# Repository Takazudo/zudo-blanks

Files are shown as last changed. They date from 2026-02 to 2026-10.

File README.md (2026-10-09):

# zudo-blanks

Blank panel PCB designs for modular synthesizers. These are simple PCBs with no electronic components - just blank panels with mounting holes and optional silkscreen artwork.

## Overview

This project contains KiCad PCB designs for blank panels in various HP widths for Eurorack format modular synthesizers. The panels are designed for manufacturing via JLCPCB.

## Documentation

- **Documentation site**: Built with zudo-doc
- **Development**: `cd doc && pnpm install --frozen-lockfile && pnpm dev`
- **URL**: `http://localhost:4321/pj/zblanks/`

## Repository Structure

- `panels/` - All KiCad panel projects (one directory per panel)
- `footprints/` - Shared KiCad footprint library
- `symbols/` - KiCad symbol library (minimal)
- `artwork-resources/` - Source artwork files (AI, SVG)
- `jlcpcb-order-snapshots/` - JLCPCB order history
- `doc/` - zudo-doc documentation site
- `.github/` - GitHub Actions CI/CD

## Workflow

1. Design panel in KiCad (Edge.Cuts outline, mounting holes, silkscreen)
2. Export Gerber files
3. Order from JLCPCB

## Documentation build and deployment

The site is a static zudo-doc export in `doc/dist/`. GitHub Actions installs the pinned pnpm lockfile with Node 22, checks the docs, builds `dist/`, and stages it at `deploy-dir/pj/zblanks/` for the existing Netlify site. Production remains at https://takazudomodular.com/pj/zblanks/.

The migration used `create-zudo-doc@5.26.5` (`pnpm create zudo-doc /tmp/zblanks-zudo-doc-13 --yes --lang en --no-i18n --no-git --no-install --claude-resources`) in a scratch directory. The config keeps the starter defaults except for site identity, base path, repository-scoped Claude resources, navigation, and strict broken-link reporting. `--claude-resources` publishes project `.claude/skills`; it does not install zudo-doc's authoring skills. To roll back, revert the documentation migration commit(s) and redeploy the prior Docusaurus build.

### Published route migration

| Previous URL below `/pj/zblanks/` | New URL | Handling |
| --- | --- | --- |
| `/docs/overview` | `/docs/overview` | Preserved |
| `/docs/overview/project-overview` | same | Preserved by filename |
| `/docs/overview/file-structure` | same | Preserved |
| `/docs/how-to/*`, `/docs/misc`, `/docs/inbox` | same | Preserved |
| `/docs/{overview,how-to,misc,inbox}/index` | `/docs/{section}` | Netlify 301 redirects |
| `/` at the Netlify site root | `/pj/zblanks/` | Netlify 301 redirect |

The catalog, manufacturing, workflow, and Claude sections are new. The final catalog content is maintained with the corresponding panel work.

## Saved PCB art order candidates

[Open the four-series PCB files, previews and order ZIPs](order-packages/four-art-series/current/README.md). The saved ordinary-Git snapshot includes individual, grouped red-ten and split-red six-plus-four alternatives for Coral Vault, Fault Line, Kumiko Void wide and Spider Nest. Choose one order list; prices and factory approval remain pending.

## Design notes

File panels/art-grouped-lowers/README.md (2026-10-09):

# Historical five-series lower-board fabrication packages

For the current four-series order alternatives, use the [fresh package workflow](../../scripts/art-order/README.md). This directory and its records retain the historical five-series selection, including Woven Maze.

These native KiCad projects reproduce the five multi-board lower grids in the
frozen [fabrication policy](../../artwork-resources/pcb-art/manufacturing/policy.json).
They place the verified lower boards in sorted ID, row-major order using
translation only. Every decorative aperture stays on `Edge.Cuts`; each member's
outer rectangle is a `Dwgs.User` score boundary. The panel has one routed outer
profile and 5 mm sacrificial rails on all sides. Unoccupied grid cells contain
no duplicate artwork or drills and are declared waste.

KiCad 10's outline stitcher was sensitive to the initial primitive of three
translated decorative loops. The builder rotates those loops' serialized line
order at recorded witnesses. It retains the exact contour segment multiset;
the verifier compares every native and CAM segment against the source geometry.

| Grid | Cells | Members | Blank cells | Finished sheet (mm) |
| --- | ---: | ---: | ---: | ---: |
| white lead-free HASL | 2 × 4 | 7 | 1 | 212.6 × 387.2 |
| black ENIG | 3 × 2 | 6 | 0 | 313.9 × 198.6 |
| red lead-free HASL | 3 × 4 | 10 | 2 | 313.9 × 387.2 |
| green lead-free HASL | 2 × 2 | 4 | 0 | 212.6 × 198.6 |
| black lead-free HASL | 2 × 4 | 8 | 0 | 212.6 × 387.2 |

The three purple, yellow and blue lower boards are individually routed
singletons. The five black ENIG tops also remain standalone. Their original
native sources and verified issue 16 CAM ZIPs are referenced by the order
manifest; they are not purchased again as part of a scored sheet.

From the repository root, regenerate the native grids:

```sh
uv run --python 3.13 --with shapely==2.1.2 --with pillow \
  python artwork-resources/pcb-art/manufacturing/build_lower_panels.py
```

KiCad 10 is required for native DRC and actual Gerber/Excellon verification.
The output path below is local and ignored. The prior issue 16 path holds the
43 individually verified ZIPs, of which eight are directly orderable here.

```sh
uv run --python 3.13 --with shapely==2.1.2 --with pillow \
  python artwork-resources/pcb-art/manufacturing/verify_lower_panels.py \
  --output /tmp/zudo-blanks-issue17-panel-cam \
  --prior-output /tmp/zudo-blanks-issue16-native-cam-release \
  --kicad-cli /Applications/KiCad/KiCad.app/Contents/MacOS/kicad-cli
```

For a resumed CAM export, `--reuse-drc-reports /path/to/mapping.json` accepts
an exact mapping of all five panel IDs to `nativeBoardSha256`, `reportPath` and
`reportSha256`. The verifier checks each native hash and raw KiCad 10 JSON
report, including its source name, units, severities and clean findings,
before reusing the DRC result. Omitting this option runs fresh DRC.

The build record `lower-panels-native.json` binds source hashes, placements,
score lines and measured clearance. A `null` copper or visible-gold clearance
means that the mask-only group has no corresponding front artwork. The CAM
report binds DRC results and local
ZIP hashes. `lower-panels-order-manifest.json` accounts for 25 complete stacks
of each of the five designs: 43 selected IDs × 25 = 1,075 useful pieces,
75 blank waste cells, and 325 ordered sheets or standalone boards across
13 packages. Hardware totals are 500 screws, 3,800 spacers and 500 nuts.

The `FABRICATION.txt` in each grid ZIP instructs the fabricator to V-score all
full-length `Dwgs.User` lines (exported as `User_Drawings.gbr`), route only
the panel outer edge and decorative apertures from `Edge.Cuts`, and drill the
NPTH Excellon hits. Score lines do not
appear on silkscreen. The published scored-edge tolerance is ±0.4 mm; the
separately drilled mount centers determine stack registration.

**Pending external checks:** factory CAM approval, residual score-web depth,
perforated-sheet handling, actual color/finish availability and quote,
physical stack fit, washer/nut tolerances and usable screw length. Local DRC
and CAM evidence is not a purchase or factory acceptance.

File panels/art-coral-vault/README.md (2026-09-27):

# Coral Vault

Flowing cavities narrow unevenly with depth.

This selected home contains 8 standalone native PCB files. Filenames preserve each original board ID.

The design source and full metadata are in artwork-resources/pcb-art. The selected set uses Revision 5 geometry. These files remain editable handoff boards, not a manufacturing release.

| Layer | Original board ID | Mask | Finish |
| ---: | --- | --- | --- |
| 1 | 03-coral-vault-L01-black-enig-art | black | enig-art |
| 2 | 03-coral-vault-L02-green-mask-only | green | mask-only |
| 3 | 03-coral-vault-L03-purple-mask-only | purple | mask-only |
| 4 | 03-coral-vault-L04-gold-enig-fill | black | enig-fill |
| 5 | 03-coral-vault-L05-red-mask-only | red | mask-only |
| 6 | 03-coral-vault-L06-yellow-mask-only | yellow | mask-only |
| 7 | 03-coral-vault-L07-red-mask-only | red | mask-only |
| 8 | 03-coral-vault-L08-blue-mask-only | blue | mask-only |

The imported records include geometry and independent data checks. No KiCad application DRC/CAM, supplier acceptance, quote, physical fit, or order result is claimed.

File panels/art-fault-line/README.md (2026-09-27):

# Fault Line

An asymmetric canyon has angular and rounded cliffs.

This selected home contains 9 standalone native PCB files. Filenames preserve each original board ID.

The design source and full metadata are in artwork-resources/pcb-art. The selected set uses Revision 5 geometry. These files remain editable handoff boards, not a manufacturing release.

| Layer | Original board ID | Mask | Finish |
| ---: | --- | --- | --- |
| 1 | 13-fault-line-L01-black-enig-art | black | enig-art |
| 2 | 13-fault-line-L02-red-mask-only | red | mask-only |
| 3 | 13-fault-line-L03-black-mask-only | black | mask-only |
| 4 | 13-fault-line-L04-red-mask-only | red | mask-only |
| 5 | 13-fault-line-L05-black-mask-only | black | mask-only |
| 6 | 13-fault-line-L06-red-mask-only | red | mask-only |
| 7 | 13-fault-line-L07-black-mask-only | black | mask-only |
| 8 | 13-fault-line-L08-red-mask-only | red | mask-only |
| 9 | 13-fault-line-L09-black-mask-only | black | mask-only |

The imported records include geometry and independent data checks. No KiCad application DRC/CAM, supplier acceptance, quote, physical fit, or order result is claimed.

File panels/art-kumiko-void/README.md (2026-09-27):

# Kumiko Void — Wide

The selected set uses the expanded asanoha lattice.

This selected home contains 9 standalone native PCB files. Filenames preserve each original board ID.

The design source and full metadata are in artwork-resources/pcb-art. The selected set uses Revision 5 geometry. These files remain editable handoff boards, not a manufacturing release.

| Layer | Original board ID | Mask | Finish |
| ---: | --- | --- | --- |
| 1 | 17-kumiko-void-wide-L01-black-enig-art | black | enig-art |
| 2 | 17-kumiko-void-wide-L02-red-mask-only | red | mask-only |
| 3 | 17-kumiko-void-wide-L03-green-mask-only | green | mask-only |
| 4 | 17-kumiko-void-wide-L04-black-enig-art | black | enig-art |
| 5 | 17-kumiko-void-wide-L05-red-mask-only | red | mask-only |
| 6 | 17-kumiko-void-wide-L06-green-mask-only | green | mask-only |
| 7 | 17-kumiko-void-wide-L07-black-enig-art | black | enig-art |
| 8 | 17-kumiko-void-wide-L08-red-mask-only | red | mask-only |
| 9 | 17-kumiko-void-wide-L09-green-mask-only | green | mask-only |

The imported records include geometry and independent data checks. No KiCad application DRC/CAM, supplier acceptance, quote, physical fit, or order result is claimed.

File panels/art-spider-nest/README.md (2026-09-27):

# Spider Nest

An irregular web extends toward the red bottom layer.

This selected home contains 8 standalone native PCB files. Filenames preserve each original board ID.

The design source and full metadata are in artwork-resources/pcb-art. The selected set uses Revision 5 geometry. These files remain editable handoff boards, not a manufacturing release.

| Layer | Original board ID | Mask | Finish |
| ---: | --- | --- | --- |
| 1 | 01-spider-nest-L01-black-enig-art | black | enig-art |
| 2 | 01-spider-nest-L02-white-mask-only | white | mask-only |
| 3 | 01-spider-nest-L03-gold-enig-fill | black | enig-fill |
| 4 | 01-spider-nest-L04-white-mask-only | white | mask-only |
| 5 | 01-spider-nest-L05-gold-enig-fill | black | enig-fill |
| 6 | 01-spider-nest-L06-white-mask-only | white | mask-only |
| 7 | 01-spider-nest-L07-gold-enig-fill | black | enig-fill |
| 8 | 01-spider-nest-L08-red-mask-only | red | mask-only |

The imported records include geometry and independent data checks. No KiCad application DRC/CAM, supplier acceptance, quote, physical fit, or order result is claimed.

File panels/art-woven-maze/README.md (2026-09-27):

# Woven Maze

The lower layers carry distinct maze paths.

This selected home contains 9 standalone native PCB files. Filenames preserve each original board ID.

The design source and full metadata are in artwork-resources/pcb-art. The selected set uses Revision 5 geometry. These files remain editable handoff boards, not a manufacturing release.

| Layer | Original board ID | Mask | Finish |
| ---: | --- | --- | --- |
| 1 | 18-woven-maze-L01-black-enig-art | black | enig-art |
| 2 | 18-woven-maze-L02-white-mask-only | white | mask-only |
| 3 | 18-woven-maze-L03-black-mask-only | black | mask-only |
| 4 | 18-woven-maze-L04-white-mask-only | white | mask-only |
| 5 | 18-woven-maze-L05-black-mask-only | black | mask-only |
| 6 | 18-woven-maze-L06-white-mask-only | white | mask-only |
| 7 | 18-woven-maze-L07-black-mask-only | black | mask-only |
| 8 | 18-woven-maze-L08-white-mask-only | white | mask-only |
| 9 | 18-woven-maze-L09-black-mask-only | black | mask-only |

The imported records include geometry and independent data checks. No KiCad application DRC/CAM, supplier acceptance, quote, physical fit, or order result is claimed.

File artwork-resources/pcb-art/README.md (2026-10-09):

# PCB Art Source and Revision 5 Handoff

This directory contains the retained source, immutable revision references, compact review evidence, and regeneration tools for the five layered 20HP PCB art panels. The 52 original native board IDs are preserved in pcb/manifest.json and pcb/manifest.csv.

## Current four-series order files

[Open saved KiCad boards, CAM previews and order ZIPs](../../order-packages/four-art-series/current/README.md). This ordinary-Git snapshot preserves the three verified four-series alternatives from PR #24. The source/history below also includes Woven Maze and standard Kumiko; those are excluded from the saved four-series order lists.

## Panel homes

- panels/art-spider-nest contains the selected eight-board Spider Nest set.
- panels/art-coral-vault contains the selected eight-board Coral Vault set.
- panels/art-fault-line contains the selected nine-board Fault Line set.
- panels/art-kumiko-void contains the selected nine-board wide Kumiko set. Its alternatives/standard directory holds all nine standard Kumiko boards as a complete alternative.
- panels/art-woven-maze contains the selected nine-board Woven Maze set.

The default five-design set is 43 boards: 11 ENIG boards and 32 mask-only boards. The nine standard Kumiko boards are a replacement set, not an additional stack. Use the original board IDs from the manifest when referring to any layer.

## Retained source

- preview-source/src and preview-source/scripts generate the canonical Revision 5 geometry and offline 3D viewer.
- preview-source/assets/geometry.json is the current millimetre geometry input. reference-revision3.json and reference-revision4.json are immutable comparison inputs.
- resources/images, resources/reference, and resources/manufacturing-review retain the curated reference and review images once.
- resources/order retains the draft quantity and hardware inputs. Supplier quantities are blank.
- docs-overlay/src/content/docs retains the curated English documentation source. Its public directory is generated during a site migration and is not copied here.
- tools and validation retain the source and compact records needed for local review. The import and geometry-source checks are summarized in validation/import-review.md.
- SOURCE_RESOURCE_MANIFEST.json and SOURCE_SHA256SUMS.txt retain the incoming bundle inventory and checksums. IMPORT_MANIFEST.json maps all 944 listed source files to imported, transformed, deduplicated, or deliberately omitted repository paths.

The bundle checksum file had SHA-256 268e1c329f94d2fa55d3641e0ca32b8698e8117ac91bc8dadb58263f643d39d8. All 944 listed source files matched it at intake. Run python tools/verify_import.py to verify the committed mapping and files. The optional --source-root argument checks the original handoff tree when it is available.

## Regeneration

Python source generation uses Shapely 2.1.2. The preview source also declares Pillow 12.3.0 and npm dependencies in package-lock.json. From the repository root, create the preview environment and build the geometry and offline HTML:

    cd artwork-resources/pcb-art/preview-source
    python3 -m venv .venv
    .venv/bin/python -m pip install -r requirements.txt
    npm ci
    npm run build

To regenerate native boards and vector review outputs, run from the repository root and use a new generated destination:

    python3 artwork-resources/pcb-art/tools/export_kicad.py --input artwork-resources/pcb-art/preview-source/assets/geometry.json --output artwork-resources/pcb-art/generated/rev5-export

The exporter output is a review artifact. It does not replace the committed panel-home boards. Preview HTML, generated vectors, local dependency trees, and generated review output are ignored by Git. Regeneration commands and input hashes are recorded in the manifest and source guides.

The pinned geometry generator completed from the imported source tree. Its raw Kumiko ring ordering differs from the retained JSON, but all 52 serialized board-layer polygons compared geometrically equal. One derived aperture-count statistic changed from 33 to 32 on standard Kumiko layer 5. The imported canonical geometry and validation records were kept unchanged; see validation/import-review.md before treating a future regeneration as a byte-for-byte replacement.

## Review status

The incoming records describe geometry, S-expression, and independent data checks. This import did not run KiCad's native parser, DRC, or CAM. No factory acceptance, quote, physical-fit, or production-order claim is made. Those checks remain pending and must be recorded against the selected files and an actual fabrication process before ordering.

The viewer source includes its upstream three.js MIT notice in preview-source/THIRD_PARTY_NOTICES.txt. No additional standalone license file was present in the incoming bundle; the import manifest preserves provenance without adding a license claim.

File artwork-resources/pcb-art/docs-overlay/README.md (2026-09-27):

# Documentation Overlay Source

src/content/docs and zfb.config.ts are curated English source pages for a future documentation-site migration. The site framework, installed packages, and public asset tree are not part of this import.

The MDX pages link to image, review, and preview assets by their expected public URL. Their source files are retained once under artwork-resources/pcb-art/resources. During a separate site migration, materialize the reviewed images and generated preview HTML into that site's public/assets/pcb-art directory. Do not commit duplicate preview HTML or a second copy of the original resource images into this source bundle.

This task did not initialize, configure, or build the repository documentation site.

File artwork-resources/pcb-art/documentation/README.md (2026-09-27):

# PCB Art Handoff Documentation

The English source notes and the curated documentation pages are retained here and under docs-overlay/src/content/docs. This import does not create or migrate the repository's published documentation site.

Start with the central PCB art README and preview-source/src/CONTRACT.md. Then use the five panel-home READMEs and pcb/manifest.json to locate each original board ID, selected design, layer, color, and finish.

The source bibliography is RESEARCH_SOURCES.json. It records the reference material used by the handoff and should be rechecked before using any vendor capability or software-version detail for current work.

The geometry and native PCB files are editable drafts. The imported evidence does not include native KiCad parser, DRC, CAM, quote, physical-fit, or factory-acceptance results. Add new evidence with its tool, version, input hashes, and scope rather than changing an earlier review into a manufacturing pass.

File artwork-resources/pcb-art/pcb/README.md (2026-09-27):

# Native Board Handoff

The board files are in panels/art-spider-nest, panels/art-coral-vault, panels/art-fault-line, panels/art-kumiko-void, and panels/art-woven-maze. The selected set contains 43 boards using wide Kumiko. Nine standard Kumiko boards are in panels/art-kumiko-void/alternatives/standard and form a complete alternative.

pcb/manifest.json and pcb/manifest.csv preserve the source board IDs and provide the layer, color, finish, board path, export metadata, and original handoff path. The board paths point into repository panel homes. The default local export writes generated vectors under artwork-resources/pcb-art/generated/rev5-export/resources/vector; that generated tree is ignored.

Each file is a standalone KiCad 8+ board with embedded mechanical NPTH footprints. The files are an editable handoff, not a manufacturing release. The source reports geometry and S-expression checks, but native KiCad parsing, DRC, CAM, quote, physical fit, and factory acceptance have not been established here.

The native layers describe routed outlines and apertures on Edge.Cuts, functional holes as NPTH pads, front exposed art on F.Cu/F.Mask, and no back-side art. F.Mask is positive opening geometry. The exact export clearance choice is recorded in the manifest and generator; recheck it against the chosen supplier.

From the repository root, generate a separate review export with:

    python3 artwork-resources/pcb-art/tools/export_kicad.py --input artwork-resources/pcb-art/preview-source/assets/geometry.json --output artwork-resources/pcb-art/generated/rev5-export

The exporter protects existing outputs and accepts an explicit new output directory. It does not update the panel-home boards.

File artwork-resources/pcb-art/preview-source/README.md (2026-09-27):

# Revision 5 Geometry and Offline Viewer

This package retains the five layered PCB art designs in editable Python sources and renders the frozen Revision 5 geometry in an offline three.js viewer.

The canonical geometry is assets/geometry.json. The generator reads the design modules under src/designs, shared geometry in src/build_common.py, finish policy in src/finish_policy.py, and the immutable Revision 3 comparison snapshot in assets/reference-revision3.json. Revision 4 geometry is retained in assets/reference-revision4.json for regression comparison. Do not replace either reference snapshot with regenerated output.

The selected design family contains 43 boards, using wide Kumiko. The complete standard Kumiko alternative adds nine records, for 52 board records total. It is an alternative to the wide set, not an additional production quantity. Revision 5 adds flat copper artwork to the top of each design and Kumiko variant; it preserves the approved Revision 4 physical outlines and lower-layer artwork.

## Build

From this directory:

    npm ci
    npm run build

The viewer build verifies the approved SHA256 of `assets/geometry.json`, leaves frozen geometry and validation untouched, then writes seven self-contained HTML files under ignored `dist/`. It needs Node.js and the locked npm dependencies. The documentation site stages only `dist/index.html`: URL query parameters select each design and Kumiko variant without publishing six duplicate copies.

Regenerating design geometry is a separate, intentional source change. It needs Shapely 2.1.2 and Pillow 12.3.0:

    python3 -m venv .venv
    .venv/bin/python -m pip install -r requirements.txt
    .venv/bin/python scripts/build_geometry.py

Do not replace the frozen geometry merely to refresh the viewer. A geometry change requires a reviewed policy update and fresh native/CAM comparisons.

Do not treat geometry validation or a browser render as KiCad DRC, CAM review, a physical-fit check, or factory acceptance. The selected native and grouped board local checks are recorded under `../manufacturing/`; factory CAM, quote and physical fit remain pending.

Image references from the incoming preview-source/docs directory are retained once under ../resources/images.

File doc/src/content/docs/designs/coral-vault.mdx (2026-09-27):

---
title: "03 Coral Vault"
description: "Design intent, layer sequence, and review points."
sidebar_position: 2
---

<a href="/assets/pcb-art/previews/index.html?design=coral-vault">Open the interactive Revision 5 design preview</a>

Six large flowing cavities and four smaller openings start the view. Walls retreat by varying amounts with depth, and some cavities split as partitions appear. This avoids a repeated scaled-copy effect. The design abstracts cup, shared-wall, and radial-septum forms of colonial coral such as [Favites pentagona](https://www.coralsoftheworld.org/species_factsheets/species_factsheet_summary/favites-pentagona/); it is not a model of one organism.

The top copper spreads cup and radial motifs across the remaining face. Revision 5 adds the gold frame and hole rims. Layer 4 is the only full-gold lower layer. The top opening grew about 62.0% from Revision 3.

## Layering constraints

Combined decorative aperture area decreases with depth, and every deeper aperture remains inside the preceding opening. Hole counts may change. Keep each layer connected and ensure top openings do not extend beyond lower-board material.

## Front-to-back layers

| Layer | Color | Finish |
| ---: | --- | --- |
| 1 | Black | ENIG artwork |
| 2 | Green | Mask-only |
| 3 | Purple | Mask-only |
| 4 | Black with gold | Full ENIG |
| 5 | Red | Mask-only |
| 6 | Yellow | Mask-only |
| 7 | Red | Mask-only |
| 8 | Blue | Mask-only bottom |

## Native boards and evidence

The image below shows all selected layers from **manufacturing-adjusted native KiCad files**. The linked 3D viewer above shows Revision 5 **visual design geometry**. Small local routing and mask corrections mean the two representations are not identical.

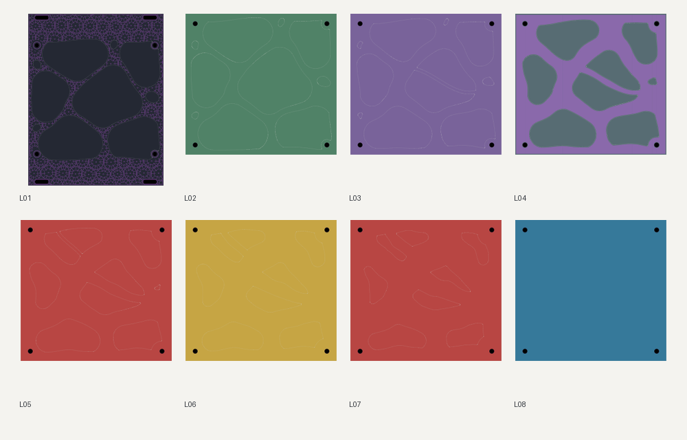
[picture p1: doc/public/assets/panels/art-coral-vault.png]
All selected native KiCad layers for coral vault


| Layer | Native KiCad board |
| ---: | --- |
| 1 | [03-coral-vault-L01-black-enig-art](https://github.com/Takazudo/zudo-blanks/blob/main/panels/art-coral-vault/03-coral-vault-L01-black-enig-art.kicad_pcb) |
| 2 | [03-coral-vault-L02-green-mask-only](https://github.com/Takazudo/zudo-blanks/blob/main/panels/art-coral-vault/03-coral-vault-L02-green-mask-only.kicad_pcb) |
| 3 | [03-coral-vault-L03-purple-mask-only](https://github.com/Takazudo/zudo-blanks/blob/main/panels/art-coral-vault/03-coral-vault-L03-purple-mask-only.kicad_pcb) |
| 4 | [03-coral-vault-L04-gold-enig-fill](https://github.com/Takazudo/zudo-blanks/blob/main/panels/art-coral-vault/03-coral-vault-L04-gold-enig-fill.kicad_pcb) |
| 5 | [03-coral-vault-L05-red-mask-only](https://github.com/Takazudo/zudo-blanks/blob/main/panels/art-coral-vault/03-coral-vault-L05-red-mask-only.kicad_pcb) |
| 6 | [03-coral-vault-L06-yellow-mask-only](https://github.com/Takazudo/zudo-blanks/blob/main/panels/art-coral-vault/03-coral-vault-L06-yellow-mask-only.kicad_pcb) |
| 7 | [03-coral-vault-L07-red-mask-only](https://github.com/Takazudo/zudo-blanks/blob/main/panels/art-coral-vault/03-coral-vault-L07-red-mask-only.kicad_pcb) |
| 8 | [03-coral-vault-L08-blue-mask-only](https://github.com/Takazudo/zudo-blanks/blob/main/panels/art-coral-vault/03-coral-vault-L08-blue-mask-only.kicad_pcb) |

[Project directory](https://github.com/Takazudo/zudo-blanks/tree/main/panels/art-coral-vault) · [Selected package/order manifest](https://github.com/Takazudo/zudo-blanks/blob/main/artwork-resources/pcb-art/manufacturing/lower-panels-order-manifest.json) · [Local native/CAM evidence](https://github.com/Takazudo/zudo-blanks/blob/main/artwork-resources/pcb-art/manufacturing/native-kicad-cam-manifest.json)

Factory CAM review, finish/color availability, quote and physical fit are pending external checks. No purchase or factory acceptance is recorded.

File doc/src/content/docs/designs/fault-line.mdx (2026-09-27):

---
title: "13 Fault Line"
description: "Design intent, layer sequence, and review points."
sidebar_position: 3
---

<a href="/assets/pcb-art/previews/index.html?design=fault-line">Open the interactive Revision 5 design preview</a>

Fault Line is a tall, asymmetric canyon. Its side ledges reach different heights; black layers have angular cliffs while red layers have worn, rounded cliffs. Retreat varies locally. The top opening grew about 38.1% from Revision 3 to Revision 4. Top copper adds terrain lines and narrow fractures, with a Revision 5 frame and hole rims. The lower eight boards are mask-only.

## Keep each layer connected

The left and right portions of every layer must remain connected through its upper and lower bridges. Splitting a layer into separate boards held together by screws would violate the one-PCB-per-layer design.

Opening area decreases with depth and remains nested, but the geometry is not a uniform offset. Keep local changes irregular and check that deep openings do not create floating PCB fragments.

## Front-to-back layers

| Layer | Color | Finish |
| ---: | --- | --- |
| 1 | Black | ENIG artwork |
| 2 | Red | Mask-only |
| 3 | Black | Mask-only |
| 4 | Red | Mask-only |
| 5 | Black | Mask-only |
| 6 | Red | Mask-only |
| 7 | Black | Mask-only |
| 8 | Red | Mask-only |
| 9 | Black | Mask-only bottom |

## Native boards and evidence

The image below shows all selected layers from **manufacturing-adjusted native KiCad files**. The linked 3D viewer above shows Revision 5 **visual design geometry**. Small local routing and mask corrections mean the two representations are not identical.

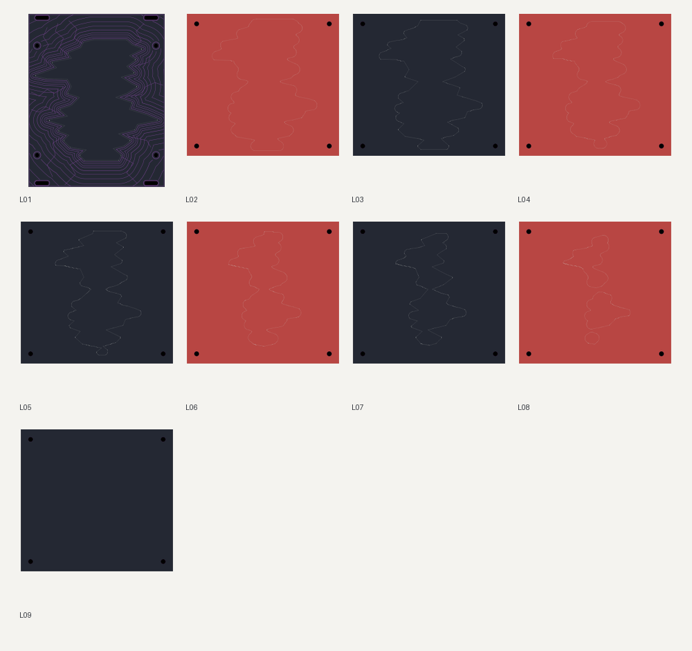
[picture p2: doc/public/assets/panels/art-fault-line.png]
All selected native KiCad layers for fault line


| Layer | Native KiCad board |
| ---: | --- |
| 1 | [13-fault-line-L01-black-enig-art](https://github.com/Takazudo/zudo-blanks/blob/main/panels/art-fault-line/13-fault-line-L01-black-enig-art.kicad_pcb) |
| 2 | [13-fault-line-L02-red-mask-only](https://github.com/Takazudo/zudo-blanks/blob/main/panels/art-fault-line/13-fault-line-L02-red-mask-only.kicad_pcb) |
| 3 | [13-fault-line-L03-black-mask-only](https://github.com/Takazudo/zudo-blanks/blob/main/panels/art-fault-line/13-fault-line-L03-black-mask-only.kicad_pcb) |
| 4 | [13-fault-line-L04-red-mask-only](https://github.com/Takazudo/zudo-blanks/blob/main/panels/art-fault-line/13-fault-line-L04-red-mask-only.kicad_pcb) |
| 5 | [13-fault-line-L05-black-mask-only](https://github.com/Takazudo/zudo-blanks/blob/main/panels/art-fault-line/13-fault-line-L05-black-mask-only.kicad_pcb) |
| 6 | [13-fault-line-L06-red-mask-only](https://github.com/Takazudo/zudo-blanks/blob/main/panels/art-fault-line/13-fault-line-L06-red-mask-only.kicad_pcb) |
| 7 | [13-fault-line-L07-black-mask-only](https://github.com/Takazudo/zudo-blanks/blob/main/panels/art-fault-line/13-fault-line-L07-black-mask-only.kicad_pcb) |
| 8 | [13-fault-line-L08-red-mask-only](https://github.com/Takazudo/zudo-blanks/blob/main/panels/art-fault-line/13-fault-line-L08-red-mask-only.kicad_pcb) |
| 9 | [13-fault-line-L09-black-mask-only](https://github.com/Takazudo/zudo-blanks/blob/main/panels/art-fault-line/13-fault-line-L09-black-mask-only.kicad_pcb) |

[Project directory](https://github.com/Takazudo/zudo-blanks/tree/main/panels/art-fault-line) · [Selected package/order manifest](https://github.com/Takazudo/zudo-blanks/blob/main/artwork-resources/pcb-art/manufacturing/lower-panels-order-manifest.json) · [Local native/CAM evidence](https://github.com/Takazudo/zudo-blanks/blob/main/artwork-resources/pcb-art/manufacturing/native-kicad-cam-manifest.json)

Factory CAM review, finish/color availability, quote and physical fit are pending external checks. No purchase or factory acceptance is recorded.

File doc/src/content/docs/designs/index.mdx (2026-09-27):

---
title: Five Layered Designs
sidebar_position: 2
---

These five projects use 43 selected native boards, with the **wide** Kumiko set. The design previews are interactive Revision 5 visual models. The compact catalog images derive from manufacturing-adjusted native boards. Read each design's complete layer table and native board links before using its files.

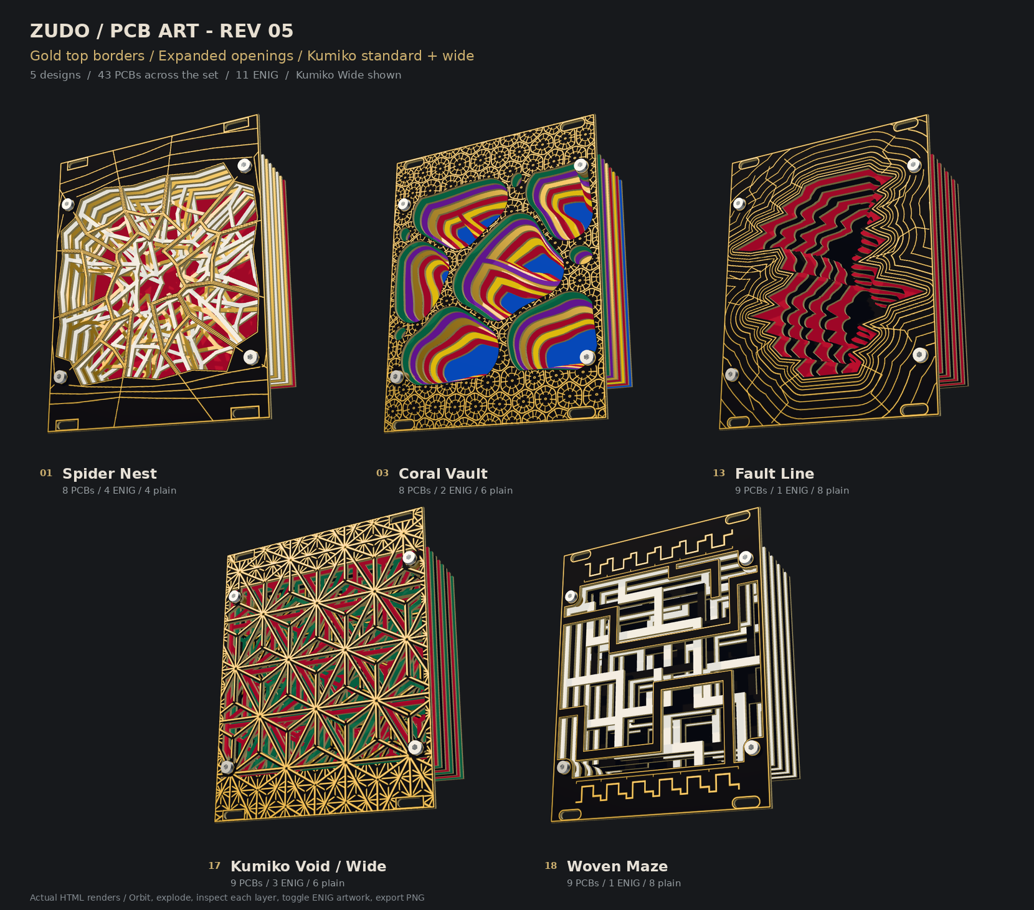
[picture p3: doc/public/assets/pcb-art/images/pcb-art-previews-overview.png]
Five Revision 5 visual concepts


<a href="/assets/pcb-art/previews/index.html">Open the interactive 3D viewer</a> · [Browse all project directories](../catalog/) · [Manufacturing status](../manufacturing/)

<CategoryNav category="designs" />

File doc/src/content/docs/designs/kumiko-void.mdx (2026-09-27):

---
title: "17 Kumiko Void"
description: "Selected wide design, standard alternative, and layer sequence."
sidebar_position: 4
---

<a href="/assets/pcb-art/previews/index.html?design=kumiko-void&amp;variant=wide">Open the interactive Revision 5 design preview</a>

Kumiko combines an asanoha lattice with black, red, and green layers. On black layers 1, 4, and 7, the flat gold and black surfaces create the visual shadow; no raised metal parts are specified. The standard option preserves the earlier opening. The selected wide option extends the same lattice toward the perimeter and increases top opening area by about 43.8% relative to standard.

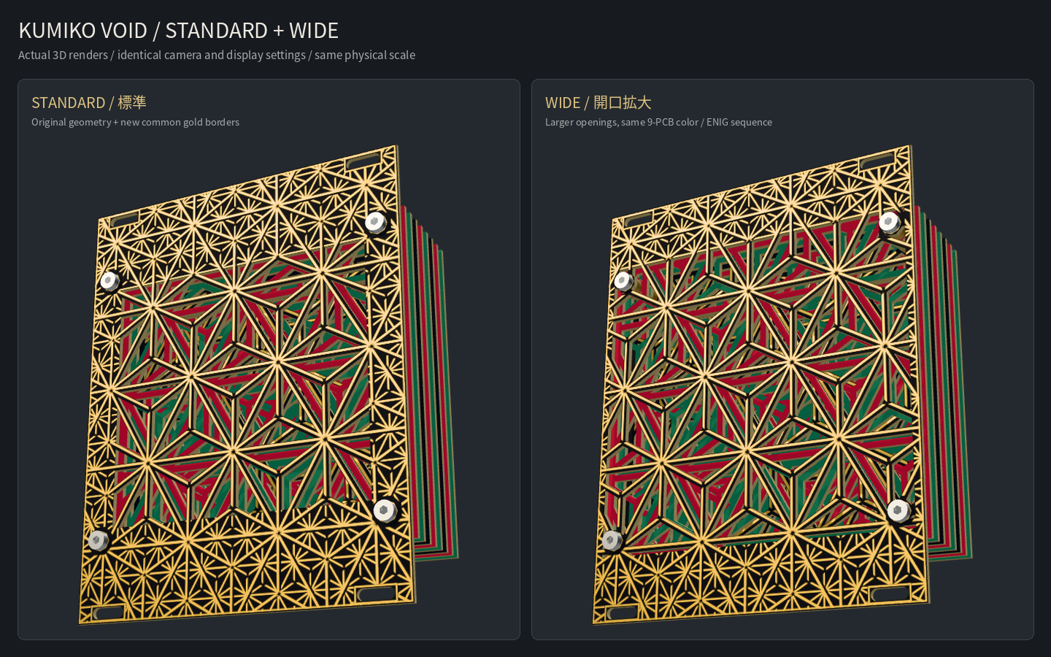
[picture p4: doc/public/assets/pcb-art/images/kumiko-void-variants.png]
Standard and wide opening comparison


<a href="/assets/pcb-art/previews/index.html?design=kumiko-void&amp;variant=standard">Standard (reference only)</a> · <a href="/assets/pcb-art/previews/index.html?design=kumiko-void&amp;variant=wide">Wide (selected)</a>

## Treat the variants as whole sets

The selected set uses wide Kumiko. Its nine standard boards are retained under panels/art-kumiko-void/alternatives/standard. Replace all nine layers together if choosing standard; do not mix layers from the two variants. Revision 5 borders are present on both tops.

## Selected wide and reference standard

The wide nine-board set was locally adapted for the chosen 1.0 mm cutter and checked in native KiCad and CAM. The standard nine-board alternative remains reference-only and was not part of the selected release checks. Do not mix variants within one stack. [Read the policy and indexed corrections](../manufacturing/kumiko-routing.mdx).

## Front-to-back layers

| Layer | Color | Finish |
| ---: | --- | --- |
| 1 | Black | ENIG artwork |
| 2 | Red | Mask-only |
| 3 | Green | Mask-only |
| 4 | Black | ENIG artwork |
| 5 | Red | Mask-only |
| 6 | Green | Mask-only |
| 7 | Black | ENIG artwork |
| 8 | Red | Mask-only |
| 9 | Green | Mask-only bottom |

## Native boards and evidence

The image below shows all selected layers from **manufacturing-adjusted native KiCad files**. The linked 3D viewer above shows Revision 5 **visual design geometry**. Small local routing and mask corrections mean the two representations are not identical.

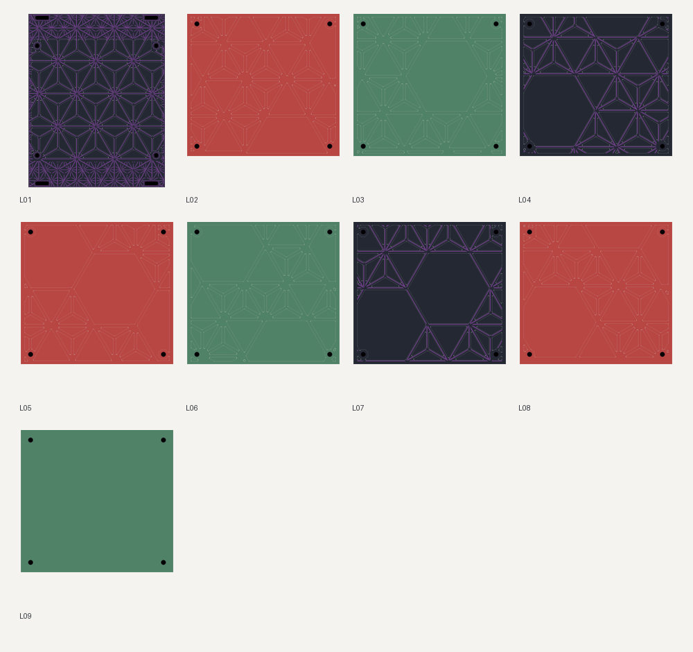
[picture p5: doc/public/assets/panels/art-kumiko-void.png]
All selected native KiCad layers for kumiko void


| Layer | Native KiCad board |
| ---: | --- |
| 1 | [17-kumiko-void-wide-L01-black-enig-art](https://github.com/Takazudo/zudo-blanks/blob/main/panels/art-kumiko-void/17-kumiko-void-wide-L01-black-enig-art.kicad_pcb) |
| 2 | [17-kumiko-void-wide-L02-red-mask-only](https://github.com/Takazudo/zudo-blanks/blob/main/panels/art-kumiko-void/17-kumiko-void-wide-L02-red-mask-only.kicad_pcb) |
| 3 | [17-kumiko-void-wide-L03-green-mask-only](https://github.com/Takazudo/zudo-blanks/blob/main/panels/art-kumiko-void/17-kumiko-void-wide-L03-green-mask-only.kicad_pcb) |
| 4 | [17-kumiko-void-wide-L04-black-enig-art](https://github.com/Takazudo/zudo-blanks/blob/main/panels/art-kumiko-void/17-kumiko-void-wide-L04-black-enig-art.kicad_pcb) |
| 5 | [17-kumiko-void-wide-L05-red-mask-only](https://github.com/Takazudo/zudo-blanks/blob/main/panels/art-kumiko-void/17-kumiko-void-wide-L05-red-mask-only.kicad_pcb) |
| 6 | [17-kumiko-void-wide-L06-green-mask-only](https://github.com/Takazudo/zudo-blanks/blob/main/panels/art-kumiko-void/17-kumiko-void-wide-L06-green-mask-only.kicad_pcb) |
| 7 | [17-kumiko-void-wide-L07-black-enig-art](https://github.com/Takazudo/zudo-blanks/blob/main/panels/art-kumiko-void/17-kumiko-void-wide-L07-black-enig-art.kicad_pcb) |
| 8 | [17-kumiko-void-wide-L08-red-mask-only](https://github.com/Takazudo/zudo-blanks/blob/main/panels/art-kumiko-void/17-kumiko-void-wide-L08-red-mask-only.kicad_pcb) |
| 9 | [17-kumiko-void-wide-L09-green-mask-only](https://github.com/Takazudo/zudo-blanks/blob/main/panels/art-kumiko-void/17-kumiko-void-wide-L09-green-mask-only.kicad_pcb) |

[Project directory](https://github.com/Takazudo/zudo-blanks/tree/main/panels/art-kumiko-void) · [Selected package/order manifest](https://github.com/Takazudo/zudo-blanks/blob/main/artwork-resources/pcb-art/manufacturing/lower-panels-order-manifest.json) · [Local native/CAM evidence](https://github.com/Takazudo/zudo-blanks/blob/main/artwork-resources/pcb-art/manufacturing/native-kicad-cam-manifest.json)

Factory CAM review, finish/color availability, quote and physical fit are pending external checks. No purchase or factory acceptance is recorded.

[Standard nine-board alternative directory — reference only](https://github.com/Takazudo/zudo-blanks/tree/main/panels/art-kumiko-void/alternatives/standard)

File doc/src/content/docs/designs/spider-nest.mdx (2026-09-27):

---
title: "01 Spider Nest"
description: "Design intent, layer sequence, and review points."
sidebar_position: 1
---

<a href="/assets/pcb-art/previews/index.html?design=spider-nest">Open the interactive Revision 5 design preview</a>

The irregular web extends close to the perimeter. Twelve main radial strands reach outward, four of them connected to mounting supports. Cross strands shift between layers, leaving a deep view toward the red bottom. The top copper follows the web outward rather than adding a uniform tiled pattern. Revision 5 adds the shared top frame and hole rims.

The top opening grew about 29.5% from Revision 3 to Revision 4; Revision 5 preserves that physical opening. White layers and the red bottom are mask-only. Layers 3, 5, and 7 show gold using black mask and exposed ENIG.

## Review points

Check thin strand connections, sharp interior corners, support necks, and visibility of the red bottom. A process adaptation should not sever strands or flatten the web by filling openings.

## Front-to-back layers

| Layer | Color | Finish |
| ---: | --- | --- |
| 1 | Black | ENIG artwork |
| 2 | White | Mask-only |
| 3 | Black with gold | Full ENIG |
| 4 | White | Mask-only |
| 5 | Black with gold | Full ENIG |
| 6 | White | Mask-only |
| 7 | Black with gold | Full ENIG |
| 8 | Red | Mask-only bottom |

## Native boards and evidence

The image below shows all selected layers from **manufacturing-adjusted native KiCad files**. The linked 3D viewer above shows Revision 5 **visual design geometry**. Small local routing and mask corrections mean the two representations are not identical.

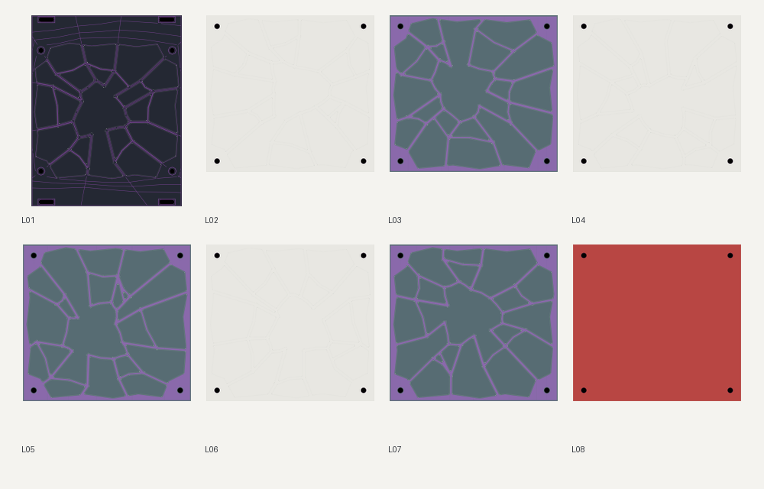
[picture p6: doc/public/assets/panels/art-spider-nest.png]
All selected native KiCad layers for spider nest


| Layer | Native KiCad board |
| ---: | --- |
| 1 | [01-spider-nest-L01-black-enig-art](https://github.com/Takazudo/zudo-blanks/blob/main/panels/art-spider-nest/01-spider-nest-L01-black-enig-art.kicad_pcb) |
| 2 | [01-spider-nest-L02-white-mask-only](https://github.com/Takazudo/zudo-blanks/blob/main/panels/art-spider-nest/01-spider-nest-L02-white-mask-only.kicad_pcb) |
| 3 | [01-spider-nest-L03-gold-enig-fill](https://github.com/Takazudo/zudo-blanks/blob/main/panels/art-spider-nest/01-spider-nest-L03-gold-enig-fill.kicad_pcb) |
| 4 | [01-spider-nest-L04-white-mask-only](https://github.com/Takazudo/zudo-blanks/blob/main/panels/art-spider-nest/01-spider-nest-L04-white-mask-only.kicad_pcb) |
| 5 | [01-spider-nest-L05-gold-enig-fill](https://github.com/Takazudo/zudo-blanks/blob/main/panels/art-spider-nest/01-spider-nest-L05-gold-enig-fill.kicad_pcb) |
| 6 | [01-spider-nest-L06-white-mask-only](https://github.com/Takazudo/zudo-blanks/blob/main/panels/art-spider-nest/01-spider-nest-L06-white-mask-only.kicad_pcb) |
| 7 | [01-spider-nest-L07-gold-enig-fill](https://github.com/Takazudo/zudo-blanks/blob/main/panels/art-spider-nest/01-spider-nest-L07-gold-enig-fill.kicad_pcb) |
| 8 | [01-spider-nest-L08-red-mask-only](https://github.com/Takazudo/zudo-blanks/blob/main/panels/art-spider-nest/01-spider-nest-L08-red-mask-only.kicad_pcb) |

[Project directory](https://github.com/Takazudo/zudo-blanks/tree/main/panels/art-spider-nest) · [Selected package/order manifest](https://github.com/Takazudo/zudo-blanks/blob/main/artwork-resources/pcb-art/manufacturing/lower-panels-order-manifest.json) · [Local native/CAM evidence](https://github.com/Takazudo/zudo-blanks/blob/main/artwork-resources/pcb-art/manufacturing/native-kicad-cam-manifest.json)

Factory CAM review, finish/color availability, quote and physical fit are pending external checks. No purchase or factory acceptance is recorded.

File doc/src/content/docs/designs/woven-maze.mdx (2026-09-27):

---
title: "18 Woven Maze"
description: "Distinct lower-layer paths, colors, and review points."
sidebar_position: 5
---

<a href="/assets/pcb-art/previews/index.html?design=woven-maze">Open the interactive Revision 5 design preview</a>

White and black layers overlap to reveal seven different maze paths below the top. Keep their routes distinct instead of reusing one shifted pattern. Revision 4 spread the routes into a larger region and increased top opening area by about 47.2%. Revision 5 adds a gold frame, hole rims, and top maze artwork. No gold pattern is added to the lower mask-only boards.

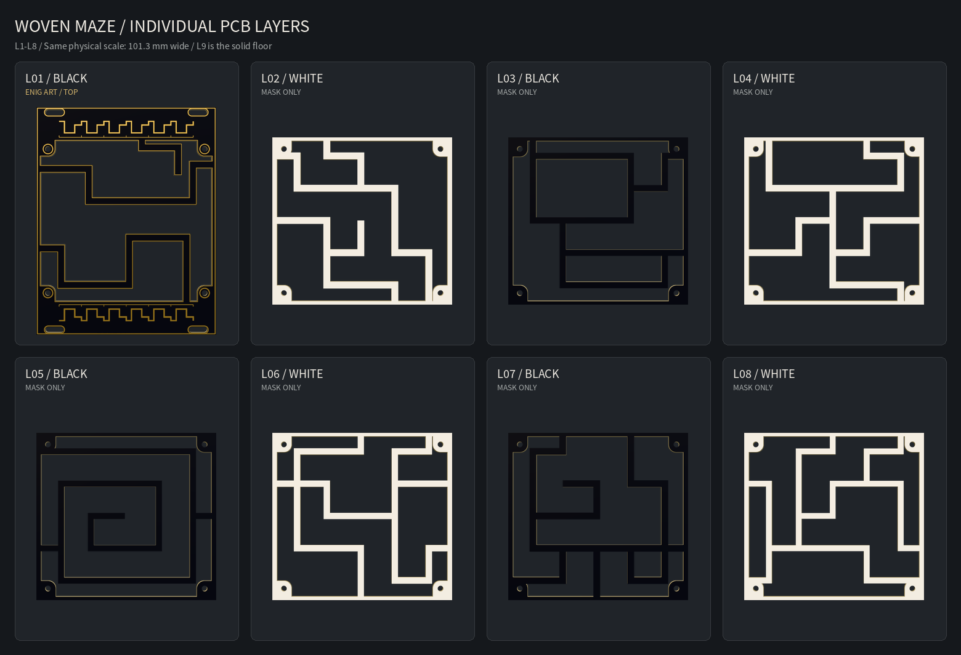
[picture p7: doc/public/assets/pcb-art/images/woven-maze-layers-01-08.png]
Top eight Woven Maze layers


## Review each layer

Use the isolated-layer preview, then return to the assembled view. Check where broad white bands hide black ones and how the windows reveal deeper routes. Every board still needs a connected perimeter and mounting supports.

## Front-to-back layers

| Layer | Color | Finish |
| ---: | --- | --- |
| 1 | Black | ENIG artwork |
| 2 | White | Mask-only |
| 3 | Black | Mask-only |
| 4 | White | Mask-only |
| 5 | Black | Mask-only |
| 6 | White | Mask-only |
| 7 | Black | Mask-only |
| 8 | White | Mask-only |
| 9 | Black | Mask-only bottom |

## Native boards and evidence

The image below shows all selected layers from **manufacturing-adjusted native KiCad files**. The linked 3D viewer above shows Revision 5 **visual design geometry**. Small local routing and mask corrections mean the two representations are not identical.

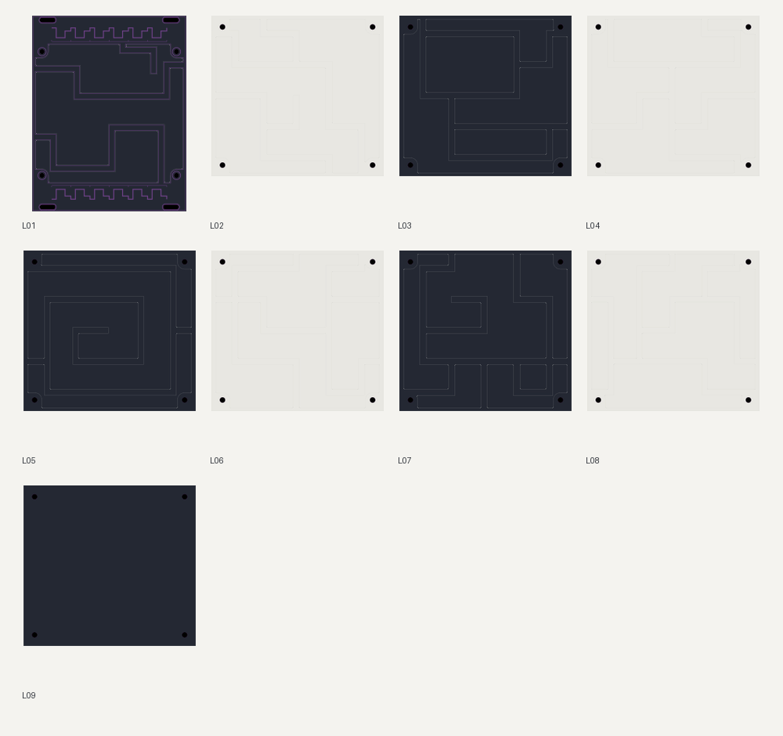
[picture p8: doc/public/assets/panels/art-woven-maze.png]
All selected native KiCad layers for woven maze


| Layer | Native KiCad board |
| ---: | --- |
| 1 | [18-woven-maze-L01-black-enig-art](https://github.com/Takazudo/zudo-blanks/blob/main/panels/art-woven-maze/18-woven-maze-L01-black-enig-art.kicad_pcb) |
| 2 | [18-woven-maze-L02-white-mask-only](https://github.com/Takazudo/zudo-blanks/blob/main/panels/art-woven-maze/18-woven-maze-L02-white-mask-only.kicad_pcb) |
| 3 | [18-woven-maze-L03-black-mask-only](https://github.com/Takazudo/zudo-blanks/blob/main/panels/art-woven-maze/18-woven-maze-L03-black-mask-only.kicad_pcb) |
| 4 | [18-woven-maze-L04-white-mask-only](https://github.com/Takazudo/zudo-blanks/blob/main/panels/art-woven-maze/18-woven-maze-L04-white-mask-only.kicad_pcb) |
| 5 | [18-woven-maze-L05-black-mask-only](https://github.com/Takazudo/zudo-blanks/blob/main/panels/art-woven-maze/18-woven-maze-L05-black-mask-only.kicad_pcb) |
| 6 | [18-woven-maze-L06-white-mask-only](https://github.com/Takazudo/zudo-blanks/blob/main/panels/art-woven-maze/18-woven-maze-L06-white-mask-only.kicad_pcb) |
| 7 | [18-woven-maze-L07-black-mask-only](https://github.com/Takazudo/zudo-blanks/blob/main/panels/art-woven-maze/18-woven-maze-L07-black-mask-only.kicad_pcb) |
| 8 | [18-woven-maze-L08-white-mask-only](https://github.com/Takazudo/zudo-blanks/blob/main/panels/art-woven-maze/18-woven-maze-L08-white-mask-only.kicad_pcb) |
| 9 | [18-woven-maze-L09-black-mask-only](https://github.com/Takazudo/zudo-blanks/blob/main/panels/art-woven-maze/18-woven-maze-L09-black-mask-only.kicad_pcb) |

[Project directory](https://github.com/Takazudo/zudo-blanks/tree/main/panels/art-woven-maze) · [Selected package/order manifest](https://github.com/Takazudo/zudo-blanks/blob/main/artwork-resources/pcb-art/manufacturing/lower-panels-order-manifest.json) · [Local native/CAM evidence](https://github.com/Takazudo/zudo-blanks/blob/main/artwork-resources/pcb-art/manufacturing/native-kicad-cam-manifest.json)

Factory CAM review, finish/color availability, quote and physical fit are pending external checks. No purchase or factory acceptance is recorded.

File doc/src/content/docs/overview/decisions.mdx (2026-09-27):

---
title: "Design Decisions and Revisions"
description: "Decisions to preserve while checking process-specific constraints."
sidebar_position: 2
---

## Decisions to preserve

- The top board is 101.3 × 128.5 mm; lower boards are 101.3 × 94.3 mm.
- Boards are 1.6 mm thick and separated by 3.0 mm spacers. Every layer remains one connected physical PCB.
- The openings reach toward the perimeter; do not reduce the designs to a small centered square.
- The gold outer frame and hole rims appear on top boards only.
- Spider Nest and Kumiko Void use angular decorative outlines. Functional screw holes and slots keep their specified shapes.
- Kumiko gold and black are flat artwork, not raised metal bars.
- Colors and ENIG layers are listed in [the finish table](../engineering/finishes.mdx).

## Kumiko selection

The default set uses wide Kumiko in panels/art-kumiko-void. The nine standard boards in panels/art-kumiko-void/alternatives/standard replace all nine wide boards as a set. Do not mix layers between variants. Both versions share the same color and ENIG sequence.

## Revision history

| Revision | Decision |
| --- | --- |
| Initial concepts | Selected five concepts for layered PCB implementation |
| Finish policy | Removed decorative exposed copper from mask-only boards to limit ENIG use |
| Art revision | Made Woven lower layers distinct and extended motifs across top surfaces |
| Revision 4 | Expanded top openings, made Coral and Fault narrowing irregular, and added wide Kumiko |
| Revision 5 | Added gold borders to every top board and prepared the native-board handoff |

Record the location and size of any process-driven change. Check local edits in the stacked view. Supplier capabilities, prices, physical fit, and final fastener choices remain open for the later review.

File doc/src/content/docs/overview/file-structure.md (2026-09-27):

---
title: Repository Structure
sidebar_position: 3
---

- [`panels/`](https://github.com/Takazudo/zudo-blanks/tree/main/panels) contains the top-level project directories indexed by the [catalog](../catalog/). Simple projects hold one KiCad board; layered art and grouped lower sheets contain multiple boards and may have nested project directories.
- [`artwork-resources/pcb-art/preview-source`](https://github.com/Takazudo/zudo-blanks/tree/main/artwork-resources/pcb-art/preview-source) holds the frozen Revision 5 visual geometry and interactive viewer sources.
- [`artwork-resources/pcb-art/manufacturing`](https://github.com/Takazudo/zudo-blanks/tree/main/artwork-resources/pcb-art/manufacturing) holds the fabrication policy, indexed corrections, local validation, native/CAM and package records.
- [`artwork-resources/pcb-art/resources`](https://github.com/Takazudo/zudo-blanks/tree/main/artwork-resources/pcb-art/resources) holds comparison images, review inputs and order planning sources.
- [`footprints/`](https://github.com/Takazudo/zudo-blanks/tree/main/footprints) and [`symbols/`](https://github.com/Takazudo/zudo-blanks/tree/main/symbols) hold shared KiCad libraries.
- `doc/` is the zudo-doc site. Its `public/assets` tree stages web copies from the canonical source data.
- [`.claude/skills/panel-preview`](https://github.com/Takazudo/zudo-blanks/tree/main/.claude/skills/panel-preview) documents preview maintenance for future panels.

[Panel inventory](../catalog/) · [Source of truth](../engineering/source-of-truth.mdx)

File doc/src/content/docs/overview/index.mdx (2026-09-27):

---
title: Overview
sidebar_position: 1
---

The repository contains blank, decorative, side-frame and layered PCB panels for modular synthesizers. Begin with the [full panel catalog](../catalog/) or the [five layered designs](../designs/). Manufacturing status differs by project; the [current release boundary](../manufacturing/) is recorded for the five new stacks and grouped lower sheets.

<CategoryNav category="overview" />

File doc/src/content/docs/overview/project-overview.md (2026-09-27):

---
title: Project Overview
sidebar_position: 2
---

This repository holds KiCad PCB panels for modular synthesizers. Its [catalog](../catalog/) covers every current project directory: plain blanks and adapters, side frames, Saucer designs, earlier artwork and five newer layered art stacks. The panels are decorative or structural; they contain no active electronic circuit.

The plain and older art directories have varied board geometry, finishes and order histories. Read each native board and any local README before using it; a directory name's HP value is a nominal module width, not a promise that the routed edge measures exactly `HP × 5.08 mm`. The catalog does not assert a common finish or approval state for those historical projects.

## Five layered art designs

The selected set comprises 43 boards: [Spider Nest](../designs/spider-nest.mdx), [Coral Vault](../designs/coral-vault.mdx), [Fault Line](../designs/fault-line.mdx), [Kumiko Void wide](../designs/kumiko-void.mdx) and [Woven Maze](../designs/woven-maze.mdx). Each top is nominally 101.3 × 128.5 mm, and lower boards are shorter to clear the rail regions. The stack has 1.6 mm boards separated by 3.0 mm spacers. Exact slot and support coordinates are in the [engineering dimensions](../engineering/dimensions.mdx).

The 3D viewer shows Revision 5 visual design intent. The selected native boards incorporate local router, copper and mask adjustments. Native KiCad DRC/CAM and grouped sheet checks passed locally; factory CAM, quotes, finish availability and physical fit remain pending. No purchase or manufacturer acceptance is recorded.

<a href="/assets/pcb-art/previews/index.html">Interactive design viewer</a> · [Manufacturing status](../manufacturing/) · [Package plan](../manufacturing/order.mdx)

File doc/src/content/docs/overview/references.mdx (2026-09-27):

---
title: Design and Process References
sidebar_position: 5
---

The original handoff bibliography is retained in [RESEARCH_SOURCES.json](https://github.com/Takazudo/zudo-blanks/blob/main/artwork-resources/pcb-art/documentation/RESEARCH_SOURCES.json), with [third-party notices](https://github.com/Takazudo/zudo-blanks/blob/main/artwork-resources/pcb-art/preview-source/THIRD_PARTY_NOTICES.txt). Source files, comparison images and native KiCad projects retain their repository provenance. Curated web assets are staged copies of those committed sources.

[Strip Mine](https://github.com/Takazudo/zudo-blanks/tree/main/panels/art-strip-mine) supplies the layered-panel predecessor and stack reference. [Favites pentagona](https://www.coralsoftheworld.org/species_factsheets/species_factsheet_summary/favites-pentagona/) and [Smithsonian Ocean's coral overview](https://ocean.si.edu/ocean-life/invertebrates/corals-and-coral-reefs) informed Coral Vault's abstract shapes. Design dimensions and layer sequences come from the local geometry and manifests, not those visual references.

The handoff also cited [KiCad board format](https://dev-docs.kicad.org/en/file-formats/sexpr-pcb/), [KiCad common graphics and pads](https://dev-docs.kicad.org/en/file-formats/sexpr-intro/), [JLCPCB capabilities](https://jlcpcb.com/capabilities/pcb-capabilities), [surface finishes](https://jlcpcb.com/help/article/jlcpcb-surface-finish), and [NPTH design guidance](https://jlcpcb.com/blog/npth-design-guide). The [frozen manufacturing policy](https://github.com/Takazudo/zudo-blanks/blob/main/artwork-resources/pcb-art/manufacturing/README.md) records which process assumptions were chosen after checking official sources. Recheck current supplier rules and obtain a quote before any order; a citation is not acceptance.

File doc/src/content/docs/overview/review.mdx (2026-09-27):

---
title: Review Evidence and Limits
sidebar_position: 4
---

The frozen Revision 5 source includes geometry and native-export screens. Later local work adapted the 43 selected boards for the chosen router and copper/mask rules, ran targeted geometry checks, and checked native KiCad 10 DRC and CAM outputs. Five grouped lower sheets received separate local native/CAM checks. The nine standard Kumiko boards remain unchanged reference designs.

| Evidence | Record |
| --- | --- |
| Visual design geometry and source tests | [Frozen Revision 5 geometry](https://github.com/Takazudo/zudo-blanks/blob/main/artwork-resources/pcb-art/preview-source/assets/geometry.json) and [validation JSON](https://github.com/Takazudo/zudo-blanks/blob/main/artwork-resources/pcb-art/preview-source/assets/validation.json) |
| Chosen local adaptation and indexed deltas | [Policy](https://github.com/Takazudo/zudo-blanks/blob/main/artwork-resources/pcb-art/manufacturing/policy.json) and [candidate ledger](https://github.com/Takazudo/zudo-blanks/blob/main/artwork-resources/pcb-art/manufacturing/indexed-deltas.json) |
| Individual selected native board checks | [KiCad 10 CAM manifest](https://github.com/Takazudo/zudo-blanks/blob/main/artwork-resources/pcb-art/manufacturing/native-kicad-cam-manifest.json) |
| Grouped sheet checks and planned quantities | [Grouped sheet record](https://github.com/Takazudo/zudo-blanks/blob/main/artwork-resources/pcb-art/manufacturing/lower-panels-order-manifest.json) |
| Representative visual comparison | [Before and after views](../manufacturing/comparisons.mdx) |

An erosion screen or a clean KiCad DRC does not prove material strength, supplier process compatibility or physical fit. The exhaustive width certificate remains opt-in and has not passed. Factory CAM, quote, finish availability and physical assembly are pending.

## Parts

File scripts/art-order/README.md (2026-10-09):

# Four-series JLCPCB order candidates

The `four-art-series` profile selects exactly 34 committed native boards: Coral
Vault L01–L08, Fault Line L01–L09, Kumiko Void **wide** L01–L09, and Spider Nest
L01–L08. Each L01 remains a byte-identical, individually routed top. Strip Mine
(already ordered), Woven Maze, standard Kumiko and unrelated designs are excluded.
Historical policy, native boards and order records remain unchanged.

## Build fresh files

Install Python 3.13.7 and Docker, then install `scripts/art-order/requirements.txt`
in an isolated Python environment. The same entry point runs locally and on
GitHub Actions:

```sh
python3.13 -m venv /tmp/art-order-venv
/tmp/art-order-venv/bin/python -m pip install -r scripts/art-order/requirements.txt
ART_ORDER_PYTHON=/tmp/art-order-venv/bin/python \
  bash scripts/art-order/run.sh \
  --profile artwork-resources/pcb-art/manufacturing/order-profiles/four-art-series.json \
  --variant all --output /tmp/four-art-series-run
```

Use a fresh empty output directory under `/tmp` or the checkout. `all` produces
`individual`, `grouped` and `split-red`; each can also be requested alone. The
wrapper checks the pinned Python/dependencies and immutable Linux KiCad 10.0.0 image. Linux KiCad 10.0.0 reported invalid-outline findings on unchanged Spider L07 and Coral L03 sources (Spider L07 also reproduced on 10.0.6). Their DRC-only copies cyclically rotate the serialized segments of each closed contour: every complete primitive line, UUID and coordinate is preserved. The native sources and CAM inputs remain byte-identical to the committed boards. The bundle includes the separate DRC input and its hash; download verification recomputes this exact transformation and checks the unchanged project. The new red layouts also use the existing builder’s exact-segment contour-seam rotation: one Fault L08 aperture in `split-red` and one Fault L06 aperture in `grouped`. These changes preserve legacy generated bytes. No DRC rule, geometry or tolerance is relaxed.
Allow sufficient Docker disk space. It does not use installed KiCad 9, old ZIPs,
or regenerate artwork. Run heavy local batches under your machine's normal heavy
job guard. The CI job has a 60-minute budget, with a 48-minute generation deadline
and five minutes for bundle verification. Failures retain available diagnostics;
a timeout, malformed report or failed check cannot produce a successful bundle.

The individual builder and existing lower builder/verifiers are reused. The
profile builder accepts `--profile`, `--variant`, `--output` and `--evidence-path`;
legacy invocations still use their historical inputs and output paths. The
order entry point scopes individual native DRC/CAM to the 34 selected IDs, then
verifies each grouped native sheet and actual Gerber/Excellon export. Identical
sheets across alternatives reuse only the same run's clean DRC report, bound to
both native and project hashes; CAM is freshly exported for each alternative. Source
board/project hashes, inverse-translated contours/art/mask/drills, score lines,
closed connected sheets and finish groups are checked. The expensive all-boundary
artwork-width certificate remains opt-in and is not a claim of this workflow.

## Choose one alternative

At 25 complete stacks per series:

| Alternative | Order lines | Sheets / standalone units | Useful pieces | Blank cells |
| --- | ---: | ---: | ---: | ---: |
| Individual | 34 | 850 | 850 | 0 |
| Grouped | 12 | 300 | 850 | 50 |
| Split-red | 13 | 325 | 850 | 0 |

Each supplies 100 complete stacks: 100 top pieces and 750 lower pieces. Hardware
for the requested stacks is 400 screws, 3,000 spacers and 400 nuts. Existing
fastener size and fit assumptions remain subject to physical confirmation.

| Lower group | Grid, columns × rows | Sheet dimensions, mm | Members |
| --- | --- | --- | ---: |
| White HASL | 1 × 3 | 111.3 × 292.9 | 3 |
| Black ENIG | 3 × 2 | 313.9 × 198.6 | 6 |
| Green HASL | 2 × 2 | 212.6 × 198.6 | 4 |
| Black HASL | 2 × 2 | 212.6 × 198.6 | 4 |
| Red, grouped | 3 × 4 | 313.9 × 387.2 | 10, plus 2 blank cells |
| Red, split six | 2 × 3 | 212.6 × 292.9 | 6 |
| Red, split Fault Line | 2 × 2 | 212.6 × 198.6 | 4 |

Purple, yellow and blue remain standalone 101.3 × 94.3 mm lower boards. HASL
means lead-free HASL. Black HASL and black ENIG remain separate. The red six-member
sheet contains Spider L08, Coral L05/L07 and Kumiko wide L02/L05/L08; the four-member
sheet contains Fault L02/L04/L06/L08. The split is the preferred compact candidate
for quotation; no lower price is established. Its combined gross area is
1,044.9290 cm² versus 1,215.4208 cm² for the ten-member sheet. Blank-cell counts
exclude sacrificial rails and routed cutout material.

Change `series.<name>.stacks` in the profile to recalculate supply. For each sheet,
the smallest configured `supplierQuantities` value covering the highest member
demand is chosen. Each member occurs once per sheet. The same rounding applies to
standalone boards. The configured quantity choices are planning inputs; confirm
them in the dated supplier quote. Unsupported demand fails rather than guessing.
Every order manifest lists per-ID demand, supply and surplus, per-series complete
stack yield, requested hardware and each package's copies/design count. This is a
deterministic calculation, not an optimizer.

## Inspect and download

A successful bundle contains:

- `variants/<variant>/ORDER.md` and `order.json`: the **only** purchase list for
  that alternative, including relative ZIP references, dimensions and settings.
- `sources/`: unchanged source boards/projects; `variants/*/native/`: editable
  grouped boards/projects, fabrication instructions. Placement records are in `variants/*/native-panels.json`.
- `individual-cam/`, `variants/*/cam/`: fresh native DRC reports, CLI logs and CAM.
- `previews/` and variant PNGs: actual CAM front views and scores; nominal side
  elevations show layer order/spacing and are not physical-fit or finish evidence.
- `QUOTE-COMPARISON.md`, `receipt.json`, `inputs/`, `logs/`, `SHA256SUMS`.

**Never buy every ZIP in a multi-variant bundle.** Individual lower exports are
baseline/reference files when choosing either grouped alternative.

PR checks run on the checked-out merge commit and record `source_commit`, head
and base SHAs separately. Manual dispatch becomes available once the workflow is
on the default branch; it selects the checked-in profile and alternative. Runs
never deploy, push source changes or place orders. Manual requests have unique
concurrency groups; newer PR revisions may cancel superseded checks.

Use the exact successful run ID and artifact name displayed on that run; do not
select an unspecified latest artifact. Full bundles are uploaded only by manual dispatch with `upload_bundle` enabled,
and expire after 3 days. PR runs still build and verify but do not upload complete
bundles. Failure diagnostics expire after 3 days:

```sh
gh run view RUN_ID --repo Takazudo/zudo-blanks
mkdir /tmp/four-art-series-downloaded
gh run download RUN_ID --repo Takazudo/zudo-blanks \
  --name art-order-four-art-series-all-RUN_ID-ATTEMPT \
  --dir /tmp/four-art-series-downloaded
ART_ORDER_PYTHON=/tmp/art-order-venv/bin/python \
  bash scripts/art-order/run.sh --verify-bundle /tmp/four-art-series-downloaded \
  --expected-source SOURCE_MERGE_SHA --expected-run-id RUN_ID
```

The download verifier requires the pinned Python dependencies but not Docker. It
checks the complete checksum inventory, bundled source/project/profile hashes,
relative paths, raw DRC identity, panel geometry/placements, package ZIP bytes and
recomputed order accounting. Keep the bundle intact; later relevant source or
profile edits require a fresh build. Use the PR's documented tested merge SHA as
`SOURCE_MERGE_SHA`, not the head SHA.

## Fabrication and external checks

All boards retain FR-4, 1.6 mm, two copper layers, 1 oz and their original mask and
finish, with no silkscreen, plated holes or back copper. Groups use 5 mm rails and
translation only. Decorative apertures are routed `Edge.Cuts`; full-span scores
are exclusively `Dwgs.User`/`User_Drawings` Gerbers, never silk or routed cuts.
The policy keeps at least 0.50 mm copper, 0.55 mm visible-gold and 1.0 mm
aperture/support-disk score clearance, with existing numerical tolerances.
Scored edges carry the recorded ±0.4 mm tolerance; separately drilled mounts
provide stack registration. Top perimeters, rail slots and cosmetic edges remain
routed, never scored or tabbed.

Actual dated prices are **unknown**, including engineering/design, routing/scoring,
ENIG, panel-area, shipping and tax charges. Compare the same requested quantity
with constant top cost. Fewer order lines/sheets do not prove savings. Factory
CAM/scoring and residual web approval, depanelization support of perforated
sheets, side-edge appearance, color/finish availability and physical fastener/stack
fit remain pending. Local native/CAM verification is not factory approval.

## Ordinary Git storage

The [current saved snapshot](../../order-packages/four-art-series/current/README.md)
contains all three alternatives, directly openable PCB/project files, actual CAM
previews, individual order ZIPs and purchase lists. It is ordinary Git, not LFS.
`panels/art-grouped-lowers` remains the historical five-series set.

Raw CAM duplicated inside order ZIPs is omitted from the physical snapshot.
`retention.json` maps each omitted CAM file to an unchanged ZIP entry. Original
KiCad local window settings are encoded in the mapping; newly created local editor
settings, locks and backups are ignored during retained-snapshot verification. All other
original evidence and `SHA256SUMS` are retained. Verification restores the complete
original bundle into a temporary directory, checks every original byte, then runs
the existing native partition, membership, quantity, DRC, package and provenance
verification. It needs the pinned Python environment above, but no Docker or
network. Temporary reconstructed files are removed automatically.

From the repository root:

```sh
/tmp/art-order-venv/bin/python artwork-resources/pcb-art/manufacturing/retain_order_bundle.py \
  --verify-saved order-packages/four-art-series/current \
  --expected-source 27481603195bb1318a0086d119294a5725dd36a0 \
  --expected-run-id 37833323671
```

To update, first generate a fresh `--variant all` bundle into
`artwork-resources/pcb-art/generated/four-art-series-RUN_ID` (ignored), or download
an explicitly selected successful manual run into a fresh temporary directory.
Verify it against its tested source commit and run ID. Then retain it into a new,
empty staging directory; never mix runs or overwrite a snapshot in place:

```sh
/tmp/art-order-venv/bin/python artwork-resources/pcb-art/manufacturing/retain_order_bundle.py \
  --retain /tmp/four-art-series-downloaded \
  --output artwork-resources/pcb-art/generated/retention-candidate \
  --expected-source TESTED_SOURCE_SHA --expected-run-id RUN_ID
```

Review the generated OPEN tables, all variants, provenance and sizes. The tool
rejects a retained file at or above 95 MiB before it can be committed. After review,
replace `order-packages/four-art-series/current` as one complete set on a feature
branch, update the expected source/run in this document and the dedicated workflow,
rerun saved verification, and commit the change through a PR. Git history preserves
prior snapshots; do not add another timestamped copy or rewrite history. Do not
commit the outer Actions archive or the ignored staging/full bundle. No automated
job writes or pushes these files. Temporary Actions storage is optional transport,
not the authoritative saved copy; no existing artifact is deleted by this change.

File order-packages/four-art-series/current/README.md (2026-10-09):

# Four-series saved order candidates

Open the boards directly in KiCad PCB Editor, with their adjacent `.kicad_pro` files. No artifact download, Docker, or generation is needed to inspect this snapshot.

| Alternative | Direct PCB / preview / ZIP links | Purchase list | Order lines |
| --- | --- | --- | ---: |
| Individual: all 34 boards separate | [Open individual](OPEN-individual.md) | [ORDER](bundle/variants/individual/ORDER.md) | 34 |
| Grouped: red ten, 3 × 4 with two blank cells | [Open grouped](OPEN-grouped.md) | [ORDER](bundle/variants/grouped/ORDER.md) | 12 |
| Split-red: six plus four, no blank cells | [Open split-red](OPEN-split-red.md) | [ORDER](bundle/variants/split-red/ORDER.md) | 13 |

Coral Vault, Fault Line, Kumiko Void **wide**, and Spider Nest: 34 original boards, four standalone tops and 30 lowers. Strip Mine, Woven Maze and standard Kumiko are excluded. Groups match **both color and finish**; black ENIG and black lead-free HASL are separate. Purple/yellow/blue lowers remain standalone. The six-red sheet contains Spider L08, Coral L05/L07 and Kumiko L02/L05/L08; the four-red sheet contains Fault L02/L04/L06/L08.

Each alternative supplies 25 stacks per series. Choose **one** purchase list, never every ZIP in this directory. [Quote comparison](bundle/QUOTE-COMPARISON.md) · [Nominal stack sides](bundle/previews/nominal-stack-sides.png). Prices are unknown; local verification is not factory CAM/scoring approval or physical-fit confirmation. Existing FR-4, 1.6 mm, two copper layers, 1 oz, routing, scores and finish conditions are unchanged.

## Provenance and storage

- Original run: https://github.com/Takazudo/zudo-blanks/actions/runs/37833323671
- Tested source commit: `27481603195bb1318a0086d119294a5725dd36a0` (the tested PR merge, not the later main merge).
- [Original receipt](bundle/receipt.json), [original checksum inventory](bundle/SHA256SUMS), [retention mapping](retention.json).
- All 34 source boards/projects, both grouped native alternatives, order ZIPs, previews, settings and verification evidence remain in ordinary Git. No LFS or outer artifact ZIP.
- Original disposable KiCad local settings are encoded in the retention mapping, so opening a PCB does not modify tracked window settings. New local editor state and backups are ignored. Duplicate raw CAM bytes are restored from the unchanged order ZIPs for verification. `bundle/SHA256SUMS` describes the **restored full bundle**, not just the retained physical files. Every restored byte must match it. No native geometry or order ZIP is regenerated during retention.
- Stored bundle: 341,059,898 bytes in 601 files; original bundle: 522,195,553 bytes. Largest retained file: 52,841,655 bytes.

See [the storage/update procedure](../../../scripts/art-order/README.md#ordinary-git-storage) for verification and replacement. Treat this as a frozen snapshot until a newly verified bundle is explicitly retained and reviewed.

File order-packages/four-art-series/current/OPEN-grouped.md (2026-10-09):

# Open grouped

[Order quantities and settings](bundle/variants/grouped/ORDER.md) · [All alternatives](README.md)

Choose only one alternative. Open PCB files in KiCad PCB Editor; upload the listed ZIPs to JLCPCB.

| Package | Color / finish | KiCad PCB | CAM preview | Order ZIP |
| --- | --- | --- | --- | --- |
| lower-panel-white-hasl | white / lead-free HASL | [PCB](bundle/variants/grouped/native/lower-panel-white-hasl/lower-panel-white-hasl.kicad_pcb) | [Preview](bundle/variants/grouped/lower-panel-white-hasl.png) | [ZIP](bundle/variants/grouped/cam/lower-panel-white-hasl.zip) |
| lower-panel-black-enig | black / ENIG | [PCB](bundle/variants/grouped/native/lower-panel-black-enig/lower-panel-black-enig.kicad_pcb) | [Preview](bundle/variants/grouped/lower-panel-black-enig.png) | [ZIP](bundle/variants/grouped/cam/lower-panel-black-enig.zip) |
| lower-panel-red-hasl | red / lead-free HASL | [PCB](bundle/variants/grouped/native/lower-panel-red-hasl/lower-panel-red-hasl.kicad_pcb) | [Preview](bundle/variants/grouped/lower-panel-red-hasl.png) | [ZIP](bundle/variants/grouped/cam/lower-panel-red-hasl.zip) |
| lower-panel-green-hasl | green / lead-free HASL | [PCB](bundle/variants/grouped/native/lower-panel-green-hasl/lower-panel-green-hasl.kicad_pcb) | [Preview](bundle/variants/grouped/lower-panel-green-hasl.png) | [ZIP](bundle/variants/grouped/cam/lower-panel-green-hasl.zip) |
| 03-coral-vault-L03-purple-mask-only | purple / lead-free HASL | [PCB](bundle/sources/panels/art-coral-vault/03-coral-vault-L03-purple-mask-only.kicad_pcb) | [Preview](bundle/previews/03-coral-vault-L03-purple-mask-only.png) | [ZIP](bundle/packages/03-coral-vault-L03-purple-mask-only.zip) |
| 03-coral-vault-L06-yellow-mask-only | yellow / lead-free HASL | [PCB](bundle/sources/panels/art-coral-vault/03-coral-vault-L06-yellow-mask-only.kicad_pcb) | [Preview](bundle/previews/03-coral-vault-L06-yellow-mask-only.png) | [ZIP](bundle/packages/03-coral-vault-L06-yellow-mask-only.zip) |
| 03-coral-vault-L08-blue-mask-only | blue / lead-free HASL | [PCB](bundle/sources/panels/art-coral-vault/03-coral-vault-L08-blue-mask-only.kicad_pcb) | [Preview](bundle/previews/03-coral-vault-L08-blue-mask-only.png) | [ZIP](bundle/packages/03-coral-vault-L08-blue-mask-only.zip) |
| lower-panel-black-hasl | black / lead-free HASL | [PCB](bundle/variants/grouped/native/lower-panel-black-hasl/lower-panel-black-hasl.kicad_pcb) | [Preview](bundle/variants/grouped/lower-panel-black-hasl.png) | [ZIP](bundle/variants/grouped/cam/lower-panel-black-hasl.zip) |
| 01-spider-nest-L01-black-enig-art | black / ENIG | [PCB](bundle/sources/panels/art-spider-nest/01-spider-nest-L01-black-enig-art.kicad_pcb) | [Preview](bundle/previews/01-spider-nest-L01-black-enig-art.png) | [ZIP](bundle/packages/01-spider-nest-L01-black-enig-art.zip) |
| 03-coral-vault-L01-black-enig-art | black / ENIG | [PCB](bundle/sources/panels/art-coral-vault/03-coral-vault-L01-black-enig-art.kicad_pcb) | [Preview](bundle/previews/03-coral-vault-L01-black-enig-art.png) | [ZIP](bundle/packages/03-coral-vault-L01-black-enig-art.zip) |
| 13-fault-line-L01-black-enig-art | black / ENIG | [PCB](bundle/sources/panels/art-fault-line/13-fault-line-L01-black-enig-art.kicad_pcb) | [Preview](bundle/previews/13-fault-line-L01-black-enig-art.png) | [ZIP](bundle/packages/13-fault-line-L01-black-enig-art.zip) |
| 17-kumiko-void-wide-L01-black-enig-art | black / ENIG | [PCB](bundle/sources/panels/art-kumiko-void/17-kumiko-void-wide-L01-black-enig-art.kicad_pcb) | [Preview](bundle/previews/17-kumiko-void-wide-L01-black-enig-art.png) | [ZIP](bundle/packages/17-kumiko-void-wide-L01-black-enig-art.zip) |

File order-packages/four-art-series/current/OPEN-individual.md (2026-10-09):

# Open individual

[Order quantities and settings](bundle/variants/individual/ORDER.md) · [All alternatives](README.md)

Choose only one alternative. Open PCB files in KiCad PCB Editor; upload the listed ZIPs to JLCPCB.

| Package | Color / finish | KiCad PCB | CAM preview | Order ZIP |
| --- | --- | --- | --- | --- |
| 01-spider-nest-L01-black-enig-art | black / ENIG | [PCB](bundle/sources/panels/art-spider-nest/01-spider-nest-L01-black-enig-art.kicad_pcb) | [Preview](bundle/previews/01-spider-nest-L01-black-enig-art.png) | [ZIP](bundle/packages/01-spider-nest-L01-black-enig-art.zip) |
| 01-spider-nest-L02-white-mask-only | white / lead-free HASL | [PCB](bundle/sources/panels/art-spider-nest/01-spider-nest-L02-white-mask-only.kicad_pcb) | [Preview](bundle/previews/01-spider-nest-L02-white-mask-only.png) | [ZIP](bundle/packages/01-spider-nest-L02-white-mask-only.zip) |
| 01-spider-nest-L03-gold-enig-fill | black / ENIG | [PCB](bundle/sources/panels/art-spider-nest/01-spider-nest-L03-gold-enig-fill.kicad_pcb) | [Preview](bundle/previews/01-spider-nest-L03-gold-enig-fill.png) | [ZIP](bundle/packages/01-spider-nest-L03-gold-enig-fill.zip) |
| 01-spider-nest-L04-white-mask-only | white / lead-free HASL | [PCB](bundle/sources/panels/art-spider-nest/01-spider-nest-L04-white-mask-only.kicad_pcb) | [Preview](bundle/previews/01-spider-nest-L04-white-mask-only.png) | [ZIP](bundle/packages/01-spider-nest-L04-white-mask-only.zip) |
| 01-spider-nest-L05-gold-enig-fill | black / ENIG | [PCB](bundle/sources/panels/art-spider-nest/01-spider-nest-L05-gold-enig-fill.kicad_pcb) | [Preview](bundle/previews/01-spider-nest-L05-gold-enig-fill.png) | [ZIP](bundle/packages/01-spider-nest-L05-gold-enig-fill.zip) |
| 01-spider-nest-L06-white-mask-only | white / lead-free HASL | [PCB](bundle/sources/panels/art-spider-nest/01-spider-nest-L06-white-mask-only.kicad_pcb) | [Preview](bundle/previews/01-spider-nest-L06-white-mask-only.png) | [ZIP](bundle/packages/01-spider-nest-L06-white-mask-only.zip) |
| 01-spider-nest-L07-gold-enig-fill | black / ENIG | [PCB](bundle/sources/panels/art-spider-nest/01-spider-nest-L07-gold-enig-fill.kicad_pcb) | [Preview](bundle/previews/01-spider-nest-L07-gold-enig-fill.png) | [ZIP](bundle/packages/01-spider-nest-L07-gold-enig-fill.zip) |
| 01-spider-nest-L08-red-mask-only | red / lead-free HASL | [PCB](bundle/sources/panels/art-spider-nest/01-spider-nest-L08-red-mask-only.kicad_pcb) | [Preview](bundle/previews/01-spider-nest-L08-red-mask-only.png) | [ZIP](bundle/packages/01-spider-nest-L08-red-mask-only.zip) |
| 03-coral-vault-L01-black-enig-art | black / ENIG | [PCB](bundle/sources/panels/art-coral-vault/03-coral-vault-L01-black-enig-art.kicad_pcb) | [Preview](bundle/previews/03-coral-vault-L01-black-enig-art.png) | [ZIP](bundle/packages/03-coral-vault-L01-black-enig-art.zip) |
| 03-coral-vault-L02-green-mask-only | green / lead-free HASL | [PCB](bundle/sources/panels/art-coral-vault/03-coral-vault-L02-green-mask-only.kicad_pcb) | [Preview](bundle/previews/03-coral-vault-L02-green-mask-only.png) | [ZIP](bundle/packages/03-coral-vault-L02-green-mask-only.zip) |
| 03-coral-vault-L03-purple-mask-only | purple / lead-free HASL | [PCB](bundle/sources/panels/art-coral-vault/03-coral-vault-L03-purple-mask-only.kicad_pcb) | [Preview](bundle/previews/03-coral-vault-L03-purple-mask-only.png) | [ZIP](bundle/packages/03-coral-vault-L03-purple-mask-only.zip) |
| 03-coral-vault-L04-gold-enig-fill | black / ENIG | [PCB](bundle/sources/panels/art-coral-vault/03-coral-vault-L04-gold-enig-fill.kicad_pcb) | [Preview](bundle/previews/03-coral-vault-L04-gold-enig-fill.png) | [ZIP](bundle/packages/03-coral-vault-L04-gold-enig-fill.zip) |
| 03-coral-vault-L05-red-mask-only | red / lead-free HASL | [PCB](bundle/sources/panels/art-coral-vault/03-coral-vault-L05-red-mask-only.kicad_pcb) | [Preview](bundle/previews/03-coral-vault-L05-red-mask-only.png) | [ZIP](bundle/packages/03-coral-vault-L05-red-mask-only.zip) |
| 03-coral-vault-L06-yellow-mask-only | yellow / lead-free HASL | [PCB](bundle/sources/panels/art-coral-vault/03-coral-vault-L06-yellow-mask-only.kicad_pcb) | [Preview](bundle/previews/03-coral-vault-L06-yellow-mask-only.png) | [ZIP](bundle/packages/03-coral-vault-L06-yellow-mask-only.zip) |
| 03-coral-vault-L07-red-mask-only | red / lead-free HASL | [PCB](bundle/sources/panels/art-coral-vault/03-coral-vault-L07-red-mask-only.kicad_pcb) | [Preview](bundle/previews/03-coral-vault-L07-red-mask-only.png) | [ZIP](bundle/packages/03-coral-vault-L07-red-mask-only.zip) |
| 03-coral-vault-L08-blue-mask-only | blue / lead-free HASL | [PCB](bundle/sources/panels/art-coral-vault/03-coral-vault-L08-blue-mask-only.kicad_pcb) | [Preview](bundle/previews/03-coral-vault-L08-blue-mask-only.png) | [ZIP](bundle/packages/03-coral-vault-L08-blue-mask-only.zip) |
| 13-fault-line-L01-black-enig-art | black / ENIG | [PCB](bundle/sources/panels/art-fault-line/13-fault-line-L01-black-enig-art.kicad_pcb) | [Preview](bundle/previews/13-fault-line-L01-black-enig-art.png) | [ZIP](bundle/packages/13-fault-line-L01-black-enig-art.zip) |
| 13-fault-line-L02-red-mask-only | red / lead-free HASL | [PCB](bundle/sources/panels/art-fault-line/13-fault-line-L02-red-mask-only.kicad_pcb) | [Preview](bundle/previews/13-fault-line-L02-red-mask-only.png) | [ZIP](bundle/packages/13-fault-line-L02-red-mask-only.zip) |
| 13-fault-line-L03-black-mask-only | black / lead-free HASL | [PCB](bundle/sources/panels/art-fault-line/13-fault-line-L03-black-mask-only.kicad_pcb) | [Preview](bundle/previews/13-fault-line-L03-black-mask-only.png) | [ZIP](bundle/packages/13-fault-line-L03-black-mask-only.zip) |
| 13-fault-line-L04-red-mask-only | red / lead-free HASL | [PCB](bundle/sources/panels/art-fault-line/13-fault-line-L04-red-mask-only.kicad_pcb) | [Preview](bundle/previews/13-fault-line-L04-red-mask-only.png) | [ZIP](bundle/packages/13-fault-line-L04-red-mask-only.zip) |
| 13-fault-line-L05-black-mask-only | black / lead-free HASL | [PCB](bundle/sources/panels/art-fault-line/13-fault-line-L05-black-mask-only.kicad_pcb) | [Preview](bundle/previews/13-fault-line-L05-black-mask-only.png) | [ZIP](bundle/packages/13-fault-line-L05-black-mask-only.zip) |
| 13-fault-line-L06-red-mask-only | red / lead-free HASL | [PCB](bundle/sources/panels/art-fault-line/13-fault-line-L06-red-mask-only.kicad_pcb) | [Preview](bundle/previews/13-fault-line-L06-red-mask-only.png) | [ZIP](bundle/packages/13-fault-line-L06-red-mask-only.zip) |
| 13-fault-line-L07-black-mask-only | black / lead-free HASL | [PCB](bundle/sources/panels/art-fault-line/13-fault-line-L07-black-mask-only.kicad_pcb) | [Preview](bundle/previews/13-fault-line-L07-black-mask-only.png) | [ZIP](bundle/packages/13-fault-line-L07-black-mask-only.zip) |
| 13-fault-line-L08-red-mask-only | red / lead-free HASL | [PCB](bundle/sources/panels/art-fault-line/13-fault-line-L08-red-mask-only.kicad_pcb) | [Preview](bundle/previews/13-fault-line-L08-red-mask-only.png) | [ZIP](bundle/packages/13-fault-line-L08-red-mask-only.zip) |
| 13-fault-line-L09-black-mask-only | black / lead-free HASL | [PCB](bundle/sources/panels/art-fault-line/13-fault-line-L09-black-mask-only.kicad_pcb) | [Preview](bundle/previews/13-fault-line-L09-black-mask-only.png) | [ZIP](bundle/packages/13-fault-line-L09-black-mask-only.zip) |
| 17-kumiko-void-wide-L01-black-enig-art | black / ENIG | [PCB](bundle/sources/panels/art-kumiko-void/17-kumiko-void-wide-L01-black-enig-art.kicad_pcb) | [Preview](bundle/previews/17-kumiko-void-wide-L01-black-enig-art.png) | [ZIP](bundle/packages/17-kumiko-void-wide-L01-black-enig-art.zip) |
| 17-kumiko-void-wide-L02-red-mask-only | red / lead-free HASL | [PCB](bundle/sources/panels/art-kumiko-void/17-kumiko-void-wide-L02-red-mask-only.kicad_pcb) | [Preview](bundle/previews/17-kumiko-void-wide-L02-red-mask-only.png) | [ZIP](bundle/packages/17-kumiko-void-wide-L02-red-mask-only.zip) |
| 17-kumiko-void-wide-L03-green-mask-only | green / lead-free HASL | [PCB](bundle/sources/panels/art-kumiko-void/17-kumiko-void-wide-L03-green-mask-only.kicad_pcb) | [Preview](bundle/previews/17-kumiko-void-wide-L03-green-mask-only.png) | [ZIP](bundle/packages/17-kumiko-void-wide-L03-green-mask-only.zip) |
| 17-kumiko-void-wide-L04-black-enig-art | black / ENIG | [PCB](bundle/sources/panels/art-kumiko-void/17-kumiko-void-wide-L04-black-enig-art.kicad_pcb) | [Preview](bundle/previews/17-kumiko-void-wide-L04-black-enig-art.png) | [ZIP](bundle/packages/17-kumiko-void-wide-L04-black-enig-art.zip) |
| 17-kumiko-void-wide-L05-red-mask-only | red / lead-free HASL | [PCB](bundle/sources/panels/art-kumiko-void/17-kumiko-void-wide-L05-red-mask-only.kicad_pcb) | [Preview](bundle/previews/17-kumiko-void-wide-L05-red-mask-only.png) | [ZIP](bundle/packages/17-kumiko-void-wide-L05-red-mask-only.zip) |
| 17-kumiko-void-wide-L06-green-mask-only | green / lead-free HASL | [PCB](bundle/sources/panels/art-kumiko-void/17-kumiko-void-wide-L06-green-mask-only.kicad_pcb) | [Preview](bundle/previews/17-kumiko-void-wide-L06-green-mask-only.png) | [ZIP](bundle/packages/17-kumiko-void-wide-L06-green-mask-only.zip) |
| 17-kumiko-void-wide-L07-black-enig-art | black / ENIG | [PCB](bundle/sources/panels/art-kumiko-void/17-kumiko-void-wide-L07-black-enig-art.kicad_pcb) | [Preview](bundle/previews/17-kumiko-void-wide-L07-black-enig-art.png) | [ZIP](bundle/packages/17-kumiko-void-wide-L07-black-enig-art.zip) |
| 17-kumiko-void-wide-L08-red-mask-only | red / lead-free HASL | [PCB](bundle/sources/panels/art-kumiko-void/17-kumiko-void-wide-L08-red-mask-only.kicad_pcb) | [Preview](bundle/previews/17-kumiko-void-wide-L08-red-mask-only.png) | [ZIP](bundle/packages/17-kumiko-void-wide-L08-red-mask-only.zip) |
| 17-kumiko-void-wide-L09-green-mask-only | green / lead-free HASL | [PCB](bundle/sources/panels/art-kumiko-void/17-kumiko-void-wide-L09-green-mask-only.kicad_pcb) | [Preview](bundle/previews/17-kumiko-void-wide-L09-green-mask-only.png) | [ZIP](bundle/packages/17-kumiko-void-wide-L09-green-mask-only.zip) |

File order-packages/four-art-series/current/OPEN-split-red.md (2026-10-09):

# Open split-red

[Order quantities and settings](bundle/variants/split-red/ORDER.md) · [All alternatives](README.md)

Choose only one alternative. Open PCB files in KiCad PCB Editor; upload the listed ZIPs to JLCPCB.

| Package | Color / finish | KiCad PCB | CAM preview | Order ZIP |
| --- | --- | --- | --- | --- |
| lower-panel-white-hasl | white / lead-free HASL | [PCB](bundle/variants/split-red/native/lower-panel-white-hasl/lower-panel-white-hasl.kicad_pcb) | [Preview](bundle/variants/split-red/lower-panel-white-hasl.png) | [ZIP](bundle/variants/split-red/cam/lower-panel-white-hasl.zip) |
| lower-panel-black-enig | black / ENIG | [PCB](bundle/variants/split-red/native/lower-panel-black-enig/lower-panel-black-enig.kicad_pcb) | [Preview](bundle/variants/split-red/lower-panel-black-enig.png) | [ZIP](bundle/variants/split-red/cam/lower-panel-black-enig.zip) |
| lower-panel-green-hasl | green / lead-free HASL | [PCB](bundle/variants/split-red/native/lower-panel-green-hasl/lower-panel-green-hasl.kicad_pcb) | [Preview](bundle/variants/split-red/lower-panel-green-hasl.png) | [ZIP](bundle/variants/split-red/cam/lower-panel-green-hasl.zip) |
| 03-coral-vault-L03-purple-mask-only | purple / lead-free HASL | [PCB](bundle/sources/panels/art-coral-vault/03-coral-vault-L03-purple-mask-only.kicad_pcb) | [Preview](bundle/previews/03-coral-vault-L03-purple-mask-only.png) | [ZIP](bundle/packages/03-coral-vault-L03-purple-mask-only.zip) |
| 03-coral-vault-L06-yellow-mask-only | yellow / lead-free HASL | [PCB](bundle/sources/panels/art-coral-vault/03-coral-vault-L06-yellow-mask-only.kicad_pcb) | [Preview](bundle/previews/03-coral-vault-L06-yellow-mask-only.png) | [ZIP](bundle/packages/03-coral-vault-L06-yellow-mask-only.zip) |
| 03-coral-vault-L08-blue-mask-only | blue / lead-free HASL | [PCB](bundle/sources/panels/art-coral-vault/03-coral-vault-L08-blue-mask-only.kicad_pcb) | [Preview](bundle/previews/03-coral-vault-L08-blue-mask-only.png) | [ZIP](bundle/packages/03-coral-vault-L08-blue-mask-only.zip) |
| lower-panel-black-hasl | black / lead-free HASL | [PCB](bundle/variants/split-red/native/lower-panel-black-hasl/lower-panel-black-hasl.kicad_pcb) | [Preview](bundle/variants/split-red/lower-panel-black-hasl.png) | [ZIP](bundle/variants/split-red/cam/lower-panel-black-hasl.zip) |
| lower-panel-red-hasl-six | red / lead-free HASL | [PCB](bundle/variants/split-red/native/lower-panel-red-hasl-six/lower-panel-red-hasl-six.kicad_pcb) | [Preview](bundle/variants/split-red/lower-panel-red-hasl-six.png) | [ZIP](bundle/variants/split-red/cam/lower-panel-red-hasl-six.zip) |
| lower-panel-red-hasl-fault | red / lead-free HASL | [PCB](bundle/variants/split-red/native/lower-panel-red-hasl-fault/lower-panel-red-hasl-fault.kicad_pcb) | [Preview](bundle/variants/split-red/lower-panel-red-hasl-fault.png) | [ZIP](bundle/variants/split-red/cam/lower-panel-red-hasl-fault.zip) |
| 01-spider-nest-L01-black-enig-art | black / ENIG | [PCB](bundle/sources/panels/art-spider-nest/01-spider-nest-L01-black-enig-art.kicad_pcb) | [Preview](bundle/previews/01-spider-nest-L01-black-enig-art.png) | [ZIP](bundle/packages/01-spider-nest-L01-black-enig-art.zip) |
| 03-coral-vault-L01-black-enig-art | black / ENIG | [PCB](bundle/sources/panels/art-coral-vault/03-coral-vault-L01-black-enig-art.kicad_pcb) | [Preview](bundle/previews/03-coral-vault-L01-black-enig-art.png) | [ZIP](bundle/packages/03-coral-vault-L01-black-enig-art.zip) |
| 13-fault-line-L01-black-enig-art | black / ENIG | [PCB](bundle/sources/panels/art-fault-line/13-fault-line-L01-black-enig-art.kicad_pcb) | [Preview](bundle/previews/13-fault-line-L01-black-enig-art.png) | [ZIP](bundle/packages/13-fault-line-L01-black-enig-art.zip) |
| 17-kumiko-void-wide-L01-black-enig-art | black / ENIG | [PCB](bundle/sources/panels/art-kumiko-void/17-kumiko-void-wide-L01-black-enig-art.kicad_pcb) | [Preview](bundle/previews/17-kumiko-void-wide-L01-black-enig-art.png) | [ZIP](bundle/packages/17-kumiko-void-wide-L01-black-enig-art.zip) |

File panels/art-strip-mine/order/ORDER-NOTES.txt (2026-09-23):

STRIP MINE — FOUR SEPARATE ORDER ITEMS

All: FR-4, 1.6 mm, 2 layers, no silkscreen; 1 oz for copper-bearing boards.
Order equal quantities of all four items. Five of each makes five complete
nine-board stacks. Each combined panel yields one of each included board.

01-top-black-ENIG.zip
  Board 01: black mask, ENIG; single PCB, clean routed perimeter.
  Approximately 101.3 x 128.5 mm.

02-lower-black-ENIG-panel.zip
  Boards 03/05/07: black mask, ENIG.
  Panel by customer; 3 different designs; 303.9 x 94.3 mm.

03-lower-red-ENIG-panel.zip
  Boards 02/04/06/08: red mask, ENIG.
  Panel by customer; 4 different designs; 202.6 x 188.6 mm.

04-bottom-blue-NO-ENIG.zip
  Board 09: blue mask, NO ENIG; single PCB; 101.3 x 94.3 mm.
  No copper on either side, four unplated 3.2 mm holes.
  If a finish selection is mandatory, choose a standard non-ENIG option
  such as lead-free HASL. Ask CAM to preserve the copper-free blue board.

Upload each ZIP as a separate item. Do not also order individual 02–08.
Combined-panel ZIPs include FABRICATION.txt.
User_Drawings.gbr specifies full-span V-SCORE lines, NOT milling or silk.
Edge_Cuts specifies the routed perimeter and clean inner pit openings.
Confirm V-scoring and intentional copper at routed pit edges with CAM.
Panelization savings still require a quote.

New combined panels and blue board pass DRC/geometry checks.
Existing top-board intentional pad/frame clearance violations and
individual board-08 settings mismatch remain documented.

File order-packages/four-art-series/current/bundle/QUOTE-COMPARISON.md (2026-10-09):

# Quote comparison

Select one alternative. Top-board cost is held constant across alternatives.

| Alternative | Lines | Sheets / units | Useful pieces | Blank cells | Surplus | Price / fees / shipping / tax |
| --- | ---: | ---: | ---: | ---: | ---: | --- |
| individual | 34 | 850 | 850 | 0 | 0 | unknown |
| grouped | 12 | 300 | 850 | 50 | 0 | unknown |
| split-red | 13 | 325 | 850 | 0 | 0 | unknown |

Quote each alternative for the same requested output. Each scored sheet contains multiple distinct designs; quantities mean sheets. Ask for engineering/design, routing/scoring, ENIG, panel-area, shipping and tax amounts and currency/date. Unknown amounts are not zero. Blank cells omit rails/cutout waste. No savings or factory acceptance is established.

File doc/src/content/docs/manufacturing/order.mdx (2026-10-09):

---
title: Package and Order Planning
sidebar_position: 4
---

The current quote candidates select **Coral Vault, Fault Line, Kumiko Void wide and Spider Nest**: exactly 34 source boards, with four individually routed cosmetic tops and 30 lowers. Strip Mine has already been ordered and is outside this selection. Woven Maze and standard Kumiko remain historical/reference sources.

The [four-series profile](https://github.com/Takazudo/zudo-blanks/blob/main/artwork-resources/pcb-art/manufacturing/order-profiles/four-art-series.json) and [build/download guide](https://github.com/Takazudo/zudo-blanks/blob/main/scripts/art-order/README.md) define three alternatives. Choose **one** alternative's order list; never purchase every ZIP in the bundle.

| Alternative, 25 stacks per series | Order lines | Sheets / standalone units | Useful pieces | Blank cells |
| --- | ---: | ---: | ---: | ---: |
| Individual boards | 34 | 850 | 850 | 0 |
| Grouped, one ten-member red sheet | 12 | 300 | 850 | 50 |
| Split-red, six plus four | 13 | 325 | 850 | 0 |

All alternatives supply 100 complete stacks, comprising 100 top and 750 lower pieces. Requested hardware totals are 400 screws, 3,000 spacers and 400 nuts; dimensions and fit assumptions remain unchanged. Profile quantities can be adjusted per series. Supply rounds up to configured supplier sheet quantities and explicitly reports surplus per board ID and complete-stack yield. Confirm offered quantities with the quote.

| Lower group | Compact grid | Sheet dimensions, mm |
| --- | --- | --- |
| White lead-free HASL, 3 members | 1 × 3 | 111.3 × 292.9 |
| Black ENIG, 6 members | 3 × 2 | 313.9 × 198.6 |
| Green lead-free HASL, 4 members | 2 × 2 | 212.6 × 198.6 |
| Black lead-free HASL, 4 members | 2 × 2 | 212.6 × 198.6 |
| Red lead-free HASL, 10 members | 3 × 4 | 313.9 × 387.2 |
| Split red, 6 members | 2 × 3 | 212.6 × 292.9 |
| Split red, Fault Line's 4 members | 2 × 2 | 212.6 × 198.6 |

Purple, yellow and blue remain individual lower boards. Color **and** finish determine compatibility: black ENIG is separate from black HASL. The red six-member sheet holds Spider L08, Coral L05/L07 and Kumiko wide L02/L05/L08. The four-member red sheet holds Fault L02/L04/L06/L08. The split has no blank cells and is the preferred compact candidate for quotation, not a proven cheaper option.

Native source artwork, apertures, mounting holes and stack geometry remain unchanged. Lower sheets use translation-only placement and 5 mm rails. Scores use a separate fabrication drawing; decorative apertures remain routed. Tops retain their finished routed edges and rail slots. The workflow checks actual native/CAM outputs and includes individual/placement previews, nominal stack-side views, DRC logs, package hashes and source/tool/run provenance.

The read-only Actions workflow runs the same checked-in entry point used locally. The [guide](https://github.com/Takazudo/zudo-blanks/blob/main/scripts/art-order/README.md) explains exact-run artifact downloads and checksum/inventory verification. Each variant includes its own purchasing table and machine-readable manifest. The artifact records the PR merge commit as the tested source, with head/base SHAs separately. Later relevant edits need fresh evidence.

Prices and engineering/design, routing/scoring, ENIG, area, shipping and tax charges remain **unknown** until an actual dated quote. Blank cells exclude rails and cutouts. Fewer sheets or order lines do not establish savings. Factory CAM/scoring approval, residual score-web depth, perforated-sheet support, side-edge appearance, finish availability and physical stack/fastener fit remain external checks. Native DRC is not factory approval; these candidates are not a purchase commitment.

## Historical five-series plan

The [historical manifest](https://github.com/Takazudo/zudo-blanks/blob/main/artwork-resources/pcb-art/manufacturing/lower-panels-order-manifest.json) and [native grouped sources](https://github.com/Takazudo/zudo-blanks/tree/main/panels/art-grouped-lowers) retain the five-series selection including Woven Maze: 43 IDs, 1,075 useful pieces, 75 blank cells, 13 packages and 325 units at 25 stacks per series. Its hardware totals are 500 screws, 3,800 spacers and 500 nuts. Those preserved records are not the current four-series purchase list.

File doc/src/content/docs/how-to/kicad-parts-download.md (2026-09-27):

---
title: Download KiCad Footprints
sidebar_position: 2
---

# Download KiCad Footprints

This guide explains how to download KiCad footprints from LCSC/EasyEDA using the easyeda2kicad.py tool. For blank panels, you primarily need mounting hole footprints.

## Overview

This project uses [easyeda2kicad.py](https://github.com/uPesy/easyeda2kicad.py) to download KiCad libraries from the LCSC/EasyEDA database when needed.

**For blank panels, you mainly need:**

- **Mounting hole footprints** - Standard M3 through-hole mounting holes
- KiCad's built-in libraries already include standard mounting holes

## Using KiCad Built-in Mounting Holes

KiCad includes mounting hole footprints in its standard library:

1. Open **Footprint Editor**
2. Browse library: `MountingHole`
3. Common footprints:
   - `MountingHole_3.2mm_M3` - Standard M3 mounting hole
   - `MountingHole_3.2mm_M3_Pad` - M3 with copper pad
   - `MountingHole_3.2mm_M3_Pad_Via` - M3 with vias for grounding

## Prerequisites (for custom footprints)

### Install easyeda2kicad.py

```bash
pip install easyeda2kicad
```

### Verify Installation

```bash
easyeda2kicad --version
```

## Download Custom Footprints

If you need footprints not in KiCad's standard library:

```bash
# Download footprint by LCSC ID
easyeda2kicad --lcsc_id <LCSC_ID> --footprint

# Copy to project directory
cp ~/Documents/Kicad/easyeda2kicad/easyeda2kicad.pretty/*.kicad_mod ./footprints/kicad/
```

## Project Structure

```
footprints/
├── kicad/
│   └── *.kicad_mod          # KiCad footprint files
├── images/
│   └── *.svg                # Exported SVG images (for documentation)
└── scripts/
    └── clean-svg-refs.py    # Script to clean SVG exports
```

## Troubleshooting

### Problem: "easyeda2kicad: command not found"

**Solution**: Ensure pip installed the package correctly and it's in your PATH:

```bash
which easyeda2kicad
```

### Problem: "Part not found"

**Solution**:

- Verify the LCSC ID is correct
- Check if the part exists on LCSC.com

## References

- [easyeda2kicad.py GitHub](https://github.com/uPesy/easyeda2kicad.py)
- [LCSC Component Search](https://www.lcsc.com/)
- [KiCad Documentation](https://docs.kicad.org/)

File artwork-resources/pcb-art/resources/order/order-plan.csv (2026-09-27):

board_id | design | kumiko_variant | front_to_back_layer | mask_color | surface_intent | thickness_mm | required_quantity | supplier_order_quantity | native_board | fabrication_status
01-spider-nest-L01-black-enig-art | spider-nest |  | 1 | black | enig-art | 1.6 | 1 |  | panels/art-spider-nest/01-spider-nest-L01-black-enig-art.kicad_pcb | EDITABLE DRAFT - resolve routing, local KiCad DRC and CAM before order
01-spider-nest-L02-white-mask-only | spider-nest |  | 2 | white | mask-only | 1.6 | 1 |  | panels/art-spider-nest/01-spider-nest-L02-white-mask-only.kicad_pcb | EDITABLE DRAFT - resolve routing, local KiCad DRC and CAM before order
01-spider-nest-L03-gold-enig-fill | spider-nest |  | 3 | black | enig-fill | 1.6 | 1 |  | panels/art-spider-nest/01-spider-nest-L03-gold-enig-fill.kicad_pcb | EDITABLE DRAFT - resolve routing, local KiCad DRC and CAM before order
01-spider-nest-L04-white-mask-only | spider-nest |  | 4 | white | mask-only | 1.6 | 1 |  | panels/art-spider-nest/01-spider-nest-L04-white-mask-only.kicad_pcb | EDITABLE DRAFT - resolve routing, local KiCad DRC and CAM before order
01-spider-nest-L05-gold-enig-fill | spider-nest |  | 5 | black | enig-fill | 1.6 | 1 |  | panels/art-spider-nest/01-spider-nest-L05-gold-enig-fill.kicad_pcb | EDITABLE DRAFT - resolve routing, local KiCad DRC and CAM before order
01-spider-nest-L06-white-mask-only | spider-nest |  | 6 | white | mask-only | 1.6 | 1 |  | panels/art-spider-nest/01-spider-nest-L06-white-mask-only.kicad_pcb | EDITABLE DRAFT - resolve routing, local KiCad DRC and CAM before order
01-spider-nest-L07-gold-enig-fill | spider-nest |  | 7 | black | enig-fill | 1.6 | 1 |  | panels/art-spider-nest/01-spider-nest-L07-gold-enig-fill.kicad_pcb | EDITABLE DRAFT - resolve routing, local KiCad DRC and CAM before order
01-spider-nest-L08-red-mask-only | spider-nest |  | 8 | red | mask-only | 1.6 | 1 |  | panels/art-spider-nest/01-spider-nest-L08-red-mask-only.kicad_pcb | EDITABLE DRAFT - resolve routing, local KiCad DRC and CAM before order
03-coral-vault-L01-black-enig-art | coral-vault |  | 1 | black | enig-art | 1.6 | 1 |  | panels/art-coral-vault/03-coral-vault-L01-black-enig-art.kicad_pcb | EDITABLE DRAFT - resolve routing, local KiCad DRC and CAM before order
03-coral-vault-L02-green-mask-only | coral-vault |  | 2 | green | mask-only | 1.6 | 1 |  | panels/art-coral-vault/03-coral-vault-L02-green-mask-only.kicad_pcb | EDITABLE DRAFT - resolve routing, local KiCad DRC and CAM before order
03-coral-vault-L03-purple-mask-only | coral-vault |  | 3 | purple | mask-only | 1.6 | 1 |  | panels/art-coral-vault/03-coral-vault-L03-purple-mask-only.kicad_pcb | EDITABLE DRAFT - resolve routing, local KiCad DRC and CAM before order
03-coral-vault-L04-gold-enig-fill | coral-vault |  | 4 | black | enig-fill | 1.6 | 1 |  | panels/art-coral-vault/03-coral-vault-L04-gold-enig-fill.kicad_pcb | EDITABLE DRAFT - resolve routing, local KiCad DRC and CAM before order
03-coral-vault-L05-red-mask-only | coral-vault |  | 5 | red | mask-only | 1.6 | 1 |  | panels/art-coral-vault/03-coral-vault-L05-red-mask-only.kicad_pcb | EDITABLE DRAFT - resolve routing, local KiCad DRC and CAM before order
03-coral-vault-L06-yellow-mask-only | coral-vault |  | 6 | yellow | mask-only | 1.6 | 1 |  | panels/art-coral-vault/03-coral-vault-L06-yellow-mask-only.kicad_pcb | EDITABLE DRAFT - resolve routing, local KiCad DRC and CAM before order
03-coral-vault-L07-red-mask-only | coral-vault |  | 7 | red | mask-only | 1.6 | 1 |  | panels/art-coral-vault/03-coral-vault-L07-red-mask-only.kicad_pcb | EDITABLE DRAFT - resolve routing, local KiCad DRC and CAM before order
03-coral-vault-L08-blue-mask-only | coral-vault |  | 8 | blue | mask-only | 1.6 | 1 |  | panels/art-coral-vault/03-coral-vault-L08-blue-mask-only.kicad_pcb | EDITABLE DRAFT - resolve routing, local KiCad DRC and CAM before order
13-fault-line-L01-black-enig-art | fault-line |  | 1 | black | enig-art | 1.6 | 1 |  | panels/art-fault-line/13-fault-line-L01-black-enig-art.kicad_pcb | EDITABLE DRAFT - resolve routing, local KiCad DRC and CAM before order
13-fault-line-L02-red-mask-only | fault-line |  | 2 | red | mask-only | 1.6 | 1 |  | panels/art-fault-line/13-fault-line-L02-red-mask-only.kicad_pcb | EDITABLE DRAFT - resolve routing, local KiCad DRC and CAM before order
13-fault-line-L03-black-mask-only | fault-line |  | 3 | black | mask-only | 1.6 | 1 |  | panels/art-fault-line/13-fault-line-L03-black-mask-only.kicad_pcb | EDITABLE DRAFT - resolve routing, local KiCad DRC and CAM before order
13-fault-line-L04-red-mask-only | fault-line |  | 4 | red | mask-only | 1.6 | 1 |  | panels/art-fault-line/13-fault-line-L04-red-mask-only.kicad_pcb | EDITABLE DRAFT - resolve routing, local KiCad DRC and CAM before order
13-fault-line-L05-black-mask-only | fault-line |  | 5 | black | mask-only | 1.6 | 1 |  | panels/art-fault-line/13-fault-line-L05-black-mask-only.kicad_pcb | EDITABLE DRAFT - resolve routing, local KiCad DRC and CAM before order
13-fault-line-L06-red-mask-only | fault-line |  | 6 | red | mask-only | 1.6 | 1 |  | panels/art-fault-line/13-fault-line-L06-red-mask-only.kicad_pcb | EDITABLE DRAFT - resolve routing, local KiCad DRC and CAM before order
13-fault-line-L07-black-mask-only | fault-line |  | 7 | black | mask-only | 1.6 | 1 |  | panels/art-fault-line/13-fault-line-L07-black-mask-only.kicad_pcb | EDITABLE DRAFT - resolve routing, local KiCad DRC and CAM before order
13-fault-line-L08-red-mask-only | fault-line |  | 8 | red | mask-only | 1.6 | 1 |  | panels/art-fault-line/13-fault-line-L08-red-mask-only.kicad_pcb | EDITABLE DRAFT - resolve routing, local KiCad DRC and CAM before order
13-fault-line-L09-black-mask-only | fault-line |  | 9 | black | mask-only | 1.6 | 1 |  | panels/art-fault-line/13-fault-line-L09-black-mask-only.kicad_pcb | EDITABLE DRAFT - resolve routing, local KiCad DRC and CAM before order
17-kumiko-void-wide-L01-black-enig-art | kumiko-void | wide | 1 | black | enig-art | 1.6 | 1 |  | panels/art-kumiko-void/17-kumiko-void-wide-L01-black-enig-art.kicad_pcb | EDITABLE DRAFT - resolve routing, local KiCad DRC and CAM before order
17-kumiko-void-wide-L02-red-mask-only | kumiko-void | wide | 2 | red | mask-only | 1.6 | 1 |  | panels/art-kumiko-void/17-kumiko-void-wide-L02-red-mask-only.kicad_pcb | EDITABLE DRAFT - resolve routing, local KiCad DRC and CAM before order
17-kumiko-void-wide-L03-green-mask-only | kumiko-void | wide | 3 | green | mask-only | 1.6 | 1 |  | panels/art-kumiko-void/17-kumiko-void-wide-L03-green-mask-only.kicad_pcb | EDITABLE DRAFT - resolve routing, local KiCad DRC and CAM before order
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

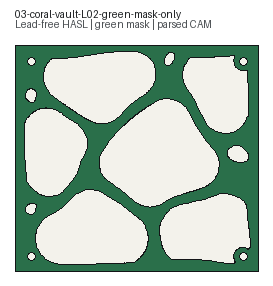
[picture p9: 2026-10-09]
order-packages/four-art-series/current/bundle/previews/03-coral-vault-L02-green-mask-only.png

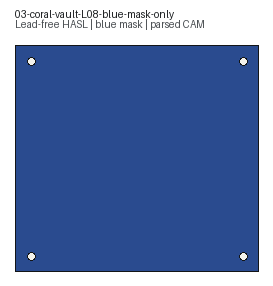
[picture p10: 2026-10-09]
order-packages/four-art-series/current/bundle/previews/03-coral-vault-L08-blue-mask-only.png

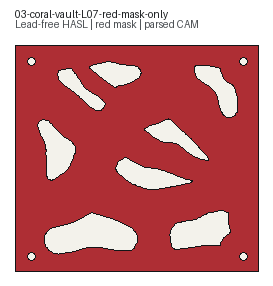
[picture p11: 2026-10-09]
order-packages/four-art-series/current/bundle/previews/03-coral-vault-L07-red-mask-only.png

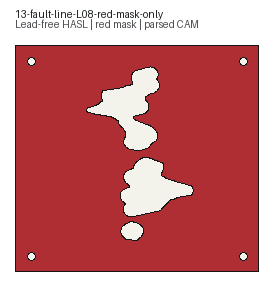
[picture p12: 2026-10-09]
order-packages/four-art-series/current/bundle/previews/13-fault-line-L08-red-mask-only.png

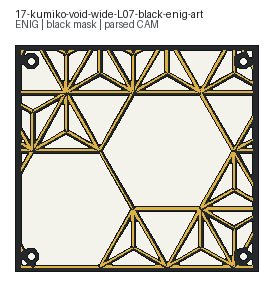
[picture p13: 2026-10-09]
order-packages/four-art-series/current/bundle/previews/17-kumiko-void-wide-L07-black-enig-art.png

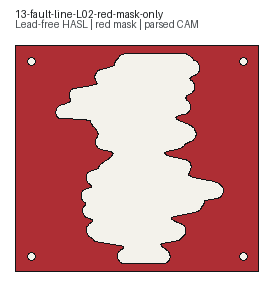
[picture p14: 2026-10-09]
order-packages/four-art-series/current/bundle/previews/13-fault-line-L02-red-mask-only.png

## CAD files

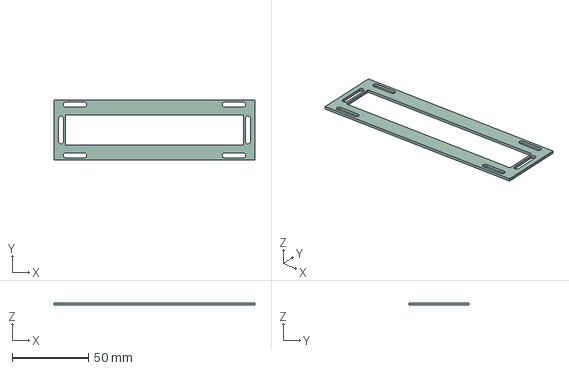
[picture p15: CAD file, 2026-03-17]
panels/alumi-3u-to-1u-v1/3u-to-1u-v1.step
131.8 x 39.7 x 1.51 mm

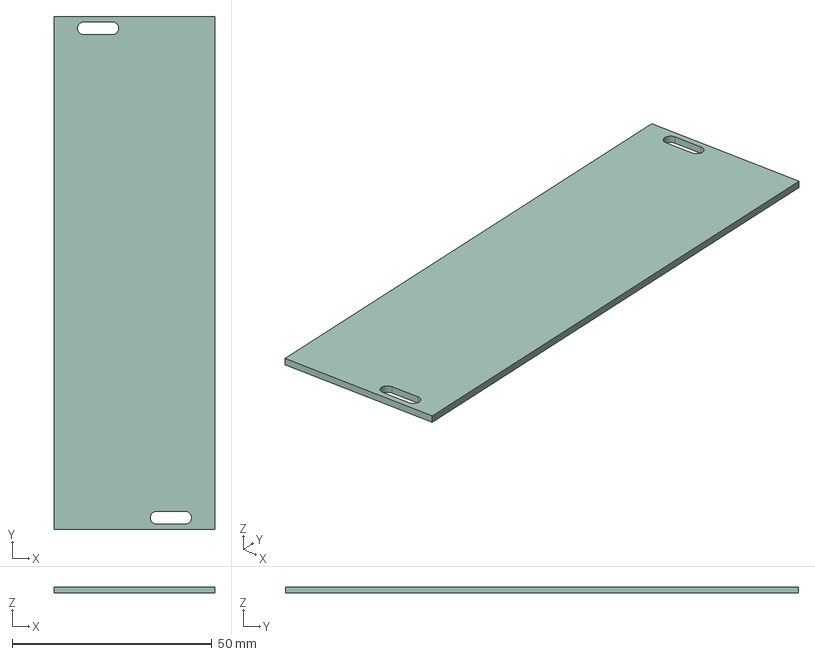
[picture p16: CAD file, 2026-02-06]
panels/alumi-blanks-v1-3U-8hp/3d/panel.FCStd
40.3 x 128.5 x 1.60 mm

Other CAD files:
panels/alumi-blanks-v1-3U-8hp/3d/panel.stl

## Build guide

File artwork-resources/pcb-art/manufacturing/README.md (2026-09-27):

# Fabrication decision — 2026-09-25

Decision for [issue 14](https://github.com/Takazudo/zudo-blanks/issues/14), frozen for issues 15–17. `policy.json` is the machine-readable contract. This record chooses the local adaptation and packaging process; production geometry, native validation and CAM follow in those issues. The approved artwork is still Revision 5 with **Kumiko wide**. No board has factory acceptance.

## Evidence and current capability check

Checked **2026-09-25** against the live official pages below. These published capabilities are distinct from this project's stricter choices. Source geometry SHA256 is `00835f3a5db6cec4806d0747d274c7c65dff0e1f0f0a8c79316b488f6e5c870e`. `policy.json` freezes the other input hashes, including both manufacturing reviews and the native manifest. The incoming review figures and CSVs remain original evidence, including their limitations.

[JLCPCB rigid capabilities](https://jlcpcb.com/capabilities/Capab), sections Drilling, Traces, Soldermask and Outline: FR-4; 1.6 mm thickness ±10%; 1 oz copper; NPTH minimum 0.50 mm; nonplated slot minimum 1.0 mm; sharp rectangular internal corners unsupported; NPTH/route copper clearance 0.2 mm. General copper width/space is 0.10/0.10 mm, while exposed coils, grids and same-net spacing specify 0.25 mm. Black/white mask bridges require 0.13 mm; other listed colors 0.10 mm. Mask opening to neighboring traces is 0.09 mm. V-score copper clearance is 0.4 mm, size tolerance ±0.4 mm, panel range 70–475 mm, groove angle 25°. Routed dimensional tolerance is ±0.2 mm regular / ±0.1 mm precision; precision has extra tooling conditions. Spaced panel routing requires 2 mm; tabs leave serrations. These are catalog limits, not approval of artwork or strength.

[JLCPCB PCB Panelization](https://jlcpcb.com/help/article/pcb-panelization), **last updated September 9, 2026**, V-cut/V-Groove items 1–6 and 10: zero separation at scores; straight horizontal/vertical lines across the whole sheet; 70 × 70 mm minimum; 475 × 475 mm maximum with both score directions; parallel scores at least 2 mm apart; at most 25 score lines per axis. The article also limits different designs to ten. We declare actual distinct board IDs and use a conservative ten-member cap in every package. A multi-design fee or lower cost is not inferred.

[KiCad 10 PCB Editor manual](https://docs.kicad.org/10.0/en/pcbnew/pcbnew.html), sections **Board outlines (Edge Cuts)**, **Solder mask/paste**, **Graphical shapes**, **Pad properties**, **Drill files**, and **Board finish**: closed nonintersecting Edge.Cuts contours define material and internal voids. NPTH mechanical pads represent unplated circular/oval drills. Mask graphics denote openings. Global mask minimum-web settings can merge plotted openings; board finish metadata only affects Gerber job attributes. Therefore do not use automatic mask-web merging to fix black facets. Set mask expansion and automatic web merging to zero for explicit artwork geometry; enforce spacing independently. Export NPTH separately from PTH and do not duplicate drill contours on Edge.Cuts. KiCad DRC does not replace a geometric check of the union of graphic polygons.

The source exporter already interprets F.Mask as openings, preserves painter order, subtracts black facets and represents NPTH independently. Strip Mine `scripts/build-panels.mjs`, `export-panels.py` and `panels.test.mjs` were read for translation, score drawings and packaging structure only. Its plated-pad, edge-copper and DRC choices are not inherited.

## Frozen rules

All distances below are nominal millimetres. Numeric comparison tolerances are **0.001 mm distance** and **0.00001 mm² area**; tolerances cover serialization, never an unlisted design exception. Use 1 nm native coordinates and retain analytic arcs or sufficiently fine curves (at least 64 segments per circle quadrant in geometric proofs).

| Requirement | Project choice | Purpose |
| --- | ---: | --- |
| Process | 2 copper layers, FR-4, 1.6 mm, 1 oz | Same construction for every package; no electronic components |
| Decorative routing | 1.0 mm cutter, 0.5 mm internal corner radius | Explicit tool-center regions and swept cut envelopes |
| Material ligament / structural bridge | ≥1.0 mm | Separate minimum-width and connectivity checks |
| Stack support before drilling | full disk radius 3.05 mm | Preserve all four spacer seats, not only the hole's annulus |
| Top copper / visible-gold clearance to any route or true drill | ≥0.30 / ≥0.35 mm | Includes inner apertures, outer perimeter and oval slots |
| Lower copper / visible-gold clearance to outer rectangle | ≥0.50 / ≥0.55 mm | Scoring allowance encoded in individual boards before panelization |
| Lower copper / visible gold to internal route or drill | ≥0.30 / ≥0.35 mm | Decorative edges stay routed |
| Copper beneath an opening | ≥0.05 mm margin | Mask opening contained in copper |
| Finished graphic copper width / separate copper gap | ≥0.25 / ≥0.25 mm | Use the more restrictive published coil/grid class for all art |
| Visible gold width / mask web | ≥0.25 / ≥0.25 mm | One consistent art rule; exceeds 0.13 mm black-mask floor |
| Hidden copper join | width ≥0.25 mm, length ≤0.60 mm per indexed gap | Join nearby decorative islands beneath retained mask |
| Mask to unrelated copper | ≥0.09 mm | Do not confuse own underlying copper with a neighboring island |
| Local mask repair reach | ≤0.50 mm from the indexed offending feature | Prevent broad edits to the approved motif |
| Scored seam to decorative aperture or support disk | ≥1.0 mm | Entire score corridor must remain solid and clear |

Width means the width of the finished union, including narrow necks, branches and standalone fragments, not nominal input stroke width. At a finite end, cap a gold or material branch where its 0.25 mm or 1.0 mm full width ends; an arbitrarily acute surviving needle is not an exception. Connected erosion can miss a disappearing branch, so inspect erosion/reconstruction residue and opposing nonadjacent boundary segments as well. Mark candidates by board, coordinate and original feature; repair locally by adding substrate (shrinking the adjacent cutout), then recheck tool access. Do not silently discard width candidates as numerical dust. Distinguish a rounded terminal cap from a narrow branch of positive length.

**Geometry and appearance invariants:** top rectangle `[0,0,101.3,128.5]`; lower rectangle `[0,17.1,101.3,111.4]`; thickness 1.6 and spacer gap 3.0. Stack centers are `(6.5,23.6)`, `(94.8,23.6)`, `(6.5,104.9)`, `(94.8,104.9)` with Ø3.2 NPTH on every board. Only tops have four 10.28 × 3.2 mm NPTH slots, at the original slightly asymmetric centers in `policy.json`. No global alignment or symmetry cleanup. Require one connected board after drilling, continuous full-width upper/lower strips at least 1.0 mm deep, a solid final floor except the four drills, and every decorative top opening backed by the lower rectangle.

Keep Spider's radial irregular web; Coral/Fault's descending nested irregular aperture unions; Fault's angular black and rounded red cliffs; Kumiko's angular planar gold/black illusion; all seven different Woven lower maze paths. Round only inaccessible route corners, preserving straight angular segments. All five tops retain the outer gold frame, four stack rims and four slot rims (nine paths per top). Rail rims initially have 0.30 mm inner clearance: retreat their inner edge by 0.05 mm to meet 0.35 mm clearance, leaving nominal 0.35 mm visible width. Index this operation by each original `rail-slot` featureIndex 0–3 on every top. Coral L01 stack rims at original featureIndex **1, 2 and 3** also approach the decorative contour to 0.248274 mm in the approved input. Move only these three circular centerlines inward from radius **2.70 to 2.55 mm**, retaining 0.40 mm width and exact drill centers; repaint them last. All other border centerlines remain unchanged. Prove each of the nine closed paths retains a continuous 0.25 mm gold core. The outer frame needs no retreat. Full-gold lower layers remain ENIG fill with necessary safe setbacks. Lower mask-only layers retain no decorative copper/openings and never acquire exposed gold. B.Cu artwork, B.Mask artwork, paste, silk, PTH and edge plating remain empty/disabled. The nominal two-layer construction does not authorize adding rear copper art.

## Indexed local adaptation

1. **Close the 56 selected small apertures** listed with original `issueId`, `geometryHoleIndex0`, area and coordinates in `policy.json`. Add substrate only in each original hole; retain that board's mask. The sum is **139.19764395 mm² across eight wide layers**. Do not replace them with round holes, enlarge them through support, or switch to standard Kumiko. Closing **wide L01-H11**, original hole index **101**, also removes `kumiko-void-wide-L01-THIN-68-101` (0.116618566 mm at the recorded closest points). Retain original hole 68 except its individually indexed inaccessible corner treatment. The eight standard findings and all nine standard boards remain unchanged and **non-orderable alternatives**.
2. For each remaining decorative aperture `A`, compute its admissible 0.5 mm cutter-center region. Inaccessible tips become substrate; the candidate finished aperture is the union of 0.5 mm swept disks over **all** admissible center components. This is a tool-envelope definition, not whole-board smoothing. Do not discard a smaller center component. Each disconnected center region needs a recorded accessible plunge and path, or an indexed local closure/shrink. Known split center regions: wide Kumiko L05 original hole 14; Woven L04 original hole 0. Neither fact is resolved merely because a tool fits elsewhere in the hole. No change to functional drills.
3. Preserve unchanged contours exactly outside each recorded delta. On each changed original aperture, write its source hash, original index, changed-coordinate bounding boxes, operation, before/after area, contour hashes and measured tests. The probe's per-hole changes are a seed list, not permission to change unrelated areas. For nonempty holes, local corner displacement is bounded by **0.75 mm**; larger corner displacement or split-center closure must get a separate indexed record with measured area and a targeted comparison under the same local policy. Known complete closures are explicitly exempt from that displacement bound. Any extra complete aperture closure, topological motif replacement or failed invariant is a blocker requiring evidence, not an automatic fallback.
4. Enforce minimum material width locally. Prefer substrate additions at an indexed thin neck over aperture enlargement or opening merger. No global buffer/simplify pass over board art or physical geometry. Recompute tool sweeps after each repair. Nesting is tested on corrected aperture unions, not assumed from the originals.
5. Reconstruct gold using original fills/strokes and paint order, including Kumiko black facets and last-painted rims. Apply the numeric safe-edge masks to corrected geometry. Preserve original gold on original surviving substrate; newly filled tiny holes stay mask-colored. Full-gold lower material may follow the complete safe substrate, with every added exposed patch indexed. Record edge clipping by board and nearest original art feature, not merely a single global percentage.
6. Resolve copper gaps by **hidden joins first**: add a ≥0.25 mm wide local bridge beneath intact mask, staying inside the copper safe region. Do not open mask over it. Resolve mask-web gaps by retreating the adjacent gold locally until the **0.25 mm** web exists. Kumiko black facet points stay black. An incidental unpainted mask sliver at the intersection of top rims/motif may be merged into gold only if it contains no original black-facet paint and the operation is separately indexed. The nine rim paths take priority over nearby motif tips; trim/retreat the motif first. The only additional gold-merge permission is the explicitly bounded Spider L01 channel erratum below.
7. Cap sub-width gold tips, or remove an isolated sub-width gold fragment only after an indexed local widening is impossible without invading a black facet or protected border. Bounds, original feature IDs, area and reason are mandatory. Copper can remain hidden beneath a removed mask sliver. Do not present a minimum inscribed-circle test as proof of every feature's printable width.

Existing art gap entries have no issueId; use the stable key `art:<sourceExportSha256>:<boardId>:<feature>:<polygonA0>:<polygonB0>` and retain their original closest-point coordinates from `validation/export-art-review.json` / `resources/manufacturing-review/artwork-gap-review.csv`. Link all selected input findings, even if they disappear as a consequence of a prior correction. New findings under 0.25 mm receive equivalent keys tied to the measured input hash. The nine standard boards' findings remain separate. A production ledger must account for every output delta and every known selected finding; no blanket DRC exclusions.

Appearance budgets are **≤2% aperture area loss per board**, except **wide L01 ≤3.5%** because its measured 1.0 mm tool-envelope loss is 3.05419%. Existing approved source corners cannot be routed exactly. Combined edge/width/mask adjustments may remove **≤30% gold area per ENIG board**, but this budget never permits deleting a motif, shadow facet or border. Every changed design needs a full-board and targeted comparison, and every ENIG board needs numeric before/after gold metrics. Exceeding a budget requires an explicit evidence-based decision amendment; do not quietly relax tests. These are project review gates, not manufacturer limits.

## Spider L01 channel erratum — 2026-09-25

Issue 15's relocated guides expose three narrow unpainted channels between the main Spider radial network and source guide strokes 111, 97 and 112. The source has no explicit black fills or strokes; its radial paths and aperture-following guides belong to the same web motif. The specific source stroke pairs nevertheless had nonzero gaps (approximately 0.155110, 0.164872 and 0.123074 mm). This is a permitted local change to their connection, not a claim that the approved artwork already joined them.

The reviewed manufacturing candidate is SHA256 `ceda4de34fb2ca999e263bfaba0233730f7a60551049807c319721239855d0a1`. The captured evidence candidate is `f40a5bd4f0abb63d9f20f81a6f53eb397ac9c92e4c0c1c9d88152cb97927d068`; the three gaps and closest points remained identical on read-back. `spider-channel-erratum.json` binds the approved input, the six original stroke hashes, the exact pre-merge Spider mask and four patch geometries. This evidence is a permission envelope; it does not approve completed manufacturing artwork.

| Channel / original stroke indices (zero-based) | Closest-point midpoint mm | Measured gap mm | Patches | Added gold mm² |
| --- | --- | ---: | ---: | ---: |
| SP-L01-CHANNEL-01 / 41–111 | (33.715887, 56.778474) | 0.034614 | 2 | 9.739923 |
| SP-L01-CHANNEL-02 / 33–97 | (64.357504, 73.903113) | 0.044372 | 1 | 12.352887 |
| SP-L01-CHANNEL-03 / 38–112 | (30.178096, 78.087342) | 0.002574 | 1 | 7.779394 |

Permit **only four patches in these recorded channels**, with a hard combined cap of **30.0 mm²**. The 32-segment reference measures 29.872204 mm²; the captured 64-segment implementation example measures 29.892211 mm². These measurements are evidence, not equality requirements. Add them to the pre-merge gold union; remove no existing gold. Preserve all nine top rim cores, the radial paths, their guide strands, and all physical contours/drills. Every added point must stay in the **0.35 mm mask-safe region** and within the existing 0.50 mm local-art correction reach. No explicit black paint may be covered. All other copper, mask, geometry, clearance, finish and appearance rules remain in force. This permission does not apply to other boards, other Spider channels or Kumiko facets.

The 32-segment reference patch calculation is pair-specific: let `C(X)` be `X.buffer(0.1255, quad_segs=32).buffer(-0.1255, quad_segs=32)`. For the recorded components A/B, extract `(C(A union B) minus (C(A) union C(B))) minus (A union B)`. A 64-segment implementation may extract the connected added polygons from `C(M) minus M` for the full pre-merge mask M, but select only polygons touching both members of the recorded pairs. Apply exactly four selected channel patches; discard every unrelated candidate polygon. The proposed patch for each recorded ID must lie inside the union of its captured 32-segment reference and 64-segment implementation polygons, allowing only the existing 0.001 mm coordinate tolerance, remain within 0.1255 mm of the pre-merge gold (plus the existing 0.001 mm distance tolerance), touch both named components, and satisfy the total-area/clearance/paint gates. This bounds the measured discretization and extraction differences without permitting arbitrary additions up to the area cap. Do not apply closing to the entire mask. Their long coordinate bounds represent narrow channels; record the entire patch geometry, not merely the nearest-point marker. A tiny connector that only makes a distinct-component warning disappear is insufficient.

Before applying the exception, verify the approved source and stroke hashes and compare the candidate's pre-merge Spider mask to the captured mask. A changed overall candidate hash is acceptable only for separately ledgered unrelated-board or provenance changes **while the Spider mask is identical** (normalized WKB hash, or explicit geometry equivalence within the existing numerical tolerances). Different Spider geometry or a patch outside its recorded channel envelope requires a new indexed review; the area cap alone grants no broader permission. The two captured patch realizations define the narrow permission envelope; their areas are not fixed equality targets. This envelope does not authorize moving the pre-merge artwork. Pre-merge mask distance may differ only within 0.001 mm; compare area at fixed 1 nm precision or reproduce the captured quantized-mask hash. Account for every resulting coordinate delta explicitly. Recompute copper from the final accepted mask and rerun its independent rules.

Issue 15 must prove **positive gold widths and negative mask widths**, including branches/channels inside a single connected component; preserve the source strands and rim cores; and reject new trapped mask pockets or sub-width channel ends. Require full-board and enlarged before/after comparisons showing the actual four additions and source/candidate hashes. Convex-corner reconstruction residue must be distinguished from a positive-length thin branch; neither eroded-core connectivity nor a vanished component-gap warning is sufficient. The captured full-board and enlarged comparison is `spider-channel-erratum.png`; it shows preserved strands and the bounded additions. Regenerate it from repository root with `uv run --python 3.13 --with shapely==2.1.2 --with pillow python artwork-resources/pcb-art/manufacturing/render_spider_erratum.py`. Final production width tests and output-level visual acceptance remain pending. The earlier decision probe and approved Rev5 history remain immutable; the policy test reconstructs the exact pre-erratum policy for the old probe hash and verifies this additive exception separately.

## Spider L01 rib-width erratum — 2026-09-25

The width conflict beside central source strokes **7/8** cannot be repaired by moving three gold strands inside the existing material. At their midpoints `(69.8334,46.2349)` and `(61.1195,51.5244)`, the rib measures **1.661166 / 1.661193 mm**. After two 0.35 mm mask setbacks, only **0.961166 / 0.961193 mm** remains. Two 0.251 mm guides, a 0.280 mm central stroke and two 0.250 mm black channels require **1.282 mm**. The current internal black channels are approximately 0.080 mm wide. Even substituting the published 0.13 mm black-mask floor would require **1.042 mm**, still more than the available space; that comparison does not authorize reducing the frozen 0.25 mm rule. The two long enclosed ink islands are not exempt because they admit a larger circle somewhere else.

Permit a **2.0 mm material ribbon with flat caps and miter joins**, along exactly:

```text
(73.5804,43.9604) -> (66.0864,48.5094) -> (56.1526,54.5394)
```

The initial operation is `new_body = captured_body union ribbon`. It removes no material and changes no outside dimensions or functional drills. `spider-rib-decision.json` binds the approved source hash `00835f3a5db6cec4806d0747d274c7c65dff0e1f0f0a8c79316b488f6e5c870e`, the captured body from `spider-channel-erratum.json`, the exact ribbon/addition hashes, and the affected original hole-contour hashes. The initial addition measures **6.074302 mm²**; require the exact ribbon operation within existing numerical tolerances, with an upper area bound of **6.10 mm²**. The cap alone grants no authority to add material elsewhere.

Only original decorative hole indices **1, 6 and 16** are affected. The initial probe retains the board's connected piece and hole count, full radius-3.05 mm support disks before drilling, continuous upper/lower strips, backed top apertures and all functional drills. Its cumulative aperture loss versus approved Rev5 is **0.180907%**, below the unchanged **2%** Spider per-board budget. These are checks of the initial material proposal, not the completed routing/artwork pipeline.

Re-run the existing **1.0 mm cutter sweep over every center component** of the three affected remaining apertures. The bounded probe finds **0.215386 mm²** of additional unreached area on those apertures; it does not leave that area as an accepted machining discrepancy. Permit at most **0.25 mm²** additional material from this specific cutter-envelope correction, with each original hole/coordinate delta indexed, and at most **6.35 mm²** combined material addition. No arbitrary extra fill or edits to other apertures are authorized by this erratum. The 2% cumulative aperture-loss budget and all mechanical invariants still apply after this correction. The operator supplies a candidate contour, not a plunge/toolpath or strength proof; recheck actual access, internal corners, minimum material widths and native/CAM contours.

Keep the central paths of strokes **7/8** and their **0.280 mm** width. Move only the adjacent portions of guide strokes **98/101/103** to the following nominal offsets, retaining **0.251 mm** guide widths. For a directed central segment `(dx,dy)`, define the positive unit normal as `(-dy,dx)/length`.

| Central segment | Guide | Signed center offset mm |
| --- | --- | ---: |
| stroke 7 | 98 | +0.5165 |
| stroke 7 | 101 | -0.5165 |
| stroke 8 | 101 | -0.5165 |
| stroke 8 | 103 | +0.5165 |

In a straight 2.0 mm section, these positions provide **0.251 mm black channels** and **0.358 mm outer mask clearance**: `0.358 + 0.251 + 0.251 + 0.280 + 0.251 + 0.251 + 0.358 = 2.000`. These are nominal targets; all guide ends and transitions must independently meet the existing 0.25 mm positive-gold/negative-mask widths and 0.35 mm mask clearance. Limit transition displacement to **0.50 mm** from the indexed original guide portions, inside the ribbon buffered by 0.50 mm; retain every other portion of these closed guide paths. Preserve the radial motif, all nine rim cores, flat gold appearance, and mask/finish/layer order. Rebuild copper only after validating the final mask.

Compose this operation with the prior channel erratum explicitly. Its four authorized gold patches and <=30.0 mm² gold-addition cap remain unchanged. The rib/guide change envelope is disjoint from those patches. Evaluate source/hash bindings at the relevant intermediate pipeline stage; only the newly authorized rib-local body and guide deltas may differ when comparing to that prior captured Spider state. Account for the differences in a separate ledger. This is not permission to broaden either erratum or to treat every later Spider shape as equivalent.

Issue 15 must provide complete indexed deltas, cumulative aperture metrics, updated support/bridge/backing/one-piece checks, cutter-center/plunge/toolpath evidence, positive-gold and negative-mask width proofs including transitions, and full-board/enlarged comparisons of the corrected geometry and finished appearance. Issue 16 must independently verify regenerated native PCB and CAM output. `spider-rib-comparison.png` shows only the initial material addition; planned artwork locations are a cross-section budget, not accepted final artwork. Regenerate the bounded evidence and figure with:

```sh
uv run --python 3.13 --with shapely==2.1.2 --with pillow python artwork-resources/pcb-art/manufacturing/probe_spider_rib.py
```

No production or factory acceptance is granted. Do not silently accept excess area, a new aperture closure, a support regression, a failed transition, or a failed cutter-access check; record the exact evidence for a further bounded decision if required.

## Spider L01 complete-network amendment — 2026-09-25

Historical scope: superseded by the unfiltered-network correction below. Its survey excluded wide central gold intervals and missed remaining channels.

This amendment **supersedes the material, affected-aperture and guide-portion scope of the earlier 7/8 rib erratum**. Retain its evidence as history. Apply the complete network once from the captured pre-rib body in `spider-channel-erratum.json`; do not add the old 6.35 mm² allowance to the new allowance. The four channel-merge patches, their exact envelopes and their <=30.0 mm² gold cap remain unchanged. No other board or process rule changes.

The reproducible survey in `spider-network-decision.json` binds the immutable approved source and `spider-network-input.json`, a captured diagnostic candidate, not approved output. Normal sections at <=0.20 mm intervals locate **38 sustained runs below 0.13 mm** (369.509 channel-mm) and **46 interior runs below 0.25 mm** (483.324 channel-mm), across 12 and 14 connected black regions respectively. Each run records the source segment, adjacent guide, position, width range and connected-region hash. These are genuine long channels, not an inference from erosion component counts. Five outer-rim taper flags on 74/75/80/88/91 remain separate indexed terminal checks under the existing rim policy; this amendment permits no extra material there. The survey is not an exhaustive final-width certificate.

### Exact material operation

Add 2.0 mm ribbons, **flat caps and miter joins**, along all points of approved source paths **2, 3, 4, 5, 6, 9, 10, 15, 16, 17, 18, 25, 27, 31, 34, 36 and 39**. Include the earlier **7/8** path as one continuous mitered ribbon, once. Use the exact coordinates and hashes in the decision evidence; no extensions, freehand patches or width changes. Union this network with the hash-bound pre-rib body without material removal. Initial addition is **73.921152 mm²**, including the earlier **6.074302 mm²**. The additional ribbon area relative to the captured survey body is **67.846462 mm²**; that is an explanatory comparison, not the operation's baseline or a second budget.

Only original decorative apertures **0, 1, 2, 3, 5, 6, 7, 11, 12, 13, 14, 15, 16, 17 and 18** change. Preserve apertures 4/8/9/10 exactly. On each affected post-union aperture `A`, compute every component of `C = A.buffer(-0.5, quad_segs=64)` and retain the aperture `C.buffer(0.5, quad_segs=64).intersection(A)`. This exact cutter-envelope cleanup adds **2.208271 mm²**, for **76.129423 mm² combined addition** relative to the pre-rib body. The evidence binds each aperture, cleanup delta and final shape by normalized WKB hash; the numeric maxima in policy allow only the existing 0.00001 mm² arithmetic tolerance. An area cap alone never authorizes another shape. Do not repeat cleanup until an arbitrary result converges, transfer budget between apertures or change an unaffected aperture.

After the measured cleanup, cumulative aperture loss versus approved Rev5 is **1.215701%**, within the unchanged **2%** cap. The probe preserves 19 decorative apertures, all eight functional holes/slots, one material component, exact outer dimensions, full pre-drill radius-3.05 mm support disks, upper/lower bridges and backing. Material is only added, so existing material ligaments and the unchanged lower floor cannot shrink. All 19 apertures retain one nonempty connected 1.0 mm cutter-center region and a contained plunge disk. This establishes geometric access feasibility; final serialized contours, finite cutter paths, native/CAM output and actual manufacturing remain separate gates.

### Indexed guide relocation and transitions

Keep all central radial paths and their 0.280 mm width. The following table lists adjacent guide indices on the negative/positive normal sides of each directed approved path; normal is `(-dy,dx)/length`:

| Central path | Negative guide | Positive guide |
| --- | ---: | ---: |
| 2 | 104 | 109 |
| 3 | 105 | 106 |
| 4 | 98 | 104 |
| 5 | 103 | 105 |
| 6 | 95 | 98 |
| 7 | 101 | 98 |
| 8 | 101 | 103 |
| 9 | 96 | 95 |
| 10 | 100 | 101 |
| 15 | 103 | 99 |
| 16 | 103 | 102 |
| 17 | 108 | 103 |
| 18 | 107 | 103 |
| 25 | 106 | 103 |
| 27 | 105 | 103 |
| 31 | 100 | 103 |
| 34 | 102 | 103 |
| 36 | 107 | 103 |
| 39 | 110 | 103 |

The evidence freezes **50 guide portions** by original contour hash, edge index, clipped original endpoints and corresponding central-segment interval. Place their straight centerlines at **±0.5165 mm**, retaining **0.251 mm** guide gold. The greatest nominal move from the approved guide is **0.140923 mm**; all nominal portion strokes fit the measured 0.35 mm mask-safe region. The evidence also provides **125 per-segment cross sections**. The straight-section budget is unchanged: `.358 clearance + .251 gold + .251 ink + .280 gold + .251 ink + .251 gold + .358 clearance = 2.000 mm`.

Only these portions and their endpoint transitions may change. A transition must lie in both the network ribbon buffered by **0.50 mm** and the **0.50 mm neighborhood of that indexed original portion's endpoint**. Its centerline remains within **0.50 mm** of the indexed original guide; preserve every other portion of the manufacturing guide paths. Split shared edge 101:1 at the 7/8 junction and use the corresponding miter intersection, rather than moving the whole edge twice. At other consecutive portions, use bounded miter/rounded joins with independently compliant gold and ink widths; nominal straight sections do not certify joins.

Rounded ink terminals are permitted only as an indexed cap of the **same existing channel**, with a full >=0.25 mm disk at the terminal and no positive-length sub-width approach. They must retain protected radial gold, guide strands, all nine rim cores and the channel's existing connectivity; do not create a new enclosed ink pocket, erase a channel or extend any of the four older gold-merge patches. A short cross-sectional chord through the end of a valid round cap is not itself a thin branch. Prove the complete terminal/approach boundary; do not exempt a channel because a larger disk fits elsewhere. Reject any transition that needs a larger envelope, loss of a strand, alteration of an unrelated guide or a new connection. Record that blocker for a decision, not an automatic repair.

The new network envelope can overlap the older patch neighborhoods at junctions; the old claim of disjointness applied only to the 7/8 ribbon. **The four actual gold patch geometries still remain unchanged.** Reconcile intermediate-stage hashes and separately ledger all new material, guide and terminal changes. Preserve the approved radial motif and flat gold appearance. Rebuild hidden copper only after final mask validation; all 0.25 mm copper/gold/ink rules and 0.35 mm mask setbacks remain in force.

Require full-board and enlarged **actual finished-art** comparisons, both-phase within-component width proofs, exact indexed geometry checks, support/bridge/backing/registration invariants, cutter-center/plunge/finite-path evidence and independent native/CAM checks. `spider-network-comparison.png` compares material only and does not approve the finished artwork. Reproduce the decision and its tests with:

```sh
uv run --python 3.13 --with shapely==2.1.2 --with pillow python artwork-resources/pcb-art/manufacturing/probe_spider_network.py
uv run --python 3.13 --with shapely==2.1.2 --with pillow python -m unittest discover -s artwork-resources/pcb-art/manufacturing/tests -p 'test_spider_network.py'
```

No production or factory acceptance is granted. This amendment retains the conservative process targets; it is not a process-class relaxation and cannot pass any measured 0.08 mm channel.

## Spider L01 unfiltered-network correction — 2026-09-25

**This is the current material and guide scope.** Erratum `spider-l01-unfiltered-network-2026-09-25` supersedes the preceding complete-network amendment's incomplete 17-path addition, its affected-aperture list, 50-portion list and material totals. The earlier 7/8 ribbon remains included exactly once. Preserve all earlier evidence as history and all four original gold-merge patch geometries unchanged. Their <=30.0 mm² budget does not fund terminal changes. No other board or process rule changes.

The preceding survey wrongly skipped a channel whenever its central gold interval exceeded 0.31 mm; an opposite-side gold merge can widen that interval without repairing the remaining black channel. The corrected survey checks **every approved source stroke 0–94 and both adjacent sides**, using the captured post-patch mask topology with no central-width exclusion. It records **64 sustained interior runs below 0.25 mm, including 48 below 0.13 mm**. This adds 18 / 10 runs respectively to the historical totals. Sections are at most 0.20 mm apart and a sustained run is at least 1 mm. The five rim flags on 74/75/80/88/91 remain mandatory separate terminal checks. This survey locates sustained defects; it does not certify unsampled boundaries, endpoints or final artwork.

`spider-complete-decision.json` binds approved source SHA256 `00835f3a5db6cec4806d0747d274c7c65dff0e1f0f0a8c79316b488f6e5c870e`, the original pre-rib body, historical survey input, original path coordinates/contour hashes, every material delta, and the local terminal input `spider-complete-input.json`. The last capture derives from mask candidate SHA256 `a27ad404f0e12b5291b0a31d9c7b02681fa5401e3fd20e7716d0bd910ac27225`; it is a diagnostic checkpoint, not an approved manufacturing file. The probe and exporter hashes are also frozen.

### Corrected exact material and guide set

Union **2.0 mm flat-cap/miter ribbons** along complete approved paths **0, 1, 2, 3, 4, 5, 6, 9, 10, 11, 12, 13, 14, 15, 16, 17, 18, 19, 20, 21, 22, 23, 24, 25, 27, 31, 33, 34, 36, 38, 39, 41**, plus the continuous **7/8** ribbon once: **34 source paths total**. Use exactly the evidence coordinates, without path extensions or material removal, from the pre-rib captured body. Initial material addition is **112.960935002 mm²**. All original decorative apertures **0–18** now change; the previous preservation requirement for apertures 4/8/9/10 is superseded by these exact changes.

For each of those 19 post-ribbon apertures `A`, perform the existing one-pass, all-center-component cleanup: retain `A.intersection(A.buffer(-0.5, quad_segs=64).buffer(0.5, quad_segs=64))`. Its exact measured material addition is **3.429195687 mm²**, combined **116.390130688 mm²** versus the pre-rib body. Policy maxima allow only 0.00001 mm² arithmetic tolerance. Enforce the per-aperture cleanup/final hashes and the final body hash; neither an equal area nor repeated cleanup authorizes another shape. Cumulative aperture loss is **1.810398%** versus approved Rev5, below the unchanged **2%** limit.

Keep the preceding table's guide sides and add only these missed sides (normal `(-dy,dx)/length`):

| Source path | Side | Adjacent guide |
| --- | ---: | ---: |
| 0 | − | 109 |
| 1 | − | 106 |
| 11 | + | 96 |
| 12 | + | 100 |
| 13 | − | 99 |
| 14 | − | 102 |
| 19 | + | 108 |
| 20 | + | 107 |
| 21 | − | 113 |
| 22 | − | 110 |
| 23 | + | 113 |
| 24 | + | 110 |
| 33 | + | 103 |
| 38 | + | 103 |
| 41 | + | 103 |

The resulting **68 original edge-indexed guide portions** and **215 material cross sections** are enumerated in the evidence. Preserve central radial artwork at 0.280 mm, use 0.251 mm guide gold at signed 0.5165 mm offsets, and retain nominal 0.251 mm ink and 0.358 mm outer clearance. These nominal budgets and all portions fitting the 0.35 mm safe region establish proposal feasibility, not final union-width proof.

Map each portion using its **original edge index, local clipped interval and corresponding endpoints**. Join consecutive relocated edges at their actual line intersection. Never remap the whole closed guide by normalized contour arclength: changed lengths can connect a portion to the wrong source corner. The evidence lists **19 bounded miter joins**, including the 13 previously measured joins; maximum displacement is **0.183809 mm**. Guide100's source31/10 join is explicitly `(63.223765345,62.581985559)` mm, **0.136550 mm** from original vertex `(63.0875,62.5908)`. Shared guide101 edge1 must still be split at the 7/8 correspondence. Retain all unrelated guide portions.

### Exact guide103/source31 rounded transition

At original guide103 edge27 endpoint `(62.3351,62.7319)`, the straight extrapolated miter would move 0.874289 mm and is forbidden. Replace only the captured local reverse jog with this cubic, sampled into **64 segments**:

| Point | x mm | y mm |
| --- | ---: | ---: |
| P0 | 62.181101247 | 62.580686103 |
| C1 | 62.173142711 | 62.609611208 |
| C2 | 62.197407281 | 62.735236294 |
| P3 | 62.204648978 | 62.764349140 |

Use full precision from the evidence. Maximum measured source-guide displacement is **0.148507 mm**, within 0.50 mm. The curved paint change is inside the old 0.50 mm endpoint neighborhood. It reconnects the captured candidate-created ink pocket to its existing channel (82→81 ink components in this local experiment), with no gold connection or strand deletion. This permits only that indexed connectivity correction, never deletion of an approved black facet or arbitrary trapped pocket.

The curve alone leaves a pointed ink terminal that extends beyond the 0.50 mm endpoint neighborhood. Permit **only the three geometry-bound paint-cap polygons** in `terminal.caps` of the evidence, with their exact normalized WKB hashes and coordinates. Their combined area is **0.047654677 mm²**, including **0.000584674 mm²** outside the old 0.50 mm neighborhood; maximum endpoint distance is **0.542619 mm**. These polygons alone may occupy the **0.55 mm** endpoint neighborhood. This is not an interchangeable area budget or permission to enlarge other transitions. Guide displacement and every other transition envelope remain <=0.50 mm; the network ribbon-plus-0.50 mm bound and 0.35 mm mask-safe setback remain mandatory.

The caps are derived once from the captured curved ink minus its union of radius-0.125 mm disks (64 segments per quadrant). Do not apply this opening globally or repeatedly. After 0.000001 mm-grid serialization, the local ink differs from that full-width disk-union reference by **0.000000346 mm²** and **0.000018096 mm** Hausdorff distance. The additional complete-terminal check extends that proof region over all three caps plus a 0.001 mm boundary neighborhood, covering their tails outside 0.50 mm as well as the full local approach. Check both the complete approach and terminal boundary; unrelated corners inside the 0.55 mm viewing circle are not additional authorized caps. A polygonal round cap can produce small re-opening residue, so use the explicit disk-union boundary comparison as well as both-phase connected-core and miter-residue screens. The local gold/ink screens measure **0.000000935 / 0.000000073 mm²**; gold remains five components with five eroded cores, and cap application retains all 81 curved-ink components. The probe preserves radial gold, nine rim cores, prior four patches and the safe region. These measurements prove this bounded terminal on the captured diagnostic artwork; they do not prove the complete final 68-portion mask or copper.

### Retained implementation gates

The full material probe retains all **19 decorative apertures**, eight functional holes/slots, exact dimensions, one component, full pre-drill radius-3.05 mm support disks, bridges, lower floor and backing. Every aperture retains a connected 1.0 mm cutter-center region and contained plunge disk. Recheck these invariants, finite cutter paths and swept coverage on actual serialized output. Keep source/history immutable, the approved radial motif, all nine rims, all four earlier patch geometries, 0.25 mm positive-gold/negative-mask/copper widths and 0.35 mm mask clearance. No generalized width or process-class relaxation is authorized.

Issue 15 must account for all 68 relocated portions and every transition, verify complete final gold/ink/copper widths and topology, and supply full-board/enlarged material and actual finished-art comparisons. Regenerate native output and require issue 16's independent CAM checks. `spider-complete-comparison.png` compares the complete material proposal and this one local terminal; final-art and factory acceptance remain pending. A failed invariant or excessive transition remains a blocker. Reproduce this bounded evidence and its light tests with:

```sh
uv run --python 3.13 --with shapely==2.1.2 --with pillow python artwork-resources/pcb-art/manufacturing/probe_spider_complete.py
uv run --python 3.13 --with shapely==2.1.2 python -m unittest discover -s artwork-resources/pcb-art/manufacturing/tests -p 'test_spider_complete.py' -v
```

## Process-class amendment — 2026-09-25

Owner-approved correction to the universal 0.25 mm art target, recorded as policy erratum `process-classes-2026-09-25`. The published sources and the limits of each claim are in `process-class-sources.json`: JLCPCB general 1 oz copper is 0.10/0.10 mm. Uncovered coils, hatched grids and same-net spacing are 0.25 mm. The black/white mask bridge is 0.13 mm. `rulesMm` is unchanged and remains the default for every feature this amendment does not match.

| Feature | Minimum |
| --- | ---: |
| Copper of the four full-gold lower pours (Spider L03/L05/L07, Coral L04) | 0.10 width / 0.10 gap |
| Isolated convex copper island (no interior ring, convex-hull deficit ≤ area tolerance, re-evaluated on final copper) | 0.10 width / 0.10 gap |
| Gap between components of different classes | larger of the two class widths |
| All other copper, including unnetted decorative networks and channels inside one connected component | 0.25 |
| Black mask web, Coral/Fault/Kumiko/Woven | 0.13 |
| Black mask web, Spider (all layers) | 0.25 |
| Visible gold window | 0.25 |

The 0.13 mm black web holds only if the mask is ordered unchanged, with no automatic expansion, gang-opening conversion, dam removal or facet deletion. Final CAM/process confirmation remains external and pending. Spider's stronger repairs stay in force.

`probe_process_classes.py` classifies a native candidate read-only and writes `process-class-decision.json` plus `process-class-comparison.png`. The measured candidate's file hashes are bound in the erratum. The snapshot classifies 44 general copper features and records six fixed cross-section witnesses that still fail their applicable class, including Kumiko L01 ink at 0.021 mm, Coral L01 visible gold at 0.087 mm and three copper-free gaps near 0.1 mm between retained-special components that need 0.25 mm. Both a 0.10 and a 0.25 mm negative-copper core screen are recorded; the witnesses are examples, not a complete failure list. Reclassification waives none of them; issue 15 must repair each one locally or prove it within the 0.001 mm tolerance. Re-measure from repository root with `PROCESS_CLASS_NATIVE_DIR=<native manufacturing dir> uv run --python 3.13 --with shapely==2.1.2 --with pillow python -m unittest discover -s artwork-resources/pcb-art/manufacturing/tests`. This amendment is not a production approval.

## Separate manufacturing artifacts and tests

Never modify `preview-source/assets/geometry.json`, `reference-revision4.json`, `reference-revision3.json`, the historic tests, or imported evidence to make corrections pass. In particular, `preview-source/tests/rev5_gold.py` continues to compare the approved Rev5 and immutable Rev4 inputs, retaining exact physical/lower-art assertions. New manufacturing code must load the frozen input, apply explicit indexed deltas, and emit **a separately named manufacturing geometry artifact** with provenance. Do not repoint the reference test, preview, manifest or screenshots to corrected shapes without labeling the artifact's role. The production exporter must read that new artifact explicitly.

`mask-repair-candidate.json` is a large generated intermediate. It is ignored by Git and rebuilt from the tracked manufacturing geometry, frozen policy, indexed validation/erratum records, `repair_mask_candidate.py` and `tools/export_kicad.py`. Before native-board generation or candidate-dependent checks on a clean checkout, run:

```sh
bash "$HOME/.codex/scripts/heavy-guard.sh" -- \
  uv run --python 3.13 --with shapely==2.1.2 --with pillow \
  python artwork-resources/pcb-art/manufacturing/repair_mask_candidate.py
shasum -a 256 artwork-resources/pcb-art/manufacturing/mask-repair-candidate.json
```

The candidate must match `maskCandidateSha256` in `native-generation.json` (`abc95a8df4c5b83cdd727136260e8321cb04a4f71ab7ae7883d9c4cd75c61689` for the recorded native-board release). Stop if the hash differs; do not update the native record just to accept different generated geometry. The native board files remain the editable, committed fabrication sources.

Named downstream gates (equivalent test-file naming is acceptable; the assertions are mandatory):

| Gate | Owner and required assertions |
| --- | --- |
| `reference-history` | #15: run unchanged `preview-source/tests/rev5_gold.py` and existing revision geometry tests on approved inputs; all frozen input hashes match |
| `manufacturing-inventory-and-registration` | #15: selected 43 / alternative 9; exact palette/finish/layer order, dimensions, NPTH centers and top-only slots |
| `manufacturing-indexed-deltas` | #15: bijective ledger ↔ actual geometry/art differences, original index/hash/coordinates, all 56 closures and ligament resolution, all selected art findings dispositioned; alternatives unchanged |
| `manufacturing-material-and-tool-access` | #15: support disks before drills; after-drill connectivity, full bridges, floor, backing, opposed-boundary width and residue checks; center-region access, plunge/path and swept-envelope coverage for every aperture; contour/radius/width checks on emitted geometry |
| `manufacturing-art-and-appearance` | #15: union-level copper widths/gaps, black web and visible gold widths, containment/setbacks, preserved facet paint and nine top rims, budgets, nesting and Woven path distinctness; compare every changed design |
| `native-and-cam` | #16: actual native load/DRC of 52 boards with alternatives segregated; all 43 selected Gerber/Excellon outputs independently parsed/rendered; output hashes tied to all geometry/art/NPTH rules; proper layer polarity and no drill-outline duplication |
| `panel-membership-yield-and-scores` | #17: exact groups, finish identity, rail/score corridors, translations only, all board output contours/art/drills preserved after depanelization, quantities and waste; native and actual panel CAM verification |

`probe_decision.py` is reproducible **decision evidence**, not the production implementation of those gates. It evaluates local cutter-envelope candidates for 43 boards and verifies support disks, bridges, floor, top backing, nesting, connectivity and distances between distinct boundaries. It deliberately makes **no full local-width, final-art or real toolpath claim**. `decision-probe.json` records the result and original hole indices. `decision-comparisons.png` shows every selected top, H11 and the ligament, plus an indexed Kumiko mask-retreat example. `top-border-comparisons.png` enlarges the upper rims of all five designs; the probe checks the 0.25 mm core and closed annulus for all 45 top borders. The selected Coral collar correction is included in the before/after views. The mask-web example demonstrates the local operation, not a fully corrected mask. The all-board final comparison and union-level printability checks remain mandatory in #15/#16.

Reproduce this issue's light checks from repository root:

```sh
uv run --python 3.13 --with shapely==2.1.2 --with pillow --with numpy python artwork-resources/pcb-art/manufacturing/probe_decision.py
uv run --python 3.13 --with shapely==2.1.2 python -m unittest discover -s artwork-resources/pcb-art/manufacturing/tests -v
uv run --python 3.13 --with shapely==2.1.2 python artwork-resources/pcb-art/preview-source/tests/rev5_gold.py
```

## Lower packaging and permitted splits

Select **lead-free HASL** for every non-ENIG mask-only board. No exposed conductive art is added to make that finish visible. Separate masks and finishes even when both masks are black. Each unique board ID occurs once across its assigned layout, sorted lexicographically and placed row-major. Use only translation `(column × 101.3 + rail, row × 94.3 + rail − 17.1)`. All boards keep their original orientation and scale.

| Lower package | IDs per set | Grid | Sheet mm including rails | Unused cells | Sheets |
| --- | ---: | --- | --- | ---: | ---: |
| white / lead-free HASL | 7 | 2 × 4 | 212.6 × 387.2 | 1 | 25 |
| black / ENIG | 6 | 3 × 2 | 313.9 × 198.6 | 0 | 25 |
| red / lead-free HASL | 10 | 3 × 4 | 313.9 × 387.2 | 2 | 25 |
| green / lead-free HASL | 4 | 2 × 2 | 212.6 × 198.6 | 0 | 25 |
| purple / lead-free HASL | 1 | standalone | 101.3 × 94.3 | 0 | 25 |
| yellow / lead-free HASL | 1 | standalone | 101.3 × 94.3 | 0 | 25 |
| blue / lead-free HASL | 1 | standalone | 101.3 × 94.3 | 0 | 25 |
| black / lead-free HASL | 8 | 2 × 4 | 212.6 × 387.2 | 0 | 25 |

`policy.json` lists exact member IDs. Five **black ENIG tops stay individual routed boards** (25 each), with no tabs or scores on their outside edges. Singleton lower packages are individual lower packages; do not also order the individual reference exports of boards belonging to combined sheets. Base plan: **13 packages**, 325 ordered sheets/standalone units, **1,075 useful PCBs**: 125 tops + 950 lowers = 25 complete stacks of each design. The three unused grid cells per five-design set are explicitly blank substrate waste (75 cells across the order), never substitute boards, extra designs or useful yield.

For a multi-board sheet add **5 mm sacrificial rails on all four sides**; score along every internal row/column boundary and every rail/board boundary. Scores traverse the entire sheet, including waste cells and rails, with no stopped scores, steps or kerf spacing. Minimum parallel score spacing is **3 mm**, at most **25 per axis**, and sheets stay within **70–475 mm in both axes**. Rail width 5 mm makes the nearest parallel lines compliant. Draw scores on `Dwgs.User` and export a separate fabrication drawing; they are neither Edge.Cuts nor silkscreen. Route only the panel outside and decorative voids; retain one connected sheet before scoring. No PTH tooling holes or fiducials are introduced. No automatic plated pads or rule exemptions from Strip Mine.

Check a ±1.0 mm score corridor against every decorative aperture and full support disk, plus ≥0.50 mm copper and ≥0.55 mm visible-gold clearance to each seam. The outer lower rectangle is scored only; all decorative cutout edges stay cleanly routed. Final score residual-web depth, bending loads, handling of the large perforated sheets and ±0.4 mm scored outline tolerance are **pending CAM / physical-fit confirmation**. Scores are not evidence of precision routed outer edges. Assembly critical features are the separately drilled common centers. Do not claim the routing-size tolerance for scored boundaries.

The above grids are the default minimum package count by compatibility. **Permitted splits only:** if a panel fails an exact dimension, whole-line score corridor, handling/support or depanelization test, split that same color+finish group into smaller full rectangular grids along complete rows/columns; use 5 mm rails again, preserve each ID exactly once, and order 25 of each result. A one-board remainder becomes a routed singleton. Record failed measurement and resulting membership. Keep the ten-member cap, 475 mm limit and same board orientation. Do not create more panels merely to avoid declared multi-design fees. Do not mix finish/color, duplicate IDs to fill blanks, change board dimensions, score through apertures, use mouse bites on decorative edges, or introduce hand cutting as the default. A factory-specific refusal is pending external evidence, not a reason to silently replace this plan.

## Native KiCad, DRC and CAM verification — issue 16

`verify_native_cam.py` is the issue 16 gate. It verifies the exact native board hashes from `native-generation.json` for the 43 selected boards and the approved `pcb/manifest.json` hashes for the nine Kumiko standard reference alternatives. KiCad DRC opens all 52 native files. The alternatives have separate reports and remain non-orderable references; they are never mixed into the selected CAM result.

Run from the repository root with KiCad 10 available:

```sh
uv run --with-requirements artwork-resources/pcb-art/preview-source/requirements.txt \
  python3 artwork-resources/pcb-art/manufacturing/verify_native_cam.py \
  --execute \
  --output /tmp/zudo-blanks-issue16-native-cam \
  --export-selected \
  --evidence-dir artwork-resources/pcb-art/manufacturing
```

The runner records its installed CLI help and KiCad version, then runs `pcb drc --format json --units mm --severity-all --severity-exclusions --exit-code-violations` on every board. Selected projects are checked against the frozen 0.25 mm copper gap, 0.30 mm copper-to-route/drill clearance, and zero global mask expansion. There are no project-level DRC exclusions. The manufacturing-relevant `copper_edge_clearance`, `solder_mask_bridge`, and `shorting_items` rules are errors. The remaining ignored checks are limited to board-only NPTH footprints, absent courtyards/libraries, unused track/via checks and unused tuning profiles; the DRC JSON lists them for each board, and the separate CAM checks verify the physical geometry those inapplicable electrical rules cannot cover.

The initial full DRC run exposed KiCad outline errors on five selected native boards: sub-micron Edge.Cuts segments and self-intersections at short contour stubs. The native candidate generator removes segments below its serialized minimum; the five affected boards use scoped thresholds. It removes redundant collinear vertices only in the offending rings of Woven Maze L07 and Fault Line L08. The default and targeted thresholds are defined in `generate_native.py`; `native-generation.json` records the removed-segment count, maximum displacement and area change for each board. Every repaired ring must remain valid, with maximum contour displacement at or below 0.001 mm and total area change at or below 0.02 mm². This repair changes Edge.Cuts serialization only; decorative F.Cu/F.Mask geometry is unchanged.

KiCad 10 also reported an order-dependent self-intersection on Woven Maze L08 even though its source rings are valid. Rotating the start point of the affected Edge.Cuts ring to a smooth vertex changes only serialized line order; it preserves the exact contour and is recorded as a KiCad contour-seam workaround, not a geometry change.

The selected CAM command writes individual Gerber and separated Excellon output for all 43 selected boards, including the lower reference packages and all five standalone tops. The verifier parses the output coordinates and layer attributes directly. It checks the closed Edge.Cuts line loops against the native contours, the continuous rectangular outer route and absence of extra breakaway geometry, positive F.Cu/F.Mask region contours, copper support beneath every decorative mask opening, and the empty back copper layer. Back-mask output may contain only the mechanical NPTH mask apertures represented by the board's exact four round drills and, on tops, four oval slots; those flashes are checked separately from back artwork. NPTH hits and routed slots are parsed from the actual Excellon file and compared with the native pad geometry. Each top profile has no duplicate drill contours on Edge.Cuts.

The verifier checks native finish and mask-color metadata, hashes every exported CAM file, creates a local ZIP per selected board, and raster-renders a five-top appearance sheet from the parsed Gerber polygons and Excellon drills. A read-only parser smoke for an already-exported board can be run with `--verify-existing --board-id <manifest-id> --cam-dir <gerber-dir> [--drill-dir <excellon-dir>]`.

If all DRC and CAM checks complete but compact evidence needs to be regenerated, reuse the completed raw run without invoking KiCad or re-parsing CAM geometry:

```sh
uv run --with-requirements artwork-resources/pcb-art/preview-source/requirements.txt \
  python3 artwork-resources/pcb-art/manufacturing/verify_native_cam.py \
  --rebuild-evidence-from /tmp/zudo-blanks-issue16-native-cam-release/native-cam-run.json \
  --evidence-dir artwork-resources/pcb-art/manufacturing
```

This mode rechecks the raw DRC report contents and hashes, current native board/project hashes, CAM file hashes, package ZIPs and package manifests. It reuses the recorded CAM geometry checks, archives the original run record, and records the original execution verifier hash separately from the current evidence-builder hash.

Raw DRC reports, CAM folders, drill maps and per-board ZIPs stay at the local output path. The compact tracked outputs are `native-kicad-cam-report.json`, `native-kicad-cam-manifest.json`, and `native-cam-representative.png`. They bind results to the input manifest, selected native-generation record, policy, generator, execution verifier and evidence builder, pinned Python requirement file, Python/Shapely/Pillow versions, individual native board/project hashes, CLI version, raw DRC report hashes, and every selected CAM file/ZIP hash. A selected DRC violation, nonzero unconnected-item count, or selected output geometry mismatch blocks the local gate. Reference-alternative findings are retained separately.

These local reports do not approve factory CAM, quotes, orders or physical fit. The exhaustive all-boundary width certificate remains an opt-in diagnostic under the 2026-09-27 scope amendment.

## Readiness and remaining confirmation

This issue completes a local design decision and scoped comparisons. #15 implements and proves corrected geometry; #16 independently verifies native/output geometry; #17 verifies actual combined sheets and the order manifest. Buying, payment, vendor contact and manufacturing approval are outside this workflow.

Keep separate pending items for: actual tool availability and plunge/CAM strategy; mask registration and untouched black facets; finish/color availability in the quote (including lead-free HASL with no exposed art); ENIG area/routing/multi-design charges; scored-web handling and edge tolerance; thickness/spacer/screw/washer/nut tolerances and physical fit. Nominal stack depths are 33.8 mm for Spider/Coral (8 boards) and 38.4 mm for Fault/Kumiko/Woven (9). For 125 stacks the nominal hardware inventory is **500 screws, 3,800 spacers, 500 nuts**; washer type/count and screw usable length require hardware confirmation. Do not describe any of those external checks as passed.

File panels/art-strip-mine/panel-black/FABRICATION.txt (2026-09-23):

strip-mine-black-panel: 303.9 x 94.3 mm, 1.6 mm FR-4, 2 layers, 1 oz, black mask, ENIG.
Panel by customer; 3 DIFFERENT designs. One panel makes one stack's black lower boards.
V-SCORE ALL lines in the separate User_Drawings Gerber (KiCad Dwgs.User layer). These are NOT routed slots or silkscreen.
Route the outside perimeter and all inner pit contours from Edge_Cuts. No silkscreen.
Copper intentionally reaches the routed pit edges. Confirm this and V-score acceptance with CAM before manufacture.
Preserve finished sub-board dimensions 101.3 x 94.3 mm and all hole positions.
Panel contains no top board and no blue bottom board.

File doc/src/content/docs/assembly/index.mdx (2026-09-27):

---
title: Assembly
sidebar_position: 5
---

The stack and hardware quantities are planning records. Physical fit, usable screw length, finish appearance and handling remain to be checked with real samples.

<CategoryNav category="assembly" />

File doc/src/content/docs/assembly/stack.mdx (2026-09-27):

---
title: "Stack and Fastener Notes"
description: "Layer order, spacer counts, and assembly checks."
sidebar_position: 1
---

## Assembled dimensions

| Design | Boards | Gaps | 3 mm spacers | Boards plus gaps |
| --- | ---: | ---: | ---: | ---: |
| Spider Nest | 8 | 7 | 28 | 33.8 mm |
| Coral Vault | 8 | 7 | 28 | 33.8 mm |
| Fault Line | 9 | 8 | 32 | 38.4 mm |
| Kumiko Void | 9 | 8 | 32 | 38.4 mm |
| Woven Maze | 9 | 8 | 32 | 38.4 mm |

One spacer at each corner of every gap gives 152 spacers and 20 stack screw axes across all five designs. Recalculate if using threaded standoffs or a different support arrangement.

The preview assumes 6 mm outer-diameter spacers. Board tolerances, screw heads, washers, nuts, and thread allowance are not included. Choose final screw lengths against actual hardware and case dimensions.

## Assembly sequence

1. Sort PCBs by design, original board ID, layer number, and side.
2. Stack from the bottom up, adding one 3 mm gap and aligning all four holes.
3. Check the color sequence and keep the top gold frame facing outward.
4. Tighten the corners evenly and inspect for bowing or contact with narrow features.
5. Check rail, nut, and case-bottom clearance in the actual case.
6. Record photos and review color, sight lines, and hardware coverage.

Do not mix standard and wide Kumiko. Keep the narrowing Coral and Fault layers in the intended order.

## Record the physical result

Record spacer, screw, washer, and nut part numbers; actual stack height; board bow; and case fit. Review exposed routed edges and thin strands for contact with hands or cables.

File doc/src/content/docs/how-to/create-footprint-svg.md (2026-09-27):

---
title: Create Footprint SVG Files for Documentation
sidebar_position: 3
---

# Create Footprint SVG Files for Documentation

This guide explains how to export KiCad footprints to SVG format and prepare them for use in the documentation.

## Overview

The documentation can display footprint previews. This workflow converts KiCad `.kicad_mod` files to clean SVG images.

## Prerequisites

- KiCad 9.0.6 or later (with `kicad-cli` command)
- Python 3 (for cleanup script)

## Verify KiCad CLI

```bash
kicad-cli --version
# Should show: Version: 9.0.6 or later
```

If `kicad-cli` is not found, you need to add it to your PATH:

**macOS:**

```bash
export PATH="/Applications/KiCad/KiCad.app/Contents/MacOS:$PATH"
```

## Workflow

### Step 1: Prepare .pretty Directory

KiCad CLI requires footprints in a `.pretty` directory structure:

```bash
cd footprints/kicad

# Create .pretty directory
mkdir -p zudo-blanks.pretty

# Copy .kicad_mod files
cp *.kicad_mod zudo-blanks.pretty/
```

### Step 2: Export to SVG

Export all footprints to SVG format with black-and-white rendering:

```bash
cd footprints

# Export SVGs
kicad-cli fp export svg kicad/zudo-blanks.pretty -o images --black-and-white
```

**Output:** SVG files are saved to `footprints/images/`

### Step 3: Clean SVG Files

Remove KiCad placeholder text (REF\*\*, VAL\*\*) from SVGs using the cleanup script:

```bash
cd footprints

# Run cleanup script
python3 scripts/clean-svg-refs.py images/
```

### Step 4: Copy to Documentation

```bash
cd footprints

# Stage cleaned SVGs for the documentation site
cp images/*.svg ../doc/public/footprints/
```

## Directory Structure

```
project/
├── footprints/
│   ├── kicad/
│   │   ├── *.kicad_mod              # Original KiCad footprints
│   │   └── zudo-blanks.pretty/      # .pretty directory for export
│   │       └── *.kicad_mod
│   ├── images/
│   │   └── *.svg                    # Exported and cleaned SVGs
│   └── scripts/
│       └── clean-svg-refs.py        # Cleanup script
└── doc/
    └── public/
        └── footprints/
            └── *.svg                # Browser-facing SVGs
```

## Cleanup Script Details

### Location

`footprints/scripts/clean-svg-refs.py`

### What It Does

The script processes SVG files to remove KiCad placeholders:

1. **Text Elements**: Removes `<text>` elements containing `REF**` or `VAL**`
2. **Stroked-Text Groups**: Removes path-based text rendered as vector shapes
3. **Preserves**: All footprint geometry, pads, and silkscreen

### Usage

```bash
# Clean all SVGs in a directory
python3 clean-svg-refs.py /path/to/svg/directory/

# The script modifies files in-place
# Creates no backup - commit to git first!
```

## Troubleshooting

### Problem: kicad-cli not found

**Solution**: Add KiCad to PATH (see "Verify KiCad CLI" above)

### Problem: Export fails with "Library not found"

**Solution**: Ensure footprints are in a `.pretty` directory

### Problem: SVG still shows REF\*\* after cleanup

**Solution**:

1. Check that cleanup script ran successfully
2. Some SVGs may have additional text elements - inspect manually

## References

- [KiCad CLI Documentation](https://docs.kicad.org/master/en/cli/cli.html)
- [SVG Specification](https://www.w3.org/TR/SVG2/)

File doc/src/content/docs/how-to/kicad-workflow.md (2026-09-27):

---
title: KiCad Blank Panel Workflow
---

# KiCad Blank Panel Workflow

Workflow for designing blank panels in KiCad, from PCB layout to manufacturing files.

## Prerequisites

This example uses one older, single-board project under `panels/`. The five newer art stacks and grouped lower packages contain multiple native boards; see the [panel catalog](../catalog/) and [manufacturing records](../manufacturing/) for those projects.

```
zudo-blanks/
├── panels/
│   └── alumi-blanks-v1-3U-8hp/   ← Example panel project
│       ├── 8hp.kicad_pcb          ← PCB file
│       └── 8hp.kicad_pro          ← Project file
└── footprints/                    ← Shared footprint library
    └── kicad/
```

## Overview

Blank panels are simple PCB designs that skip most of the traditional KiCad workflow. Since there are no electronic components, you work primarily in the PCB Editor:

1. **PCB Editor** - Design the panel (outline, mounting holes, silkscreen)
2. **Manufacturing Output** - Generate Gerber files
3. **Review supplier output** - Check fabrication files and supplier requirements before any order

## Stage 1: PCB Layout

### 1.1 Set Board Dimensions (Edge.Cuts)

1. Open the PCB file in **PCB Editor**
2. Select **Edge.Cuts** layer
3. Draw board outline:
   - **Height**: 128.5mm (Eurorack 3U standard)
   - **Width**: choose the actual board outline for this project. HP × 5.08 mm is a nominal module pitch (8 HP = 40.64 mm), not a universal routed-width rule.

**Using the drawing tools:**

- Press `Ctrl+Shift+P` for polygon tool, or use line tool
- Enter exact coordinates in the properties panel for precision
- Ensure the outline is a closed shape

### 1.2 Place Mounting Holes

Add standard Eurorack M3 mounting holes:

1. Place footprint: Use a 3.2mm mounting hole footprint
2. Position holes:
   - **Top-left**: X=7.5mm from left edge, Y=3mm from top
   - **Top-right**: X=7.5mm from right edge, Y=3mm from top
   - **Bottom-left**: X=7.5mm from left edge, Y=3mm from bottom
   - **Bottom-right**: X=7.5mm from right edge, Y=3mm from bottom

For narrow panels (2-4 HP), use only one pair of holes (top and bottom center).

### 1.3 Add Silkscreen (Optional)

Decorative elements on F.Silkscreen layer:

1. Select **F.Silkscreen** layer
2. Add text, lines, or import graphics
3. Common elements:
   - Panel name or logo
   - Decorative borders
   - Version marking (small, bottom corner)

**Best practices:**

- Keep silkscreen away from mounting holes (1mm clearance)
- Use minimum 0.8mm text height for readability
- Test artwork visibility on dark solder mask colors

### 1.4 Design Rule Check (DRC)

Before generating output:

1. Inspect → Design Rules Checker
2. Run DRC
3. Fix any issues:
   - Board outline must be closed
   - Mounting holes properly placed
   - No silkscreen overlapping holes

## Stage 2: Manufacturing Output

### 2.1 Generate Gerber Files

1. File → Fabrication Outputs → Gerbers (.gbr)
2. Settings:
   - Include layers: F.Cu, B.Cu, F.Mask, B.Mask, F.Silkscreen, B.Silkscreen, Edge.Cuts
   - Coordinate format: 4.6, unit mm
   - Check "Use Protel filename extensions"
3. Click "Plot"

### 2.2 Generate Drill Files

1. File → Fabrication Outputs → Drill Files (.drl)
2. Settings:
   - Drill units: Millimeters
3. Click "Generate Drill File"

### 2.3 Verify with Gerber Viewer

1. Open **GerbView** (included with KiCad)
2. Load all Gerber files + drill file
3. Check:
   - Board outline correct dimensions
   - Mounting holes visible and correctly positioned
   - Silkscreen readable (not over holes)
   - Layers aligned correctly

## Stage 3: Prepare for Supplier Review

### 3.1 Prepare Files

Create ZIP archive with:

- All Gerber files (.gbr)
- Drill file (.drl)

```bash
# Example ZIP structure
gerbers.zip
├── F_Cu.gbr
├── B_Cu.gbr
├── F_Mask.gbr
├── B_Mask.gbr
├── F_Silkscreen.gbr
├── B_Silkscreen.gbr
├── Edge_Cuts.gbr
└── drill.drl
```

### 3.2 Check Supplier Configuration

1. Check the current supplier capabilities and quote conditions.
2. Upload the project's Gerbers and separate plated/nonplated drill data for CAM review.
3. Configure thickness, color, quantity and finish from that board's design and its project records. The newer art stacks mix ENIG and lead-free HASL and use several mask colors; do not apply one finish to every board.
4. Resolve supplier CAM questions and physical-fit requirements before placing an order.

## Workflow Summary

```
1. PCB Editor → Draw Edge.Cuts outline
   ↓
2. Place mounting holes
   ↓
3. Add silkscreen artwork (optional)
   ↓
4. DRC Pass
   ↓
5. Generate Gerber + Drill files
   ↓
6. Verify in GerbView
   ↓
7. Confirm supplier CAM, quote and physical fit before ordering
```

## Troubleshooting

### Common Issues

**Problem:** DRC shows "board outline not closed"

- **Solution:** Ensure all Edge.Cuts lines form a complete closed shape with no gaps

**Problem:** Mounting holes not appearing in Gerber

- **Solution:** Verify drill file was generated separately from Gerbers

**Problem:** Silkscreen not visible on manufactured board

- **Solution:** Check minimum line width (0.15mm) and text height (0.8mm) for JLCPCB

## References

- [KiCad Documentation](https://docs.kicad.org/)
- [JLCPCB PCB Capabilities](https://jlcpcb.com/capabilities/pcb-capabilities)
- [Eurorack Mechanical Specifications](https://doepfer.de/a100_man/a100m_e.htm)

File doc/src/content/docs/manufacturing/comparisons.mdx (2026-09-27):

---
title: Before and After Views
sidebar_position: 6
---

These paired images compare frozen Revision 5 **design geometry** with locally adapted **manufacturing candidate geometry**. They are not factory CAM approval. The [indexed delta ledger](https://github.com/Takazudo/zudo-blanks/blob/main/artwork-resources/pcb-art/manufacturing/indexed-deltas.json) and [candidate metrics](https://github.com/Takazudo/zudo-blanks/blob/main/artwork-resources/pcb-art/manufacturing/candidate-comparisons.json) record exact affected features and areas.

## Spider Nest

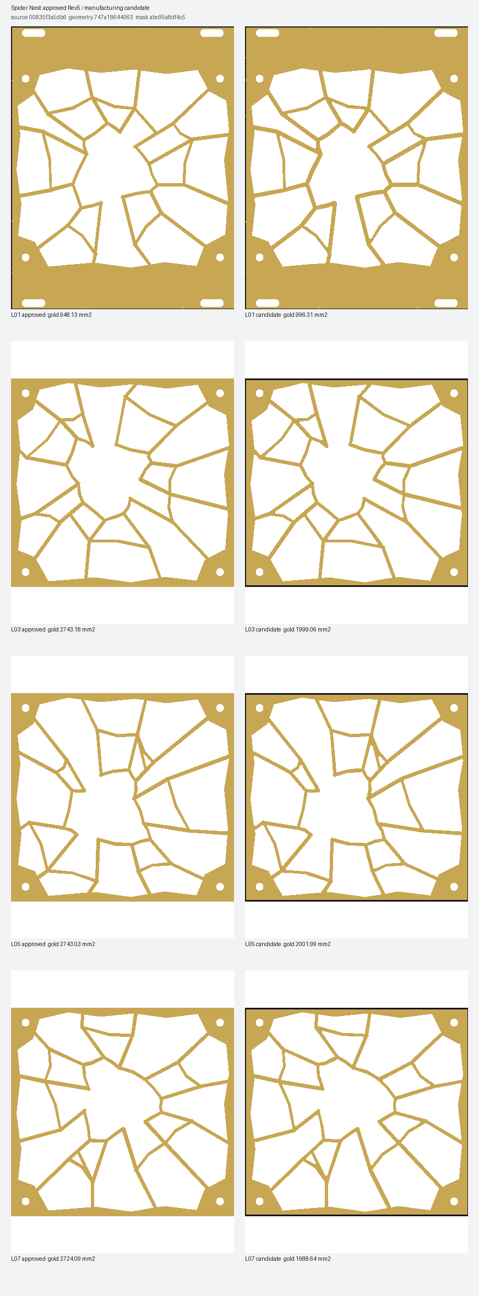
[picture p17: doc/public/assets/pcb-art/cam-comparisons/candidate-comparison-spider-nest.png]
Spider Nest source and locally adapted candidate


## Coral Vault

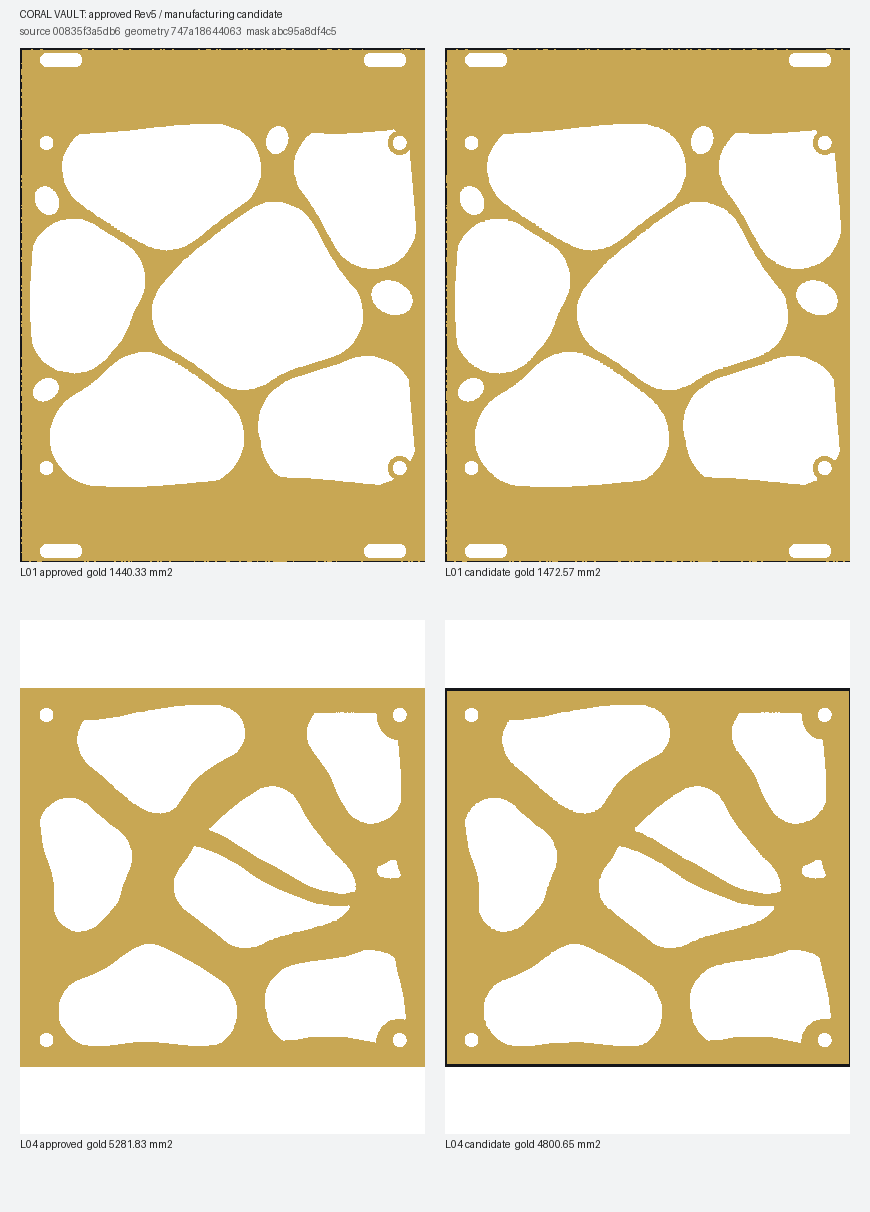
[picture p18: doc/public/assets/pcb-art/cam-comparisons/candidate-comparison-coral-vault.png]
Coral Vault source and locally adapted candidate


## Fault Line

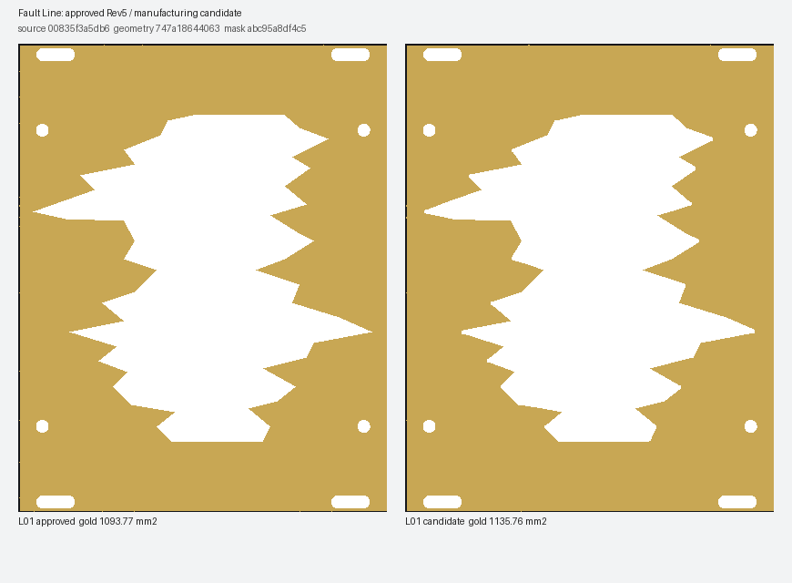
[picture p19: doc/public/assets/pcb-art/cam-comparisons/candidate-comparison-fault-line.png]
Fault Line source and locally adapted candidate


## Kumiko Void — selected wide

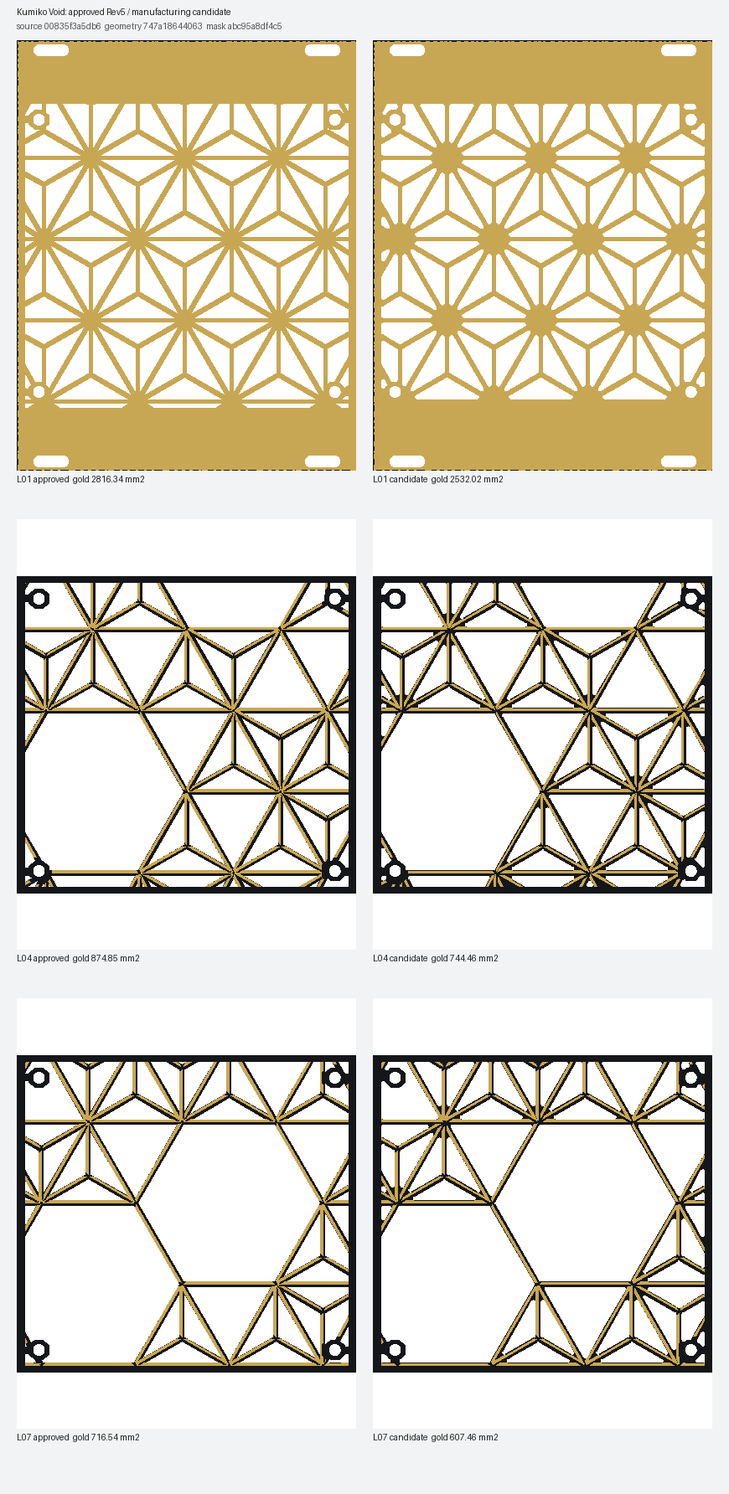
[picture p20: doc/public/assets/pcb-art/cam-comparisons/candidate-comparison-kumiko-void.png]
Wide Kumiko source and locally adapted candidate


The standard Kumiko model is a separate reference-only set; it is not represented by this candidate.

## Woven Maze

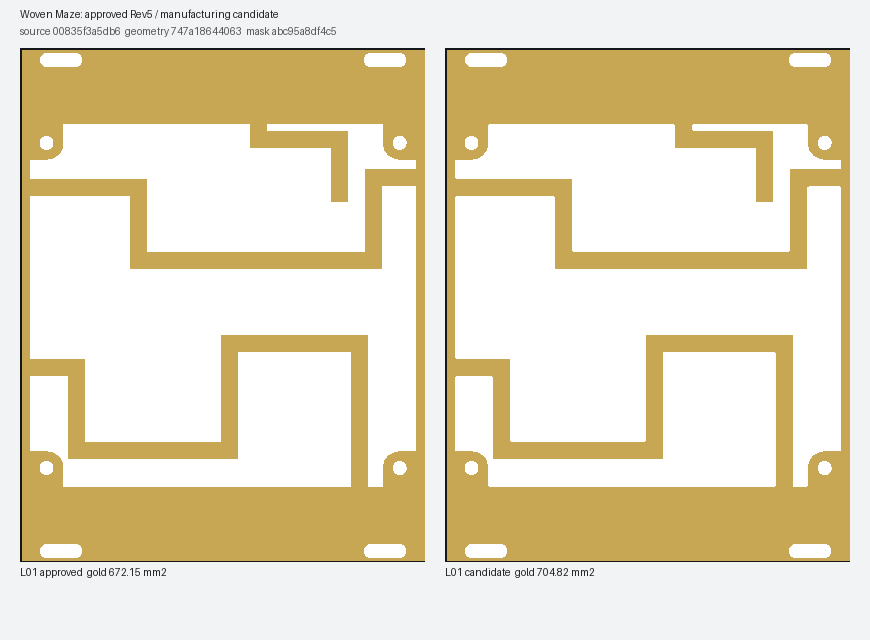
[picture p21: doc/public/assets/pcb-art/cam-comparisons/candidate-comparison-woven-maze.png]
Woven Maze source and locally adapted candidate


The <a href="/assets/pcb-art/previews/index.html">interactive 3D model</a> retains Revision 5 visual design geometry. For actual routed/mask layer checks use the [native KiCad/CAM report](https://github.com/Takazudo/zudo-blanks/blob/main/artwork-resources/pcb-art/manufacturing/native-kicad-cam-report.json) and board sources.

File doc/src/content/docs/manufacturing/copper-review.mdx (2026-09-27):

---
title: Copper, Mask and Gold Changes
sidebar_position: 2
---

The design viewer shows the approved Revision 5 gold concept. The manufacturing candidate retains its motif while locally retreating gold from routed edges, drills, and tight mask webs. Hidden copper joins preserve electrical continuity without making new visible gold; selected narrow tips were capped or locally repaired. The outer top frame and eight hole/slot rims remain closed on each selected top.

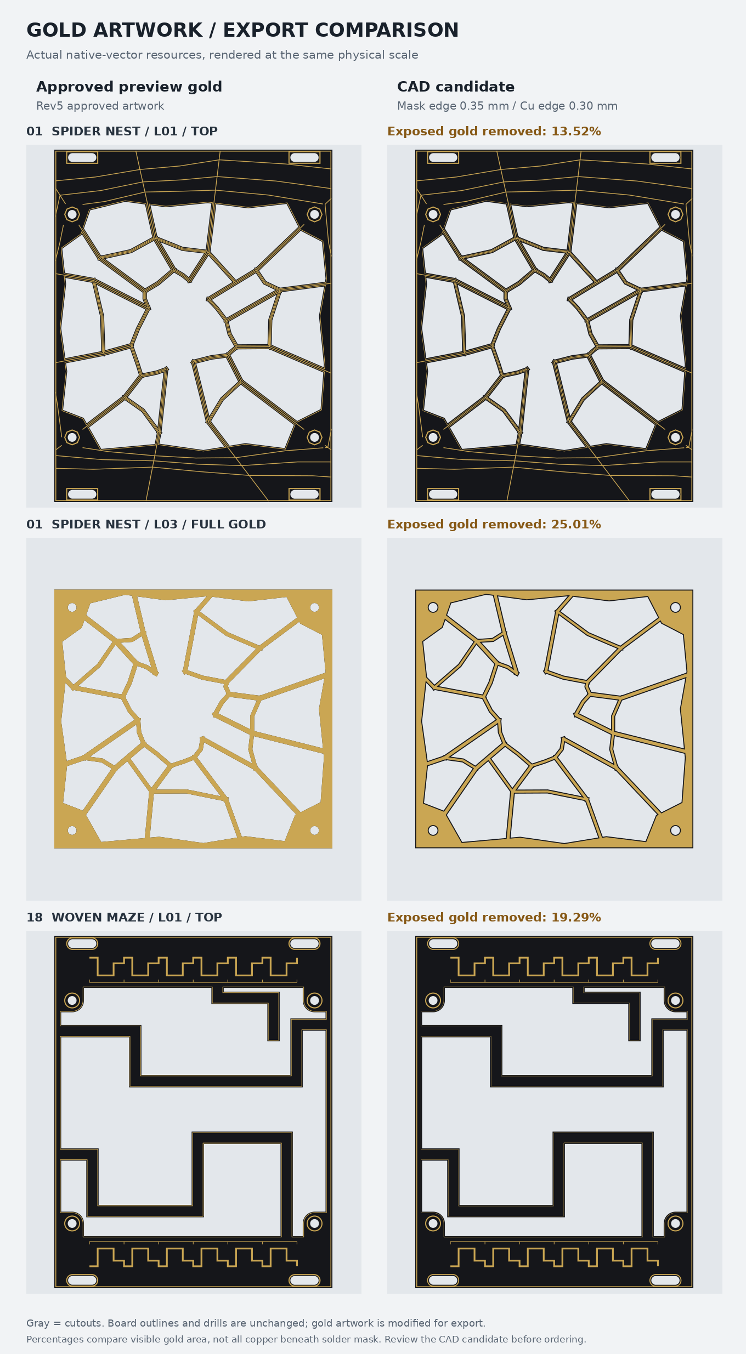
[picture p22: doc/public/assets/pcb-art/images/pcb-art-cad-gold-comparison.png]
Design art and original export candidate before local repair


The image above is a **before/after screen from the initial export**, not the final CAM rendering. Compare [indexed repair records](https://github.com/Takazudo/zudo-blanks/blob/main/artwork-resources/pcb-art/manufacturing/art-resolution-ledger.json), [candidate comparisons](https://github.com/Takazudo/zudo-blanks/blob/main/artwork-resources/pcb-art/manufacturing/candidate-comparisons.json), and [native CAM manifest](https://github.com/Takazudo/zudo-blanks/blob/main/artwork-resources/pcb-art/manufacturing/native-kicad-cam-manifest.json) for the locally checked result.

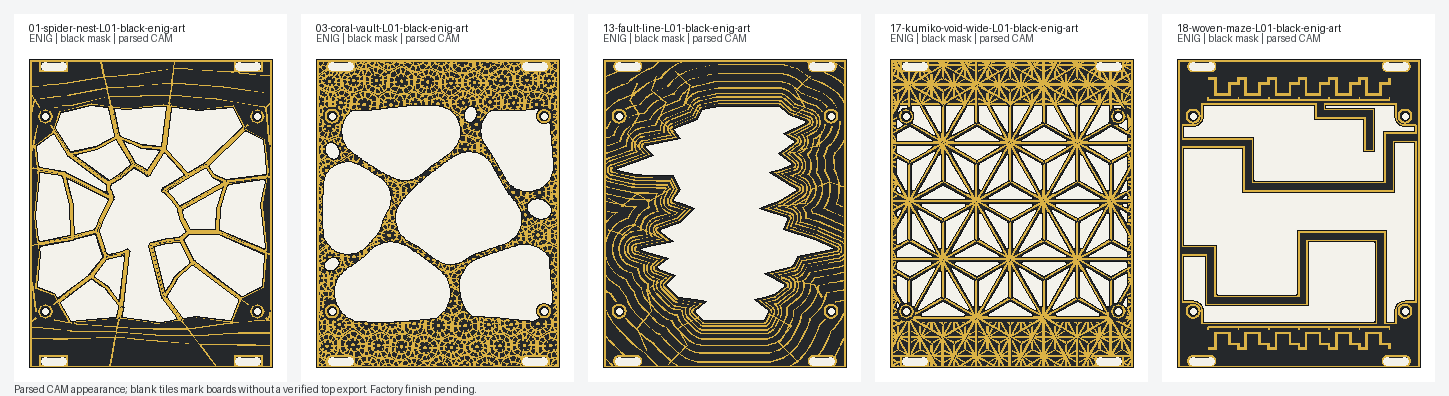
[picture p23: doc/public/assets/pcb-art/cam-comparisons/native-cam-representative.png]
Representative native KiCad CAM layers


The five [candidate before/after comparisons](./comparisons.mdx) show local geometry changes against the frozen design source. The representative CAM image above is a plotted layer check; supplier CAM inspection is still pending.

The [policy](https://github.com/Takazudo/zudo-blanks/blob/main/artwork-resources/pcb-art/manufacturing/policy.json) and [process-class amendment](https://github.com/Takazudo/zudo-blanks/blob/main/artwork-resources/pcb-art/manufacturing/process-class-decision.json) set a 0.35 mm visible-gold clearance from route/drill edges, 0.30 mm copper clearance, and 0.05 mm copper margin under openings. Finished visible gold and special copper/channel widths use the 0.25 mm class. Black mask webs use 0.13 mm on Coral, Fault, Kumiko and Woven tops when retaining their source mask, and 0.25 mm on Spider. Four full-gold lower pours and isolated convex copper islands use the 0.10 mm general copper class. These are locally chosen process rules, not supplier approval. The exhaustive width certificate is an opt-in check and has not passed.

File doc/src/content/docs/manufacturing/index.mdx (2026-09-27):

---
title: Manufacturing and Release Status
sidebar_position: 4
---

The selected five art stacks have **43 individual native boards**: Spider Nest 8, Coral Vault 8, Fault Line 9, Kumiko Void **wide** 9, and Woven Maze 9. The nine standard Kumiko boards are reference-only. Local KiCad 10 DRC and CAM checks passed for the selected native boards and five grouped lower sheets. These checks do not constitute factory acceptance.

The [order manifest](https://github.com/Takazudo/zudo-blanks/blob/main/artwork-resources/pcb-art/manufacturing/lower-panels-order-manifest.json) describes 13 packages for 25 complete stacks per design: 325 sheet or standalone order units, yielding 1,075 useful boards and 75 intentionally blank grid cells. It is a planning record. No boards have been purchased or accepted by a manufacturer.

The chosen policy uses two-layer 1.6 mm FR-4 and a 1.0 mm decorative router. The source Revision 5 design needed indexed local adjustments before the native checks. [Read the policy](https://github.com/Takazudo/zudo-blanks/blob/main/artwork-resources/pcb-art/manufacturing/policy.json), [candidate comparison](https://github.com/Takazudo/zudo-blanks/blob/main/artwork-resources/pcb-art/manufacturing/CANDIDATE.md), [individual CAM manifest](https://github.com/Takazudo/zudo-blanks/blob/main/artwork-resources/pcb-art/manufacturing/native-kicad-cam-manifest.json), and [grouped sheet record](https://github.com/Takazudo/zudo-blanks/blob/main/artwork-resources/pcb-art/manufacturing/lower-panels-order-manifest.json) for exact scope.

**Pending external checks:** factory CAM and scoring strategy, actual mask color and finish availability, quote, handling strength, hardware tolerance and physical fit. The exhaustive width certificate is opt-in and has not passed; do not describe it as complete evidence.

<CategoryNav category="manufacturing" />

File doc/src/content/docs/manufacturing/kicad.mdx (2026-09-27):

---
title: Native Boards and CAM
sidebar_position: 1
---

The five [design pages](../designs/) link each selected `.kicad_pcb` directly. The [native CAM manifest](https://github.com/Takazudo/zudo-blanks/blob/main/artwork-resources/pcb-art/manufacturing/native-kicad-cam-manifest.json) records the KiCad 10 version, board hashes, clean DRC reports, Gerber and Excellon checks. The [grouped lower README](https://github.com/Takazudo/zudo-blanks/blob/main/panels/art-grouped-lowers/README.md) describes five scored grids and their separate local verifier. Large CAM ZIPs stay local and ignored; regeneration commands and hashes are in the repository records.

| KiCad feature | Meaning |
| --- | --- |
| `Edge.Cuts` | Routed outer shape and decorative apertures on individual boards; grouped sheets route only their outer profile and decorative apertures |
| `Dwgs.User` on grouped sheets | Full-length V-score reference lines for fabricator review |
| NPTH pads | Mechanical stack holes and the top rail slots; exported separately from PTH |
| `F.Cu` and `F.Mask` | Positive copper and exposed-gold opening geometry on ENIG boards |
| Mask-only lower boards | No decorative copper or gold openings |

The five downloadable [top Edge.Cuts inspection vectors](/assets/pcb-art/vector/spider-nest-top-edge-cuts.svg) are generated from native boards. Other top vectors: [Coral](/assets/pcb-art/vector/coral-vault-top-edge-cuts.svg), [Fault](/assets/pcb-art/vector/fault-line-top-edge-cuts.svg), [Kumiko wide](/assets/pcb-art/vector/kumiko-void-top-edge-cuts.svg), [Woven](/assets/pcb-art/vector/woven-maze-top-edge-cuts.svg). These SVGs aid inspection at source aspect ratio; use the native PCB and verified CAM records for fabrication. The complete layer-specific SVG/DXF vector tree can be regenerated locally with [the source exporter](https://github.com/Takazudo/zudo-blanks/blob/main/artwork-resources/pcb-art/tools/export_kicad.py), but those Revision 5 vectors represent the design source before manufacturing adjustments.

Factory CAM approval, finished board review and physical fit remain external steps.

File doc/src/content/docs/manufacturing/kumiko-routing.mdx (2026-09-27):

---
title: Kumiko Routing and Variant Selection
sidebar_position: 3
---

The source screen found 56 small apertures in the selected wide set and eight in standard. The local manufacturing policy closes the 56 indexed **wide** apertures, adapts remaining corners for the chosen 1.0 mm cutter, and repairs local copper/mask details. The wide nine-board set then passed local native DRC and CAM checks. The standard nine-board set remains an unchanged, non-orderable reference alternative.

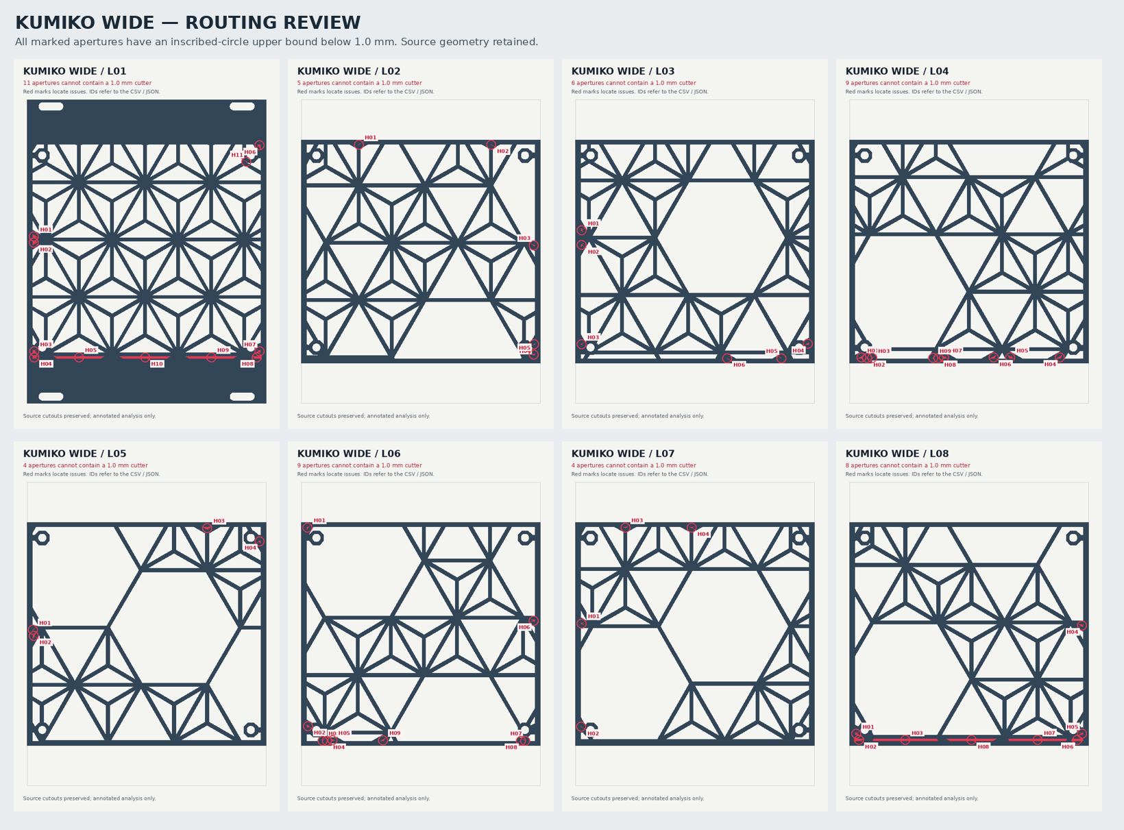
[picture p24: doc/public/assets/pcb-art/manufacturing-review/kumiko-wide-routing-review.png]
Original wide routing findings


[Original findings CSV](/assets/pcb-art/manufacturing-review/kumiko-routing-issues.csv) · [Indexed correction policy](https://github.com/Takazudo/zudo-blanks/blob/main/artwork-resources/pcb-art/manufacturing/policy.json) · [Selected native boards](https://github.com/Takazudo/zudo-blanks/tree/main/panels/art-kumiko-void) · [Standard reference boards](https://github.com/Takazudo/zudo-blanks/tree/main/panels/art-kumiko-void/alternatives/standard)

The image and CSV are **source review evidence** before correction. For the locally checked result, use the [candidate ledger](https://github.com/Takazudo/zudo-blanks/blob/main/artwork-resources/pcb-art/manufacturing/indexed-deltas.json) and [native CAM record](https://github.com/Takazudo/zudo-blanks/blob/main/artwork-resources/pcb-art/manufacturing/native-kicad-cam-manifest.json). The [design comparison](/assets/pcb-art/images/kumiko-void-variants.png) and interactive viewer show visual intent; they are not final CAM plots.

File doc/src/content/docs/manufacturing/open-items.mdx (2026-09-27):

---
title: External Checks Still Pending
sidebar_position: 5
---

Local design adaptation, native KiCad DRC/CAM and grouped sheet checks are recorded. Before any fabrication order, obtain factory CAM acceptance of routed apertures, NPTH slots and score lines; confirm mask colors, ENIG/HASL and empty decorative copper layers; obtain a quote; and build a physical fit sample for rail, screw, spacer and handling tolerances. The opt-in exhaustive width certificate is not passed.

[Chosen process policy](https://github.com/Takazudo/zudo-blanks/blob/main/artwork-resources/pcb-art/manufacturing/policy.json) · [Native CAM report](https://github.com/Takazudo/zudo-blanks/blob/main/artwork-resources/pcb-art/manufacturing/native-kicad-cam-report.json) · [Grouped package manifest](https://github.com/Takazudo/zudo-blanks/blob/main/artwork-resources/pcb-art/manufacturing/lower-panels-order-manifest.json)

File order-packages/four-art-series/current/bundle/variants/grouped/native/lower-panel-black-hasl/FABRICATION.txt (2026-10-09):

lower-panel-black-hasl: 212.6 x 198.6 mm. 2 layer FR-4, 1.6 mm, 1 oz, black mask, lead-free HASL.
Customer panel, 4 distinct lower-board designs; order 25 sheets.
V-score every full-length line from the separate Dwgs.User drawing. Scores are not Edge.Cuts or silk.
Route the outside and decorative apertures from Edge.Cuts; drill all NPTH mounts from Excellon.
Blank cells are waste. Preserve sorted row-major placement and finished 101.3 x 94.3 mm lower cells.
Scored outline tolerance is +/-0.4 mm. Web depth, handling, mask/finish and physical fit await factory CAM/quote review.

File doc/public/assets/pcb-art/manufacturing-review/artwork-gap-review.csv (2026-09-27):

boardId | feature | polygonA0 | polygonB0 | gapMm | pointAxMm | pointAyMm | pointBxMm | pointByMm | screenThresholdMm
17-kumiko-void-standard-L01-black-enig-art | F.Cu island gap | 0 | 40 | 0.03033513 | 40.72297094031123 | 17.694241656968146 | 40.6967 | 17.679074 | 0.1
17-kumiko-void-standard-L01-black-enig-art | F.Cu island gap | 0 | 54 | 0.03033513 | 68.72297094031123 | 17.694241656968146 | 68.6967 | 17.679074 | 0.1
17-kumiko-void-standard-L01-black-enig-art | F.Cu island gap | 0 | 26 | 0.03033513 | 12.722970940311232 | 17.69424165696815 | 12.6967 | 17.679074 | 0.1
17-kumiko-void-standard-L01-black-enig-art | F.Cu island gap | 0 | 49 | 0.030352 | 55.68205 | 26.3959 | 55.68205 | 26.365548 | 0.1
17-kumiko-void-standard-L01-black-enig-art | F.Cu island gap | 0 | 64 | 0.030352 | 83.68205 | 26.3959 | 83.68205 | 26.365548 | 0.1
17-kumiko-void-standard-L01-black-enig-art | F.Cu island gap | 0 | 35 | 0.030352 | 27.68205 | 26.3959 | 27.68205 | 26.365548 | 0.1
17-kumiko-void-standard-L01-black-enig-art | F.Cu island gap | 0 | 77 | 0.030361618 | 96.72299388165594 | 17.694202896059537 | 96.6967 | 17.679022 | 0.1
17-kumiko-void-standard-L01-black-enig-art | F.Cu island gap | 0 | 48 | 0.030368855 | 53.707553150042294 | 11.370084514127427 | 53.681253 | 11.3549 | 0.1
17-kumiko-void-standard-L01-black-enig-art | F.Cu island gap | 0 | 34 | 0.030368855 | 25.707553150042294 | 11.370084514127424 | 25.681253 | 11.3549 | 0.1
17-kumiko-void-standard-L01-black-enig-art | F.Cu island gap | 0 | 62 | 0.030368855 | 81.70755315004229 | 11.370084514127424 | 81.681253 | 11.3549 | 0.1
17-kumiko-void-standard-L01-black-enig-art | F.Cu island gap | 0 | 79 | 0.030376911 | 96.72300712684549 | 114.68908054117638 | 96.6967 | 114.673892 | 0.1
17-kumiko-void-standard-L01-black-enig-art | F.Cu island gap | 0 | 78 | 0.03038897 | 96.72301757299773 | 66.19166256729793 | 96.6967 | 66.176468 | 0.1
17-kumiko-void-standard-L01-black-enig-art | F.Cu island gap | 0 | 27 | 0.030401037 | 12.723028019149902 | 114.68904360703647 | 12.6967 | 114.673843 | 0.1
17-kumiko-void-standard-L01-black-enig-art | F.Cu island gap | 0 | 55 | 0.030401037 | 68.72302801914991 | 114.68904360703647 | 68.6967 | 114.673843 | 0.1
17-kumiko-void-standard-L01-black-enig-art | F.Cu island gap | 0 | 41 | 0.030401037 | 40.7230280191499 | 114.68904360703647 | 40.6967 | 114.673843 | 0.1
17-kumiko-void-standard-L01-black-enig-art | F.Cu island gap | 0 | 36 | 0.030408 | 27.682148 | 123.3907 | 27.682148 | 123.360292 | 0.1
17-kumiko-void-standard-L01-black-enig-art | F.Cu island gap | 0 | 50 | 0.030408 | 55.682148 | 123.3907 | 55.682148 | 123.360292 | 0.1
17-kumiko-void-standard-L01-black-enig-art | F.Cu island gap | 63 | 65 | 0.030408 | 83.682148 | 123.3907 | 83.682148 | 123.360292 | 0.1
17-kumiko-void-standard-L01-black-enig-art | F.Cu island gap | 0 | 76 | 0.030417239 | 95.70759495392045 | 35.618808876066325 | 95.681253 | 35.6036 | 0.1
17-kumiko-void-standard-L01-black-enig-art | F.Cu island gap | 0 | 47 | 0.030419084 | 53.70759664893175 | 108.3649096295053 | 53.681253 | 108.3497 | 0.1
17-kumiko-void-standard-L01-black-enig-art | F.Cu island gap | 0 | 33 | 0.030419084 | 25.707596648931748 | 108.36490962950529 | 25.681253 | 108.3497 | 0.1
17-kumiko-void-standard-L01-black-enig-art | F.Cu island gap | 0 | 75 | 0.030419084 | 95.70759664893176 | 84.1162096295053 | 95.681253 | 84.101 | 0.1
17-kumiko-void-standard-L01-black-enig-art | F.Cu island gap | 0 | 61 | 0.030419084 | 81.70759664893176 | 108.3649096295053 | 81.681253 | 108.3497 | 0.1
17-kumiko-void-standard-L01-black-enig-art | F.Cu island gap | 0 | 28 | 0.030473212 | 17.389690696065344 | 25.777103398197237 | 17.3633 | 25.761867 | 0.1
17-kumiko-void-standard-L01-black-enig-art | F.Cu island gap | 0 | 42 | 0.030473212 | 45.389690696065344 | 25.777103398197234 | 45.3633 | 25.761867 | 0.1
17-kumiko-void-standard-L01-black-enig-art | F.Cu island gap | 0 | 56 | 0.030473212 | 73.38969069606534 | 25.777103398197237 | 73.3633 | 25.761867 | 0.1
17-kumiko-void-standard-L01-black-enig-art | F.Cu island gap | 0 | 3 | 0.030494605 | 3.3897092223400045 | 68.47162890540608 | 3.3633 | 68.486876 | 0.1
17-kumiko-void-standard-L01-black-enig-art | F.Cu island gap | 0 | 5 | 0.030496055 | 3.3897104053569076 | 116.96902805372355 | 3.3633 | 116.984276 | 0.1
17-kumiko-void-standard-L01-black-enig-art | F.Cu island gap | 0 | 38 | 0.030504799 | 31.389718052468496 | 116.9690438113721 | 31.3633 | 116.984296 | 0.1
17-kumiko-void-standard-L01-black-enig-art | F.Cu island gap | 0 | 52 | 0.030504799 | 59.3897180524685 | 116.9690438113721 | 59.3633 | 116.984296 | 0.1
17-kumiko-void-standard-L01-black-enig-art | F.Cu island gap | 0 | 67 | 0.030506806 | 87.38971966849664 | 116.96904259554499 | 87.3633 | 116.984296 | 0.1
17-kumiko-void-standard-L01-black-enig-art | F.Cu island gap | 0 | 51 | 0.030523325 | 59.38973409670133 | 19.97417154854656 | 59.3633 | 19.989433 | 0.1
17-kumiko-void-standard-L01-black-enig-art | F.Cu island gap | 0 | 37 | 0.030523325 | 31.389734096701325 | 19.97417154854656 | 31.3633 | 19.989433 | 0.1
17-kumiko-void-standard-L01-black-enig-art | F.Cu island gap | 0 | 66 | 0.030523327 | 87.38973409670133 | 19.974171544560658 | 87.3633 | 19.989433 | 0.1
17-kumiko-void-standard-L01-black-enig-art | F.Cu island gap | 1 | 6 | 0.030537027 | 3.3633 | 19.989476 | 3.3897465917999505 | 19.974208786538448 | 0.1
17-kumiko-void-standard-L01-black-enig-art | F.Cu island gap | 0 | 2 | 0.030544718 | 3.38975262297594 | 50.025796148538554 | 3.3633 | 50.010524 | 0.1
17-kumiko-void-standard-L01-black-enig-art | F.Cu island gap | 0 | 57 | 0.030559146 | 73.38976511816193 | 122.7718743628481 | 73.3633 | 122.756595 | 0.1
17-kumiko-void-standard-L01-black-enig-art | F.Cu island gap | 0 | 43 | 0.030559146 | 45.38976511816193 | 122.7718743628481 | 45.3633 | 122.756595 | 0.1
17-kumiko-void-standard-L01-black-enig-art | F.Cu island gap | 0 | 29 | 0.030559146 | 17.38976511816193 | 122.7718743628481 | 17.3633 | 122.756595 | 0.1
17-kumiko-void-standard-L01-black-enig-art | F.Cu island gap | 0 | 4 | 0.030561876 | 3.389767484193096 | 98.52317172534768 | 3.3633 | 98.507891 | 0.1
17-kumiko-void-standard-L01-black-enig-art | F.Cu island gap | 0 | 63 | 0.05 | 85.25 | 125.409204 | 85.2 | 125.409204 | 0.1
17-kumiko-void-standard-L01-black-enig-art | F.Cu island gap | 0 | 74 | 0.057333664 | 92.137352 | 27.094979 | 92.177936 | 27.054481 | 0.1
17-kumiko-void-standard-L01-black-enig-art | F.Cu island gap | 0 | 80 | 0.085020278 | 96.6967 | 100.927689 | 96.77032918444638 | 100.88517793291523 | 0.1
17-kumiko-void-standard-L01-black-enig-art | F.Mask black gap | 0 | 210 | 0.00219545 | 30.8602 | 1.8511 | 30.8621 | 1.85 | 0.13
17-kumiko-void-standard-L01-black-enig-art | F.Mask black gap | 0 | 3 | 0.00219545 | 2.8602 | 1.8511 | 2.8621 | 1.85 | 0.13
17-kumiko-void-standard-L01-black-enig-art | F.Mask black gap | 0 | 354 | 0.00219545 | 58.8602 | 1.8511 | 58.8621 | 1.85 | 0.13
17-kumiko-void-standard-L01-black-enig-art | F.Mask black gap | 0 | 7 | 0.00219545 | 2.8602 | 50.3485 | 2.8621 | 50.3474 | 0.13
17-kumiko-void-standard-L01-black-enig-art | F.Mask black gap | 0 | 46 | 0.00219545 | 7.1827 | 58.7756 | 7.1816 | 58.7775 | 0.13
17-kumiko-void-standard-L01-black-enig-art | F.Mask black gap | 0 | 14 | 0.00219545 | 7.1816 | 74.9433 | 7.1827 | 74.9414 | 0.13
17-kumiko-void-standard-L01-black-enig-art | F.Mask black gap | 0 | 47 | 0.00219545 | 7.1827 | 91.1072 | 7.1816 | 91.1091 | 0.13
17-kumiko-void-standard-L01-black-enig-art | F.Mask black gap | 75 | 144 | 0.00219545 | 16.8602 | 26.0998 | 16.8621 | 26.0987 | 0.13
17-kumiko-void-standard-L01-black-enig-art | F.Mask black gap | 121 | 158 | 0.00219545 | 21.1827 | 115.3559 | 21.1816 | 115.3578 | 0.13
17-kumiko-void-standard-L01-black-enig-art | F.Mask black gap | 177 | 225 | 0.00219545 | 35.1827 | 107.273 | 35.1816 | 107.2749 | 0.13
17-kumiko-void-standard-L01-black-enig-art | F.Mask black gap | 204 | 215 | 0.00219545 | 35.1816 | 123.4407 | 35.1827 | 123.4388 | 0.13
17-kumiko-void-standard-L01-black-enig-art | F.Mask black gap | 243 | 288 | 0.00219545 | 44.8602 | 26.0998 | 44.8621 | 26.0987 | 0.13
17-kumiko-void-standard-L01-black-enig-art | F.Mask black gap | 254 | 303 | 0.00219545 | 49.1827 | 115.3559 | 49.1816 | 115.3578 | 0.13
17-kumiko-void-standard-L01-black-enig-art | F.Mask black gap | 321 | 369 | 0.00219545 | 63.1827 | 107.273 | 63.1816 | 107.2749 | 0.13
17-kumiko-void-standard-L01-black-enig-art | F.Mask black gap | 348 | 359 | 0.00219545 | 63.1816 | 123.4407 | 63.1827 | 123.4388 | 0.13
17-kumiko-void-standard-L01-black-enig-art | F.Mask black gap | 387 | 432 | 0.00219545 | 72.8602 | 26.0998 | 72.8621 | 26.0987 | 0.13
17-kumiko-void-standard-L01-black-enig-art | F.Mask black gap | 398 | 447 | 0.00219545 | 77.1827 | 115.3559 | 77.1816 | 115.3578 | 0.13
17-kumiko-void-standard-L01-black-enig-art | F.Mask black gap | 463 | 520 | 0.00219545 | 91.1827 | 58.7756 | 91.1816 | 58.7775 | 0.13
17-kumiko-void-standard-L01-black-enig-art | F.Mask black gap | 465 | 522 | 0.00219545 | 91.1827 | 107.273 | 91.1816 | 107.2749 | 0.13
17-kumiko-void-standard-L01-black-enig-art | F.Mask black gap | 483 | 521 | 0.00219545 | 91.1827 | 91.1072 | 91.1816 | 91.1091 | 0.13
17-kumiko-void-standard-L01-black-enig-art | F.Mask black gap | 515 | 534 | 0.00219545 | 91.1816 | 74.9433 | 91.1827 | 74.9414 | 0.13
17-kumiko-void-standard-L01-black-enig-art | F.Mask black gap | 0 | 11 | 0.002247221 | 2.8602 | 98.846 | 2.8621 | 98.8448 | 0.13
17-kumiko-void-standard-L01-black-enig-art | F.Mask black gap | 0 | 434 | 0.002247221 | 72.8602 | 123.0947 | 72.8621 | 123.0935 | 0.13
17-kumiko-void-standard-L01-black-enig-art | F.Mask black gap | 0 | 290 | 0.002247221 | 44.8602 | 123.0947 | 44.8621 | 123.0935 | 0.13
17-kumiko-void-standard-L01-black-enig-art | F.Mask black gap | 0 | 146 | 0.002247221 | 16.8602 | 123.0947 | 16.8621 | 123.0935 | 0.13
17-kumiko-void-standard-L01-black-enig-art | F.Mask black gap | 0 | 233 | 0.002282542 | 35.5268 | 9.934 | 35.5288 | 9.9329 | 0.13
17-kumiko-void-standard-L01-black-enig-art | F.Mask black gap | 0 | 224 | 0.002282542 | 35.1827 | 10.2781 | 35.1816 | 10.2801 | 0.13
17-kumiko-void-standard-L01-black-enig-art | F.Mask black gap | 0 | 54 | 0.002282542 | 7.5268 | 9.934 | 7.5288 | 9.9329 | 0.13
17-kumiko-void-standard-L01-black-enig-art | F.Mask black gap | 0 | 44 | 0.002282542 | 7.1827 | 10.2781 | 7.1816 | 10.2801 | 0.13
17-kumiko-void-standard-L01-black-enig-art | F.Mask black gap | 0 | 140 | 0.002282542 | 21.1827 | 2.1952 | 21.1816 | 2.1972 | 0.13
17-kumiko-void-standard-L01-black-enig-art | F.Mask black gap | 0 | 57 | 0.002282542 | 7.5268 | 42.2656 | 7.5288 | 42.2645 | 0.13
17-kumiko-void-standard-L01-black-enig-art | F.Mask black gap | 0 | 45 | 0.002282542 | 7.1827 | 42.6097 | 7.1816 | 42.6117 | 0.13
17-kumiko-void-standard-L01-black-enig-art | F.Mask black gap | 0 | 426 | 0.002282542 | 77.1827 | 2.1952 | 77.1816 | 2.1972 | 0.13
17-kumiko-void-standard-L01-black-enig-art | F.Mask black gap | 0 | 282 | 0.002282542 | 49.1827 | 2.1952 | 49.1816 | 2.1972 | 0.13
17-kumiko-void-standard-L01-black-enig-art | F.Mask black gap | 0 | 377 | 0.002282542 | 63.5268 | 9.934 | 63.5288 | 9.9329 | 0.13
17-kumiko-void-standard-L01-black-enig-art | F.Mask black gap | 0 | 368 | 0.002282542 | 63.1827 | 10.2781 | 63.1816 | 10.2801 | 0.13
17-kumiko-void-standard-L01-black-enig-art | F.Mask black gap | 0 | 58 | 0.002282542 | 7.5268 | 58.4314 | 7.5288 | 58.4303 | 0.13
17-kumiko-void-standard-L01-black-enig-art | F.Mask black gap | 0 | 594 | 0.002282542 | 96.1935 | 66.5143 | 96.1955 | 66.5132 | 0.13
17-kumiko-void-standard-L01-black-enig-art | F.Mask black gap | 14 | 29 | 0.002282542 | 7.5268 | 74.5972 | 7.5288 | 74.5961 | 0.13
17-kumiko-void-standard-L01-black-enig-art | F.Mask black gap | 75 | 129 | 0.002282542 | 12.1935 | 18.0169 | 12.1955 | 18.0158 | 0.13
17-kumiko-void-standard-L01-black-enig-art | F.Mask black gap | 89 | 166 | 0.002282542 | 21.5268 | 18.0169 | 21.5288 | 18.0158 | 0.13
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

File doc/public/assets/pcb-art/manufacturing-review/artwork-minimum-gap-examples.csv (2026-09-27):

boardId | feature | polygonA0 | polygonB0 | gapMm | pointAxMm | pointAyMm | pointBxMm | pointByMm | screenThresholdMm
17-kumiko-void-standard-L01-black-enig-art | F.Cu island gap | 0 | 40 | 0.03033513 | 40.72297094031123 | 17.694241656968146 | 40.6967 | 17.679074 | 0.1
17-kumiko-void-standard-L01-black-enig-art | F.Mask black gap | 0 | 210 | 0.00219545 | 30.8602 | 1.8511 | 30.8621 | 1.85 | 0.13
17-kumiko-void-standard-L04-black-enig-art | F.Mask black gap | 18 | 23 | 0.003361547 | 35.3807 | 56.3428 | 35.379 | 56.3457 | 0.13
17-kumiko-void-standard-L07-black-enig-art | F.Mask black gap | 18 | 23 | 0.003361547 | 33.9807 | 60.3428 | 33.979 | 60.3457 | 0.13
01-spider-nest-L01-black-enig-art | F.Cu island gap | 0 | 15 | 0.00990744 | 61.25757686356518 | 91.05473278873067 | 61.264288 | 91.062021 | 0.1
01-spider-nest-L01-black-enig-art | F.Mask black gap | 0 | 15 | 0.109907874 | 61.22887322868255 | 91.01319445469693 | 61.303323 | 91.094046 | 0.13
03-coral-vault-L01-black-enig-art | F.Cu island gap | 97 | 106 | 0.000828743 | 58.464784792198124 | 98.81019046202708 | 58.46544 | 98.809683 | 0.1
03-coral-vault-L01-black-enig-art | F.Mask black gap | 21 | 35 | 0.013383651 | 12.594044 | 36.992439 | 12.584478625144275 | 36.983078138351324 | 0.13
17-kumiko-void-wide-L01-black-enig-art | F.Cu island gap | 0 | 43 | 0.009865821 | 99.1 | 105.854933 | 99.091456 | 105.85 | 0.1
17-kumiko-void-wide-L01-black-enig-art | F.Mask black gap | 0 | 3 | 0.00219545 | 2.8602 | 1.8511 | 2.8621 | 1.85 | 0.13
17-kumiko-void-wide-L04-black-enig-art | F.Mask black gap | 3 | 11 | 0.003361547 | 7.8941 | 55.8294 | 7.897 | 55.8277 | 0.13
17-kumiko-void-wide-L07-black-enig-art | F.Cu island gap | 7 | 8 | 0.016468879 | 6.172946506275559 | 108.9618116073412 | 6.184423 | 108.95 | 0.1
17-kumiko-void-wide-L07-black-enig-art | F.Mask black gap | 3 | 10 | 0.003361547 | 6.4941 | 59.8294 | 6.497 | 59.8277 | 0.13

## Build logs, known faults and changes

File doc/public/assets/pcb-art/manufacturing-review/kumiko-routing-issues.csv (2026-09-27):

issueId | variantId | layer | geometryHoleIndex0 | areaMm2 | micDiameterLowerBoundMm | micDiameterUpperBoundMm | centerXmm | centerYmm | minXmm | minYmm | maxXmm | maxYmm
kumiko-void-standard-L01-H01 | standard | 1 | 9 | 1.23298318 | 0.78313 | 0.78313 | 22.0 | 101.108435 | 20.5386 | 100.6563 | 23.4614 | 101.5
kumiko-void-standard-L01-H02 | standard | 1 | 44 | 1.23298318 | 0.78313 | 0.78313 | 78.0 | 101.108435 | 76.5386 | 100.6563 | 79.4614 | 101.5
kumiko-void-standard-L01-H03 | standard | 1 | 58 | 1.23298318 | 0.78313 | 0.78313 | 50.0 | 101.108435 | 48.5386 | 100.6563 | 51.4614 | 101.5
kumiko-void-standard-L03-H01 | standard | 3 | 13 | 0.9102225 | 0.075 | 0.075 | 90.7625 | 48.84185 | 90.725 | 42.7737 | 90.8 | 54.9966
kumiko-void-standard-L03-H02 | standard | 3 | 14 | 0.9102225 | 0.075 | 0.075 | 90.7625 | 68.05565 | 90.725 | 61.9009 | 90.8 | 74.1238
kumiko-void-standard-L04-H01 | standard | 4 | 0 | 1.59128923 | 0.99230895 | 0.99230895 | 24.02115448 | 27.49615448 | 23.525 | 27.0 | 24.8805 | 29.3479
kumiko-void-standard-L04-H02 | standard | 4 | 1 | 1.59128922 | 0.99230895 | 0.99230895 | 21.17884552 | 27.49615448 | 20.3195 | 27.0 | 21.675 | 29.3479
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

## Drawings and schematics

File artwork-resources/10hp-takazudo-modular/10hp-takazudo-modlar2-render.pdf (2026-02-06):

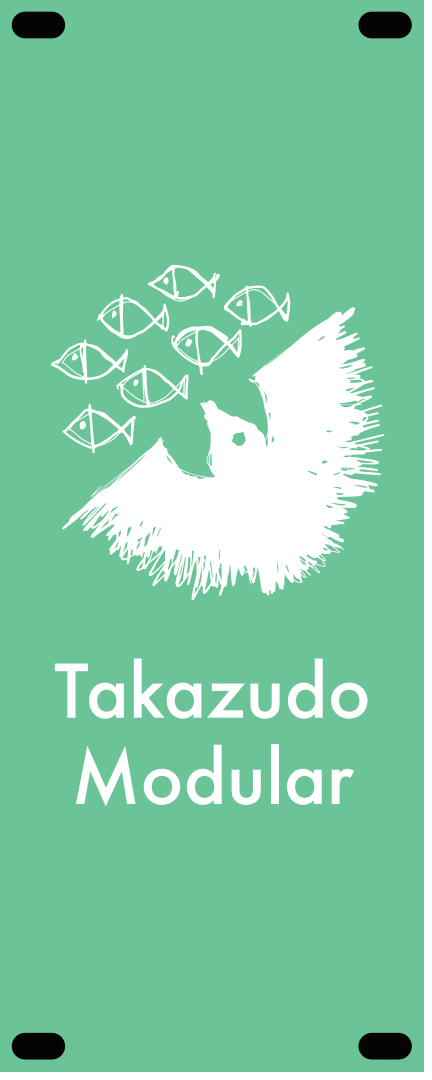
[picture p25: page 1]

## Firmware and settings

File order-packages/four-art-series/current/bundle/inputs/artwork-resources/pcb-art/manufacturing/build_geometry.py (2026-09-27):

#!/usr/bin/env python3
"""Build a separate, indexed routing candidate from the frozen Rev5 source.

The artifact remains a candidate until all manufacturing gates pass. The
approved preview inputs are never modified by this program.
"""
from __future__ import annotations

import copy
import hashlib
import importlib.util
import json
import math
from pathlib import Path

import shapely
from shapely.geometry import LineString, Point, Polygon, box
from shapely.ops import nearest_points, substring, unary_union

HERE = Path(__file__).resolve().parent
ROOT = HERE.parent
SOURCE = ROOT / 'preview-source/assets/geometry.json'
OUTPUT = HERE / 'manufacturing-geometry.json'
LEDGER = HERE / 'indexed-deltas.json'

module = importlib.util.spec_from_file_location('export_reference', ROOT / 'tools/export_kicad.py')
export = importlib.util.module_from_spec(module)
module.loader.exec_module(export)


def digest(data: bytes) -> str:
    return hashlib.sha256(data).hexdigest()


def ring_hash(points) -> str:
    return digest(json.dumps(points, separators=(',', ':')).encode())


def manufacturing_ring(ring,digits=9):
    points = [[round(x, digits), round(y, digits)] for x, y in ring.coords]
    return points[:-1] if points[-1] == points[0] else points


def relocate_spider_network_guides(layer,original_layer,decision,network,source_hash):
    """Insert only the evidence-indexed straight guide portions and short joins."""
    by_stroke={}
    for portion in decision['guidePortions']:
        by_stroke.setdefault(portion['guideStrokeIndex0'],[]).append(portion)
    changes=[]
    miter_changes=[]
    curve_changes=[]
    for stroke_index,portions in sorted(by_stroke.items()):
        stroke=layer['art']['strokes'][stroke_index]
        source=original_layer['art']['strokes'][stroke_index]
        before=copy.deepcopy(stroke['pts'])
        original=source['pts']
        if stroke['w']!=.251:
            raise ValueError(f'Spider guide {stroke_index} width changed')
        source_line=LineString(original)
        generic_line=LineString(before)
        source_edge_starts=[0.0]
        for a,b in zip(original,original[1:]):
            source_edge_starts.append(source_edge_starts[-1]+math.dist(a,b))
        edge_distances={}
        def generic_edge_distance(vertex_index):
            guess=(source_edge_starts[vertex_index]/source_line.length*
                   generic_line.length)
            low=max(0.0,guess-2.0)
            high=min(generic_line.length,guess+2.0)
            local=substring(generic_line,low,high)
            distance=low+local.project(Point(original[vertex_index]))
            if generic_line.interpolate(distance).distance(
                    Point(original[vertex_index]))>.15:
                raise ValueError(f'Spider guide {stroke_index} edge-local mapping drift')
            return distance
        intervals=[]
        for p in portions:
            if p['originalGuideContourSha256']!=ring_hash(original):
                raise ValueError(f'Spider guide {stroke_index} source hash changed')
            j=p['originalGuideEdgeIndex0']
            a,b=original[j:j+2]
            if p['originalEdgeMm']!=[a,b]:
                raise ValueError(f'Spider guide {stroke_index} edge {j} changed')
            dx,dy=b[0]-a[0],b[1]-a[1]
            length2=dx*dx+dy*dy
            original_ends=p['originalPortionMm']
            nominal_ends=p['nominalRelocatedPortionMm']
            t=[((pt[0]-a[0])*dx+(pt[1]-a[1])*dy)/length2
               for pt in original_ends]
            if t[0]>t[1]:
                t.reverse()
                original_ends=list(reversed(original_ends))
                nominal_ends=list(reversed(nominal_ends))
            if t[0]<-.000001 or t[1]>1.000001:
                raise ValueError('Spider guide portion leaves its original edge')
            for old,new in zip(original_ends,nominal_ends):
                if math.dist(old,new)>.5:
                    raise ValueError('Spider guide nominal displacement exceeded .5 mm')
            if j not in edge_distances:
                edge_distances[j]=(generic_edge_distance(j),generic_edge_distance(j+1))
            edge_start,edge_end=edge_distances[j]
            d0=edge_start+max(0,t[0])*(edge_end-edge_start)
            d1=edge_start+min(1,t[1])*(edge_end-edge_start)
            for at,original_point in ((d0,original_ends[0]),(d1,original_ends[1])):
                if generic_line.interpolate(at).distance(Point(original_point))>.15:
                    raise ValueError('Spider guide portion leaves source-edge-local mapping')
            intervals.append((d0,d1,nominal_ends,p,j))
        revised=[before[0]]
        previous=0.0
        for d0,d1,(start,end),p,j in sorted(intervals,key=lambda row:row[0]):
            if d0<previous-.000001:
                raise ValueError(f'Spider guide {stroke_index} portions overlap')
            if d0>previous+.000001:
                retained=substring(generic_line,previous,d0)
                revised.extend([list(coord) for coord in retained.coords])
            revised.extend([[round(v,9) for v in start],
                            [round(v,9) for v in end]])
            previous=d1
            changes.append({
                    'board':'spider-nest-L01',
                    'artStrokeIndex0':stroke_index,
                    'originalGuideEdgeIndex0':j,
                    'centralStrokeIndex0':p['centralStrokeIndex0'],
                    'sourceGeometrySha256':source_hash,
                    'sourceContourSha256':ring_hash(original),
                    'originalPortionMm':p['originalPortionMm'],
                    'nominalRelocatedPortionMm':p['nominalRelocatedPortionMm'],
                    'maximumNominalDisplacementMm':p['maximumNominalDisplacementMm'],
                    'operation':'relocate exact Spider network guide portion with bounded endpoint join',
            })
        if previous<generic_line.length-.000001:
            retained=substring(generic_line,previous,generic_line.length)
            revised.extend([list(coord) for coord in retained.coords])
        compact=[]
        for point in revised:
            if not compact or math.dist(point,compact[-1])>1e-7:
                compact.append(point)
        if math.dist(compact[0],compact[-1])<1e-7:
            compact[-1]=compact[0]
        for miter in (m for m in decision['sourceEdgeLocalMiters']
                      if m['guideStrokeIndex0']==stroke_index):
            shared=Point(miter['originalSharedPointMm'])
            target=[]
            for edge in miter['originalGuideEdgeIndices0']:
                candidates=[p for p in portions if p['originalGuideEdgeIndex0']==edge]
                if not candidates:
                    raise ValueError('Spider miter has no indexed source edge')
                p=min(candidates,key=lambda p:min(Point(v).distance(shared)
                    for v in p['originalPortionMm']))
                k=min(range(2),key=lambda k:Point(p['originalPortionMm'][k]).distance(shared))
                nominal=p['nominalRelocatedPortionMm'][k]
                matched=min(range(len(compact)),key=lambda i:math.dist(compact[i],nominal))
                if math.dist(compact[matched],nominal)>.00001:
                    raise ValueError('Spider miter nominal endpoint not emitted')
                target.append(matched)
            point=[round(v,9) for v in miter['intersectionMm']]
            low,high=sorted(target)
            if low==high:
                compact[low]=point
            elif (miter['originalGuideEdgeIndices0'][1]==0 and
                  miter['originalGuideEdgeIndices0'][0]>0):
                compact=[point]+compact[low+1:high]+[point]
            else:
                compact=compact[:low]+[point]+compact[high+1:]
            miter_changes.append({
                'board':'spider-nest-L01',
                'artStrokeIndex0':stroke_index,
                'originalGuideEdgeIndices0':miter['originalGuideEdgeIndices0'],
                'centralStrokeIndices0':miter['centralStrokeIndices0'],
                'originalSharedPointMm':miter['originalSharedPointMm'],
                'intersectionMm':miter['intersectionMm'],
                'displacementMm':miter['displacementMm'],
                'sourceGeometrySha256':source_hash,
                'operation':'exact source-edge-local Spider guide miter',
            })
        if stroke_index==103:
            terminal=decision['terminal']
            controls=terminal['cubicControlPointsMm']
            start=min(range(len(compact)),key=lambda i:math.dist(compact[i],controls[0]))
            end=min(range(len(compact)),key=lambda i:math.dist(compact[i],controls[3]))
            if (start>=end or math.dist(compact[start],controls[0])>.000001 or
                    math.dist(compact[end],controls[3])>.000001 or
                    terminal['guide103OriginalEdgeIndex0']!=27 or
                    terminal['cubicSegments']!=64):
                raise ValueError('Spider guide103 cubic source jog changed')
            cubic=[]
            for step in range(terminal['cubicSegments']+1):
                t=step/terminal['cubicSegments']
                point=[(1-t)**3*controls[0][k]+3*(1-t)**2*t*controls[1][k]+
                       3*(1-t)*t*t*controls[2][k]+t**3*controls[3][k]
                       for k in (0,1)]
                cubic.append([round(v,9) for v in point])
            cubic[0]=controls[0]
            cubic[-1]=controls[3]
            if any(Point(p).distance(Point(terminal['guide103OriginalEndpointMm']))>.5
                   for p in cubic):
                raise ValueError('Spider guide103 cubic exceeded endpoint reach')
            compact=compact[:start]+cubic+compact[end+1:]
            curve_changes.append({
                'board':'spider-nest-L01',
                'artStrokeIndex0':103,
                'originalGuideEdgeIndex0':27,
                'controlPointsMm':controls,
                'segmentCount':64,
                'sourceGeometrySha256':source_hash,
                'operation':'replace indexed reverse jog with bounded Spider cubic',
            })
        line=LineString(compact)
        if LineString(original).hausdorff_distance(line)>.5:
            raise ValueError(f'Spider guide {stroke_index} exceeds .5 mm source reach')
        if line.difference(network.buffer(.5)).difference(
                LineString(before).buffer(.5)).length>.00001:
            raise ValueError(f'Spider guide {stroke_index} leaves network/end envelope')
        stroke['pts']=compact
        for change in changes:
            if change['artStrokeIndex0']==stroke_index:
                change['afterContourSha256']=ring_hash(compact)
    if len(changes)!=len(decision['guidePortions']):
        raise ValueError(f'Spider network guide portion count changed: {len(changes)}')
    if len(miter_changes)!=len(decision['sourceEdgeLocalMiters']):
        raise ValueError('Spider network miter count changed')
    if len(curve_changes)!=1:
        raise ValueError('Spider network guide103 cubic was not indexed once')
    return changes,miter_changes,curve_changes
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

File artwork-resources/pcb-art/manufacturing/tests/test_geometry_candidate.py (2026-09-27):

"""Independent checks for the separate routing candidate and its indexed deltas."""
import hashlib
import importlib.util
import itertools
import json
import copy
import math
from pathlib import Path
import unittest

import shapely
from shapely.geometry import LineString, Point, Polygon, box
from shapely.ops import unary_union

HERE = Path(__file__).resolve().parents[1]
ROOT = HERE.parent
module = importlib.util.spec_from_file_location('export_reference', ROOT/'tools/export_kicad.py')
export = importlib.util.module_from_spec(module)
module.loader.exec_module(export)
mask_module = importlib.util.spec_from_file_location('repair_mask_candidate',
                                                     HERE/'repair_mask_candidate.py')
mask_repair = importlib.util.module_from_spec(mask_module)
mask_module.loader.exec_module(mask_repair)


def digest(path):
    return hashlib.sha256(path.read_bytes()).hexdigest()


def selected(data):
    for family in data['designs']:
        yield (next(d for d in family['variants'] if d.get('variantId') == 'wide')
               if family['id'] == 'kumiko-void' else family)


class ManufacturingGeometryCandidateTests(unittest.TestCase):
    @classmethod
    def setUpClass(cls):
        cls.policy = json.loads((HERE/'policy.json').read_text())
        cls.original = json.loads((ROOT/'preview-source/assets/geometry.json').read_text())
        cls.candidate = json.loads((HERE/'manufacturing-geometry.json').read_text())
        cls.ledger = json.loads((HERE/'indexed-deltas.json').read_text())

    def test_source_and_candidate_hashes(self):
        self.assertEqual(digest(ROOT/'preview-source/assets/geometry.json'),
                         self.policy['sourceHashes']['preview-source/assets/geometry.json'])
        self.assertEqual(digest(HERE/'manufacturing-geometry.json'),
                         self.ledger['manufacturingGeometrySha256'])
        self.assertEqual(self.ledger['policySha256'], digest(HERE/'policy.json'))

    def test_art_findings_are_explicitly_unresolved(self):
        report=json.loads((HERE/'art-candidate-audit.json').read_text())
        source=json.loads((ROOT/'validation/export-art-review.json').read_text())
        expected=sum(len(b['copperGapsBelow010Mm'])+len(b['blackMaskGapsBelow013Mm'])
                     for b in source['boards'] if b['category']=='selected')
        self.assertEqual(len(report['findings']),expected)
        self.assertEqual(len(report['findings']),715)
        self.assertEqual(report['geometrySha256'],digest(HERE/'manufacturing-geometry.json'))
        self.assertEqual(len({f['key'] for f in report['findings']}),715)
        self.assertTrue(all(f['disposition'].startswith('unresolved') for f in report['findings']))
        self.assertEqual(len(report['finishedUnionPairs']),980)
        self.assertEqual(len({f['key'] for f in report['finishedUnionPairs']}),980)
        self.assertTrue(all(f['gapMm']<.25 for f in report['finishedUnionPairs']))
        self.assertEqual(len(report['necessaryWidthFailures']),289)
        copper_pairs=[f for f in report['finishedUnionPairs'] if f['feature']=='F.Cu island gap']
        self.assertEqual(len(copper_pairs),176)
        self.assertEqual(sum(not f['straight025MmJoinFitsCopperSafeRegion'] for f in copper_pairs),8)
        self.assertEqual(len(self.ledger['strokeWidthChanges']),680)
        source_strokes=sum(1 for design in selected(self.original) for layer in design['layers']
                           for stroke in layer['art']['strokes'] if stroke.get('color') is None
                           and stroke.get('purpose')!='top-gold-border'
                           and 0<stroke.get('w',0)<.25)
        self.assertEqual(source_strokes,680)

    def test_inherited_findings_have_final_union_cross_references(self):
        report=json.loads((HERE/'art-resolution-ledger.json').read_text())
        self.assertEqual(report['selectedFindingCount'],715)
        self.assertEqual(len({f['key'] for f in report['findings']}),715)
        self.assertEqual(report['maskCandidateSha256'],digest(HERE/'mask-repair-candidate.json'))
        self.assertEqual(report['copperLedgerSha256'],digest(HERE/'copper-repair-ledger.json'))
        self.assertTrue(all(f['finishedUnionDistinctGapScreen'].startswith('diagnostic:')
                            for f in report['findings']))
        self.assertTrue(all(f['withinComponentWidthProof']=='pending'
                            for f in report['findings']))
        self.assertEqual(report['alternativeIssueIds'],
                         self.policy['alternativeUnresolvedIssueIds'])

    def test_actual_union_comparison_images_track_sources(self):
        report=json.loads((HERE/'candidate-comparisons.json').read_text())
        self.assertEqual(report['approvedGeometrySha256'],
                         digest(ROOT/'preview-source/assets/geometry.json'))
        self.assertEqual(report['manufacturingGeometrySha256'],
                         digest(HERE/'manufacturing-geometry.json'))
        self.assertEqual(report['maskCandidateSha256'],
                         digest(HERE/'mask-repair-candidate.json'))
        self.assertEqual(len(report['designs']),5)
        self.assertEqual(sum(d['selectedEnigLayers'] for d in report['designs']),11)
        for design in report['designs']:
            self.assertEqual(design['imageSha256'],digest(HERE/design['image']))
        self.assertEqual(sum(d['selectedLayers']
                             for d in report['allSelectedLayerComparisons']),43)
        for design in report['allSelectedLayerComparisons']+report['details']:
            self.assertEqual(design['imageSha256'],digest(HERE/design['image']))

    def test_inventory_closures_and_explicit_indices(self):
        self.assertEqual(sum(len(d['layers']) for d in selected(self.candidate)), 43)
        standard = next(d for d in self.candidate['designs'] if d['id']=='kumiko-void')
        original = next(d for d in self.original['designs'] if d['id']=='kumiko-void')
        self.assertEqual(standard['layers'], original['layers'])
        self.assertEqual(len(standard['layers']), 9)
        self.assertEqual(len(self.ledger['closedIssueIds']), 56)
        self.assertEqual(set(self.ledger['closedIssueIds']),
                         {a['issueId'] for a in self.policy['selectedApertureActions']})
        pairs = [(d['board'], d['geometryHoleIndex0']) for d in self.ledger['changes']]
        self.assertEqual(len(pairs), len(set(pairs)))
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

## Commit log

2026-02-06 Initial project setup: zudo-blanks (modular blank panels)
    Set up KiCad + Docusaurus project for designing blank panels for modular
    synthesizers. Includes documentation site, GitHub Actions CI/CD, and
    KiCad project structure.
    [blank-panels.kicad_pcb, blank-panels.kicad_sch]
2026-02-06 Add panel KiCad files migrated from Dropbox
    Copied 55 panel projects from /Dropbox/modularCAD/blank-panels/ into
    flat panels/ directory structure:
    - 8x alumi-blanks-v1-1U (1hp-10hp)
    - 12x alumi-blanks-v1-3U (1hp-20hp)
    - 5x art panels (sun, ufo, ufo-v2, takazudo-modular, takazudo-modular-gold)
    - 30x saucer series (6 designs x 5 HP sizes each)
    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
    [10hp-z-gold.kicad_pcb, 10hp.kicad_pcb, 12hp-sun.kicad_pcb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]
2026-02-06 Add artwork-resources, jlcpcb-order-snapshots dirs and update .gitignore
    - artwork-resources/: for AI/SVG artwork source files
    - jlcpcb-order-snapshots/: for JLCPCB order history
    - .gitignore: add ~*.lck pattern for KiCad lock files
2026-02-06 Add file structure documentation page
    New overview doc describing repository directory conventions:
    panels/ naming patterns, artwork-resources/, jlcpcb-order-snapshots/,
    footprints/, and doc/ structure.
    Also adds doc/CLAUDE.md with Docusaurus-specific guidance.
2026-02-06 Refactor CLAUDE.md into directory-scoped files
    Split directory-specific content out of root CLAUDE.md:
    - doc/CLAUDE.md: Docusaurus sidebar, adding pages, dev commands
    - footprints/CLAUDE.md: footprint file organization, SVG export workflow
    Root CLAUDE.md now focuses on global project info and points to
    subdirectory CLAUDE.md files for directory-specific guidance.
2026-02-06 Remove root KiCad project files and update references
    Root blank-panels.kicad_* files are no longer needed since all panel
    designs live under panels/ as individual KiCad projects.
    Updated README.md, file-structure doc, and kicad-workflow doc to
    reflect the panels/ directory structure.
    [blank-panels.kicad_pcb, blank-panels.kicad_sch]
2026-04-15 feat: add new zb-side-frame panel directories and update .gitignore for panel artifacts
    - Add zb-side-frame-1u, zb-side-frame-3u, zb-side-frame-7u panel directories
    - Update .gitignore to exclude panel .history/ and .zip files
    - Update alumi-3u-to-1u-v1.kicad_pro project config
    [zb-side-frame-1u.kicad_pcb, zb-side-frame-1u.kicad_sch, zd-side-frame-3u.kicad_pcb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]
2026-04-15 feat: add new screw hole footprints and update panel KiCad files for new JLCPCB order
    - Added modular-3M-screw-hole-size1-alumi-0604, modular-3M-screw-hole-size1-fit-alumi-0604, modular-3M-screw-hole-size2-alumi-0604
    - Updated all panel .kicad_pcb and .kicad_pro files for 3U panels (1hp-16hp)
    - Added new JLCPCB order snapshot and Gerber outputs
    [10hp.kicad_pcb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]
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2026-09-22 feat: add KiCad 8 emitter module and fixture board for strip mine PCBs
    Dependency-free kicad-emit.mjs builds gr_line/gr_circle/gr_rect/Edge.Cuts
    polygons, UFO-identical slot footprints, M3 screw footprints, full board
    and project files with deterministic uuid5 ids. The fixture board is
    verified via kicad-cli gerber/drill/svg export and DRC in emit.test.mjs.
    Refs #5
    [fixture.kicad_pcb]
2026-09-22 refactor(strip-mine): share preview geometry via geometry.js with composeBoard
    Move spec constants, pit openings and the artwork recipes out of the preview
    into a classic script usable from both the browser and Node. composeBoard()
    returns the finished, already-cleared artwork per board (strokes, dots,
    building strips, rims), so the canvas only draws primitives and the KiCad
    generator can emit the same list 1:1.
    - M3 stack screws: filled Ø6.0 gold annular pad around the Ø3.2 hole
    - KEEP_OUT rounded to 0.1 mm (17.1), screw centres at y 23.6 / 104.9
    - buildings closer than 2 mm to the top pit are dropped (pattern 5 had one
    touching the rim, which failed the building check)
    - default patte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
2026-09-22 fix(strip-mine): keep top-board copper DRC-clean in composeBoard
    - Edge band follows the UFO Edge.Cuts outline (TOP_OUTLINE) and breaks
    around the four rail slot pads (0.3 mm clearance); the pads reach
    0.87 mm in from the edge and overlapped the 0.9 mm visible band.
    - Strokes carry their source line id; separateStrokes() splits thinner
    strokes within STROKE_GAP (0.4 mm) of a wider stroke from another line,
    removing near-tangent fine/accent pairs that left a copper sliver.
    - Preview renders open rims without closing them; tests cover both rules.
2026-09-22 feat(strip-mine): generate the nine Strip Mine KiCad boards (pattern 5)
    build-pcbs.mjs composes each board from geometry.js composeBoard(i,
    { pattern: 4 }) and writes pcb-NN-<colour>/strip-mine-NN.kicad_{pcb,pro}:
    UFO outline + slots on board 01, KEEP_OUT rectangles on 02-09, pit
    cutouts on 01-08, four M3 stack pads everywhere, gold on F.Cu + F.Mask.
    [strip-mine-01.kicad_pcb, strip-mine-02.kicad_pcb, strip-mine-03.kicad_pcb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]
2026-09-22 fix(strip-mine): keep 0.4 mm copper gaps at building annexes, split stroke ends and slot pads
    The output-level copper check found sub-0.35 mm gaps between separate copper
    islands on board 01:
    - annex squares placed a fixed 4 mm off a building landed 0.19-0.26 mm from
    another building; spaceBuildings() now nudges near misses to STROKE_GAP
    - a stroke split on a single segment left its two round caps one 0.5 mm
    segment apart (~0.2 mm gap); spaceStrokeEnds() trims same-source pieces
    - the edge band stopped only 0.3 mm from the slot pads; SLOT_PAD_CLEAR is
    now STROKE_GAP
    Regenerated strip-mine-01.kicad_pcb.
    [strip-mine-01.kicad_pcb]
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2026-09-22 fix(strip-mine): drop stub stroke chains and near-miss buildings in composeBoard
    - dropStubs(): join same-source pieces that share an endpoint and drop any
    chain shorter than MIN_CHAIN_W (2) x its widest piece, removing the
    clipped stubs without shredding heavy lines made of 0.5 mm pieces
    - separateBuildings() replaces the nudge: buildings touch/overlap or keep
    BUILDING_GAP (0.4) apart, otherwise the smaller one is dropped (pattern 5
    loses the two 0.7 mm annexes and one 2.1 x 2.1 building)
    - BUILDING_GAP and MIN_CHAIN_W exported; tests assert no chain < 2w and
    every non-touching rect pair >= BUILDING_GAP
    Regenerated strip-mine-01.kicad_pcb.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
    [strip-mine-01.kicad_pcb]
2026-09-22 fix(strip-mine): check rail slot width against SLOT_DRILL instead of M3_HOLE
2026-09-23 Connect Strip Mine copper frame across rail slots
    [strip-mine-01.kicad_pcb]
2026-09-23 Add 1U and 3U side frame pad KiCad projects
    [1u-padder.kicad_pcb, 3u-padder.kicad_pcb]
2026-09-23 Panelize Strip Mine lower boards and remove blue board copper
    [strip-mine-09.kicad_pcb, strip-mine-black-panel.kicad_pcb, strip-mine-red-panel.kicad_pcb]
2026-09-24 Import Revision 5 PCB art handoff
    [01-spider-nest-L01-black-enig-art.kicad_pcb, 01-spider-nest-L02-white-mask-only.kicad_pcb, 01-spider-nest-L03-gold-enig-fill.kicad_pcb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]
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2026-09-24 Index finished-union art gaps and necessary width failures
    [test_geometry_candidate.py]
2026-09-24 Index art guide corrections and scoped mask repair candidate
    [build_geometry.py, test_geometry_candidate.py]
2026-09-25 Index bounded native art candidate corrections
    [build_geometry.py, test_geometry_candidate.py]
2026-09-25 Generate selected native art candidates with indexed copper joins
    [01-spider-nest-L01-black-enig-art.kicad_pcb, 01-spider-nest-L02-white-mask-only.kicad_pcb, 01-spider-nest-L03-gold-enig-fill.kicad_pcb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]
2026-09-25 Index Coral art corrections and review all selected geometry
    [03-coral-vault-L01-black-enig-art.kicad_pcb]
2026-09-25 Apply bounded Spider rib and Fault ink-pocket repairs
    [01-spider-nest-L01-black-enig-art.kicad_pcb, 13-fault-line-L01-black-enig-art.kicad_pcb]
2026-09-25 Round indexed Spider enclosed channel ends
    [01-spider-nest-L01-black-enig-art.kicad_pcb]
2026-09-25 Correct Spider fabrication decision with unfiltered network scope
    [test_spider_complete.py, test_spider_erratum.py]
2026-09-25 Decide bounded fabrication process classes
    Owner-approved amendment to the universal 0.25 mm art target: general
    0.10 mm copper for the four full-gold pours and certified convex islands,
    0.13 mm black mask web on non-Spider tops under an unchanged-mask order,
    0.25 mm everywhere else. Evidence binds the measured native candidate and
    records six sections that still fail the relaxed classes.
    [test_spider_erratum.py]
2026-09-25 Checkpoint complete Spider guide miters and terminal cubic
    Preserves the Codex handoff state: indexed source-edge-local miters,
    bounded guide-103 cubic, and regenerated geometry/art/width audits.
    Derived comparisons, tool-access and native boards are stale; finished
    mask/transition checks still fail. Not issue 15 acceptance.
    [build_geometry.py, test_geometry_candidate.py]
2026-09-25 Apply 0.25 mm to special-class copper-gap witnesses
    Copper-free gaps near the witnesses lie between retained-special
    components, so the applicable limit is 0.25 mm, not the general 0.10.
    Add a 0.25 mm negative-copper screen and fix the documented re-measure
    command so it actually discovers the tests.
2026-09-26 WIP: class-aware width gate and local width enforcement
    Adds the opposing-boundary width test (width_geometry.py), a class-aware
    pass/fail gate (audit_width_proof.py), retreat-first gold/black width
    enforcement in the mask stage and hidden copper channel fill/enforcement
    in the copper stage, both parallel per board. Checkpoint before a full
    pipeline run; derived artifacts and native boards are stale and several
    candidate tests still encode the previous state.
    [test_geometry_candidate.py]
2026-09-27 Complete native PCB manufacturing candidate
    Bind 43 selected boards to corrected geometry, class-aware mask and copper repairs, indexed ledgers, and refreshed visual comparisons. Keep exhaustive width certification opt-in while practical candidate tests and approved Rev5 history pass.
    [01-spider-nest-L01-black-enig-art.kicad_pcb, 01-spider-nest-L03-gold-enig-fill.kicad_pcb, 01-spider-nest-L05-gold-enig-fill.kicad_pcb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]
2026-09-27 Harden native CAM evidence failure reporting
    [test_native_cam.py]
2026-09-27 Complete native KiCad DRC and CAM verification
    [01-spider-nest-L01-black-enig-art.kicad_pcb, 01-spider-nest-L02-white-mask-only.kicad_pcb, 01-spider-nest-L03-gold-enig-fill.kicad_pcb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]
2026-09-27 Build and verify grouped lower PCB fabrication packages
    [lower-panel-black-hasl.kicad_pcb, lower-panel-green-hasl.kicad_pcb, lower-panel-red-hasl.kicad_pcb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]
2026-09-27 Build source-derived panel catalog and previews
    [artwork-gap-review.csv, artwork-minimum-gap-examples.csv, kumiko-routing-issues.csv]
2026-10-08 fix: bind portable order evidence and pin compatible KiCad
    [test_order_packages.py, test_order_profiles.py]
2026-10-09 Retain verified four-series order candidates in ordinary Git
    [01-spider-nest-L01-black-enig-art.kicad_pcb, 01-spider-nest-L02-white-mask-only.kicad_pcb, 01-spider-nest-L03-gold-enig-fill.kicad_pcb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]
2026-10-10 Archive completed four-series order and remove abandoned exports
    [01-spider-nest-L01-black-enig-art.kicad_pcb, 01-spider-nest-L02-white-mask-only.kicad_pcb, 01-spider-nest-L03-gold-enig-fill.kicad_pcb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]
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2026-10-22 manufacturing: harden Woven Maze profile checks and bundle wording
    Raise ValueError for non-object profiles and inventory entries missing
    fields, cover lower-board and extra-key mutations in tests, describe
    standalone individual bundles without V-score/scored-sheet wording
    (four-series text unchanged), and drop executable bits on new files.
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2026-10-22 manufacturing: add Woven Maze 2x2 grouped lower-sheet candidate
    Add a frozen `grouped` alternative to the woven-maze profile: standalone
    routed L01 black ENIG x25 plus two 212.6 x 198.6 mm 2x2 lead-free HASL
    sheets x25 (white L02/L04/L06/L08, black L03/L05/L07/L09), 5 mm rails,
    one copy per member, 0 blank cells, 0 surplus, 25 complete stacks.
    The validator accepts only these exact groups alongside the unchanged
    individual variant. The workflow adds the woven-maze:all pairing so
    both alternatives share one bundle and quote comparison.
    Tests cover grouped accounting, membership/grid/finish mutations, and
    built-panel geometry (translation, scores, clearances, connectivity)
    with aperture, NPTH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
2026-10-22 manufacturing: fail CI on any suite, pin panel corruption reasons
    Exit the focused regression loop on the first failing suite (the pipe
    previously reported only the last suite's status). Pin each Woven panel
    corruption test to its expected verifier message, and state per row in
    QUOTE-COMPARISON that scored-sheet quantities are sheets while
    standalone quantities are boards (four-series wording unchanged).
2026-10-22 manufacturing: add Woven Maze 2x1 split-pairs comparator
    Live JLCPCB calculator evidence showed the 2x2 grouped basket costs
    more than the individual order, so add the one bounded smaller
    comparator: standalone L01 x25 plus four 212.6 x 104.3 mm 2x1
    lead-free HASL sheets x25 (white L02/L04, L06/L08; black L03/L05,
    L07/L09). 5 lines, 125 units, 225 pieces, 0 blank, 0 surplus, 25 sets.
    The validator accepts only these exact pairs. Four-series validation
    keeps its own VARIANTS set; the new name only joins ALL_VARIANTS for
    groups_for and CLI choices. Tests cover accounting, pair/grid
    mutations, and built 2x1 sheet geometry, scores and clearances.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
